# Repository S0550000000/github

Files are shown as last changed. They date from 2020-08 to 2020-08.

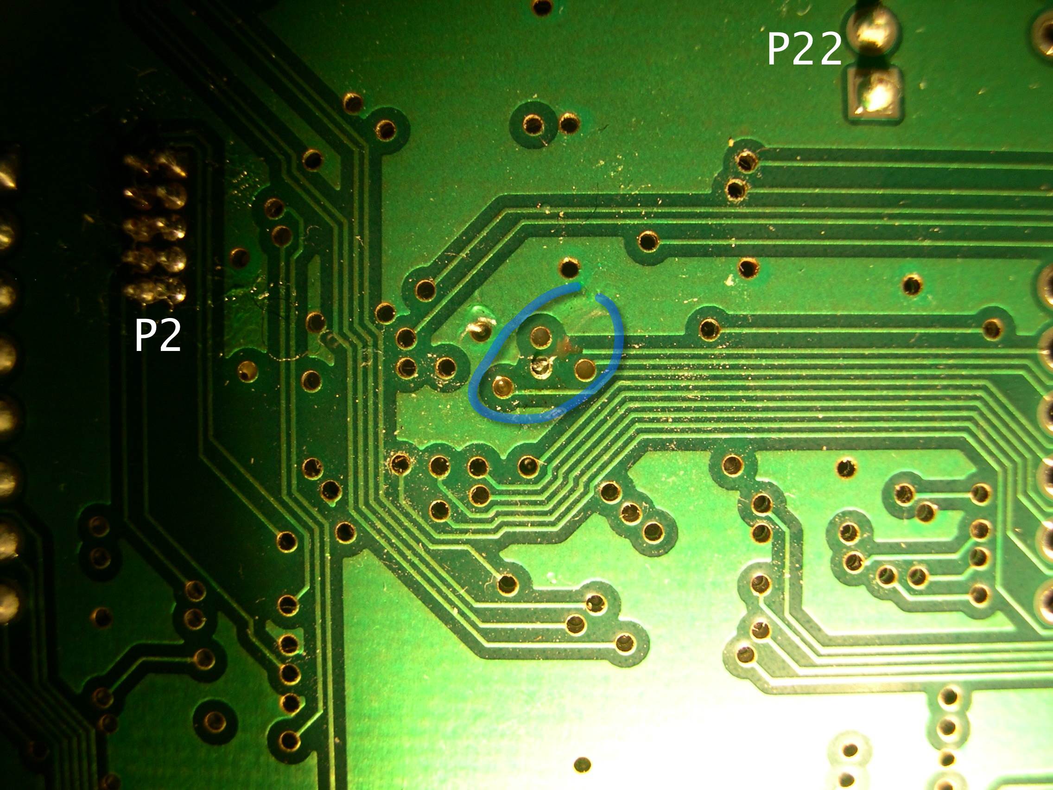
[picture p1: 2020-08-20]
doc/wiki/hardware/modifications/sgpio-p1_12-cut-trace.jpg

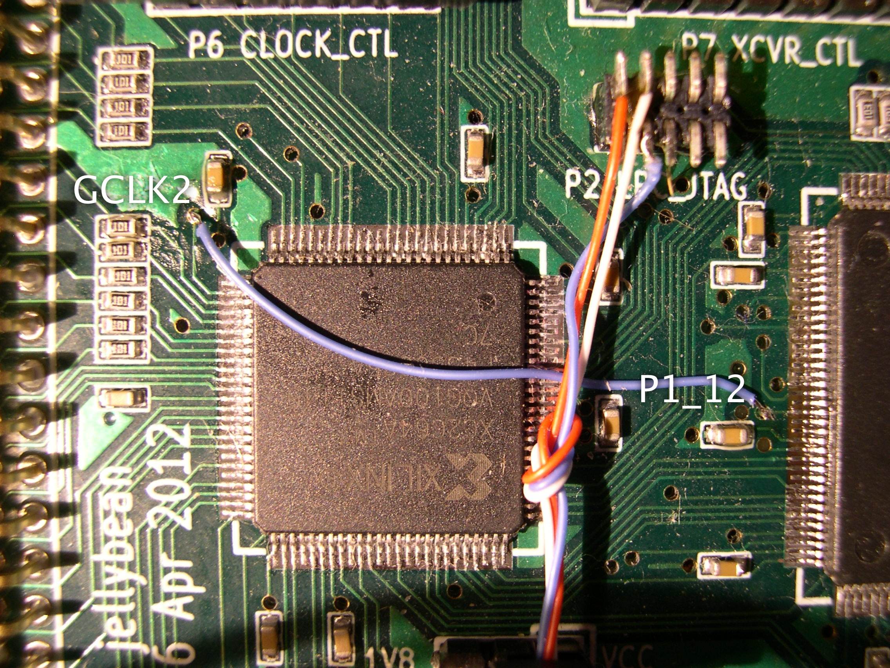
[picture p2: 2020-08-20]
doc/wiki/hardware/modifications/sgpio-gclk2-reroute.jpg

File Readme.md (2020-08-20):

This repository contains hardware designs and software for HackRF,
a low cost, open source Software Defined Radio platform.

HackRF One

(photo by fd0 from https://github.com/fd0/hackrf-one-pictures)

principal author: Michael Ossmann <mike@ossmann.com>

http://greatscottgadgets.com/hackrf/

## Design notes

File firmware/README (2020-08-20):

The primary firmware source code for USB HackRF devices is hackrf_usb.  Most of
the other directories contain firmware source code for test and development.
The common directory contains source code shared by multiple HackRF firmware
projects.  The cpld directory contains HDL source for the CPLD.

The firmware is set up for compilation with the GCC toolchain available here:

https://developer.arm.com/open-source/gnu-toolchain/gnu-rm/downloads

Required dependency:

https://github.com/mossmann/libopencm3

If you are using git, the preferred way to install libopencm3 is to use the
submodule:

$ cd ..
$ git submodule init
$ git submodule update

To build and install a standard firmware image for HackRF One:

$ cd hackrf_usb
$ mkdir build
$ cd build
$ cmake ..
$ make
$ hackrf_spiflash -w hackrf_usb.bin

If you have a Jawbreaker, add -DBOARD=JAWBREAKER to the cmake command.
If you have a rad1o, use -DBOARD=RAD1O instead.

It is possible to use a USB Device Firmware Upgrade (DFU) method to load
firmware into RAM.  This is normally only required to recover a device that has
had faulty firmware loaded, but it can also be useful for firmware developers.

For loading firmware into RAM with DFU you will need:

http://dfu-util.sourceforge.net/

To start up HackRF One in DFU mode, hold down the DFU button while powering it
on or while pressing and releasing the RESET button.  Release the DFU button
after the 3V3 LED illuminates.

A .dfu file is built by default when building firmware.  Alternatively you can
use a known good .dfu file from a release package.  Load the firmware into RAM
with:

$ dfu-util --device 1fc9:000c --alt 0 --download hackrf_usb.dfu

It is important to update the CPLD whenever you are updating firmware and a new
CPLD image is available.  See cpld/README for instructions.

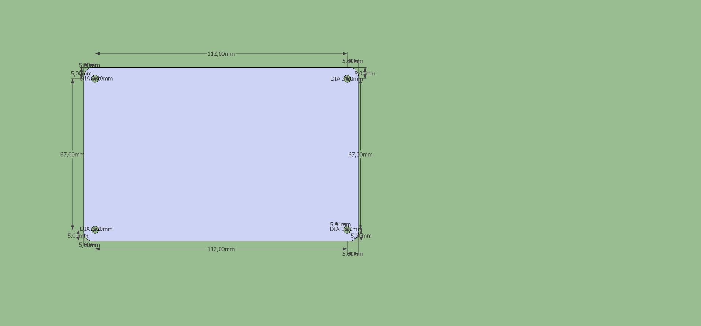
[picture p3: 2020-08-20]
hardware/hackrf-one/SoBv1_HackRF_One_16Janv2014/SoBv1_HackRF_One_Bottom2D.png

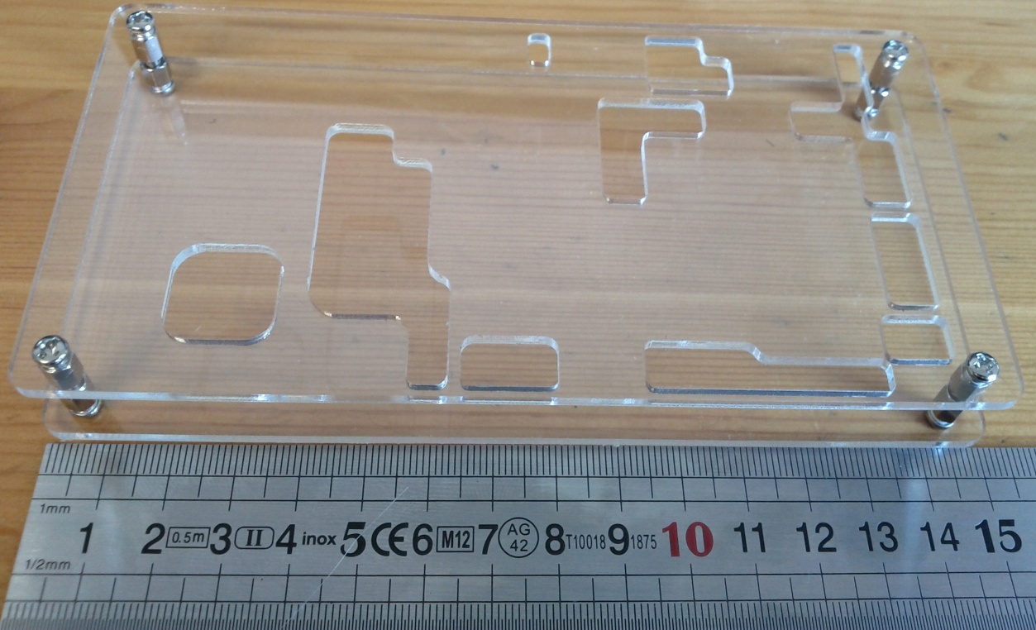
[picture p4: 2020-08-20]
hardware/jawbreaker/SoBv1_DP17298/SoBv1-DP17298-jawbreaker.jpg

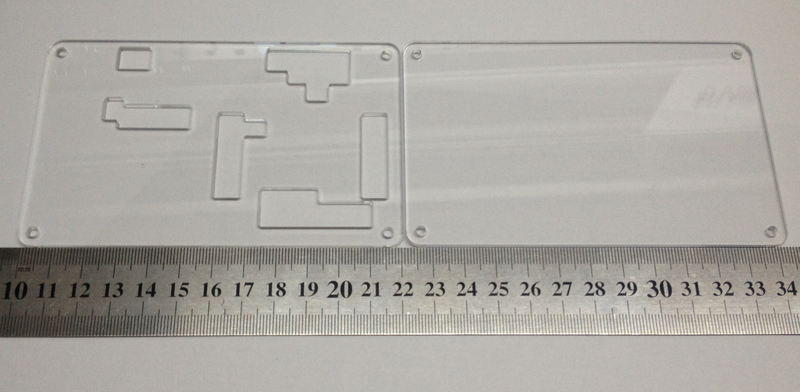
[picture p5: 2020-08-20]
hardware/hackrf-one/PlasticCase_CAD/HackRF_One_Case.png

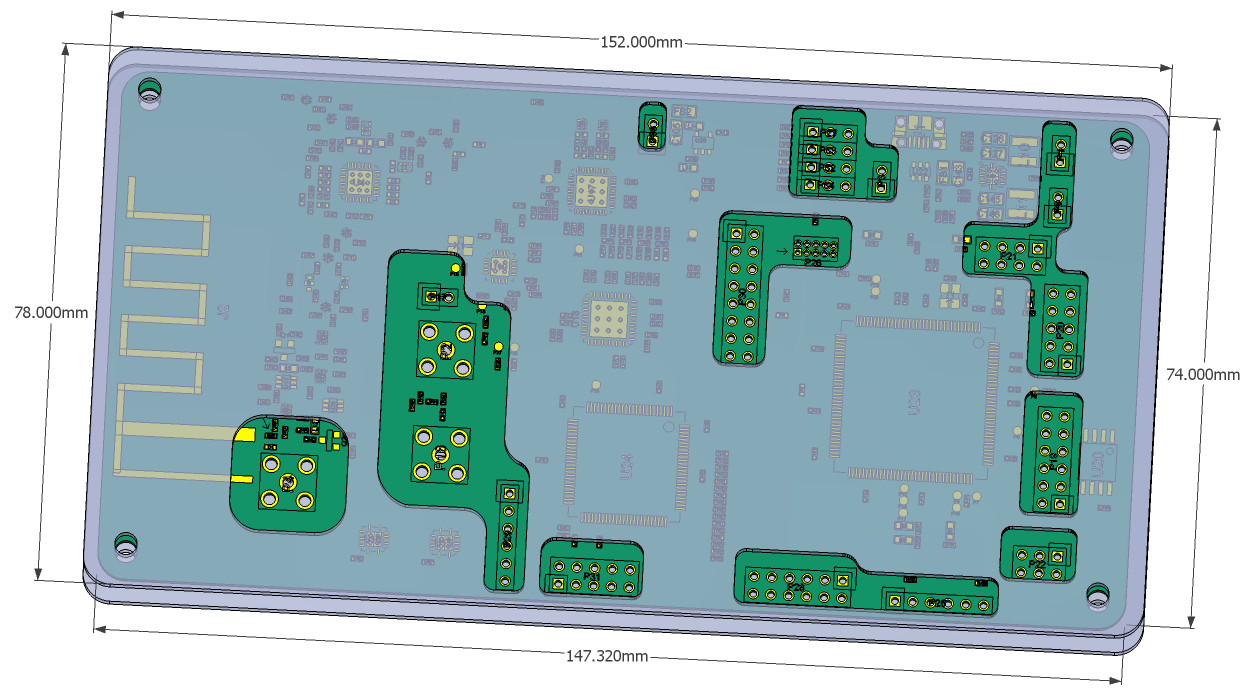
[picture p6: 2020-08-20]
hardware/jawbreaker/SoBv1_DP17298/jawbreaker_and_case.png

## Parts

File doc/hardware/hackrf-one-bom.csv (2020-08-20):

Item | Qty | Reference(s) | Value | LibPart | Footprint | Datasheet | Description | Manufacturer | Part Number
1 | 33 | C1, C3, C5, C7, C10, C11, C16, C19, C22, C24, C29, C30, C33, C34, C35, C36, C37, C38, C39, C40, C45, C47, C54, C55, C56, C57, C60, C63, C65, C66, C67, C115, C125 | 33pF | device:C |  |  | CAP CER 33PF 50V 5% NP0 0402 | Murata | GRM1555C1H330JA01D
2 | 3 | C97, C98, C100 | 330nF | device:C |  |  | CAP CER 0.33UF 10V 10% X5R 0402 | Murata | GRM155R61A334KE15D
3 | 12 | C8, C21, C32, C43, C48, C51, C84, C85, C86, C94, C99, C102 | 22pF | device:C |  |  | CAP CER 22PF 50V 5% NP0 0402 | Murata | GRM1555C1H220JA01D
4 | 2 | C104, C111 | 3pF | device:C |  |  | CAP CER 3PF 50V NP0 0402 | Murata | GRM1555C1H3R0CA01D
5 | 6 | C105, C126, C127, C143, C145, C146 | 10uF | device:C |  |  | CAP CER 10UF 10V 10% X5R 0805 | Murata | GRM21BR61A106KE19L
6 | 4 | C53, C106, C161, C171 | 1uF | device:C |  |  | CAP CER 1UF 10V 10% X5R 0402 | Taiyo Yuden | LMK105BJ105KV-F
7 | 2 | C15, C112 | 180pF | device:C |  |  | CAP CER 180PF 50V 5% NP0 0402 | Murata | GRM1555C1H181JA01D
8 | 57 | C9, C17, C18, C20, C23, C25, C28, C31, C44, C46, C49, C50, C58, C59, C61, C62, C64, C71, C73, C75, C77, C79, C81, C83, C91, C113, C119, C120, C121, C122, C123, C128, C129, C130, C131, C132, C133, C134, C135, C136, C137, C138, C139, C140, C141, C142, C144, C147, C148, C149, C150, C151, C152, C153, C154, C166, C167 | 100nF | device:C |  |  | CAP CER 0.1UF 10V 10% X5R 0402 | Murata | GRM155R61A104KA01D
9 | 1 | C114 | 3.3nF | device:C |  |  | CAP CER 3300PF 50V 10% X7R 0402 | Murata | GRM155R71H332KA01D
10 | 3 | C26, C27, C116 | 47pF | device:C |  |  | CAP CER 47PF 50V 5% NP0 0402 | Murata | GRM1555C1H470JA01D
11 | 4 | C118, C157, C158, C164 | 18pF | device:C |  |  | CAP CER 18PF 50V 5% NP0 0402 | Murata | GRM1555C1H180JA01D
12 | 2 | C12, C13 | 330pF | device:C |  |  | CAP CER 330PF 50V 10% X7R 0402 | Murata | GRM155R71H331KA01D
13 | 7 | C72, C74, C76, C78, C80, C82, C124 | 2.2uF | device:C |  |  | CAP CER 2.2UF 10V 20% X5R 0402 | Taiyo Yuden | LMK105BJ225MV-F
14 | 1 | C14 | 8p2 | device:C |  |  | CAP CER 8.2PF 50V NP0 0402 | Taiyo Yuden | UMK105CG8R2DV-F
15 | 6 | C41, C42, C52, C70, C90, C160 | 100pF | device:C |  |  | CAP CER 100PF 50V 5% NP0 0402 | Murata | GRM1555C1H101JA01D
16 | 10 | C2, C4, C6, C87, C88, C89, C92, C93, C162, C163 | 10nF | device:C |  |  | CAP CER 10000PF 16V 10% X7R 0402 | Murata | GRM155R71C103KA01D
17 | 3 | D1, D3, D9 | GSG-DIODE-TVS-BI | hackrf:GSG-DIODE-TVS-BI |  |  | TVS DIODE ESD .05PF 15KV 0402 | Murata | LXES15AAA1-100
18 | 2 | D2, D6 | TXLED | device:LED |  |  | LED SUPR RED CLR RT ANG 0805 | Lite-On | LTST-S220KRKT
19 | 2 | D4, D7 | VCCLED | device:LED |  |  | LED GREEN CLEAR RT ANG 0805 | Lite-On | LTST-S220KGKT
20 | 2 | D5, D8 | 1V8LED | device:LED |  |  | LED YELLOW CLEAR RT ANG 0805 | Lite-On | LTST-S220KSKT
21 | 3 | FB1, FB2, FB3 | FILTER | device:FILTER |  |  | FERRITE CHIP 220 OHM 2000MA 0805 | Murata | BLM21PG221SN1D
22 | 1 | J1 | USB-MICRO-B | hackrf:GSG-USB-MICRO-B-SHIELDED |  |  | CONN RCPT REV MICRO USB TYPE B | FCI | 10103592-0001LF
23 | 2 | L10, L11 | 4u7 | device:INDUCTOR |  |  | INDUCTOR 4.7UH 1.6A 20% SMD | Taiyo Yuden | NRG4026T4R7M
24 | 5 | L2, L3, L5, L12, L13 | 10uH | device:INDUCTOR |  |  | INDUCTR 10UH 220MA 20% 0603 SMD | Taiyo Yuden | BRL1608T100M
25 | 1 | L7 | 6.2nH | device:INDUCTOR |  |  | INDUCTOR HIFREQ 6.2+/-0.3NH 0402 | Taiyo Yuden | HK10056N2S-T
26 | 3 | P2, P4, P16 | ANTENNA | hackrf:GSG-RF-CONN |  |  | CONN SMA JACK 50 OHM EDGE MNT W/JAM NUT & LOCK WASHER | Molex | 73251-2121
27 | 2 | P20, P28 | SD | hackrf:CONN_11X2 |  |  | CONN HEADER FMAL 22PS.1" DL GOLD | Sullins | PPPC112LFBN-RC
28 | 1 | P22 | I2S | hackrf-one-cache:CONN_13X2 |  |  | CONN HEADER FMAL 26PS.1" DL GOLD | Sullins | PPPC132LFBN-RC
29 | 1 | P9 | BASEBAND | hackrf-one-cache:CONN_8X2 |  |  | CONN HEADER FMAL 16PS.1" DL GOLD | Sullins | PPPC082LFBN-RC
30 | 3 | Q1, Q2, Q4 | MOSFET_P | hackrf-one-cache:MOSFET_P |  |  | MOSFET P-CH 50V 130MA SOT-23 | Fairchild | BSS84
31 | 1 | Q3 | MOSFET_P | hackrf-one-cache:MOSFET_P |  |  | MOSFET P-CH 20V 4.2A SOT-23 | Diodes Inc. | DMP2305U-7
32 | 1 | Q5 | MOSFET_P | hackrf-one-cache:MOSFET_P |  |  | MOSFET P-CH -30V -4.3A SOT23 | Alpha and Omega | AO3407A
33 | 6 | R1, R2, R25, R26, R72, R75 | 470 | device:R |  |  | RES TF 1/16W 470 OHM 5% 0402 | Stackpole | RMCF0402JT470R
34 | 6 | R8, R9, R10, R13, R73, R76 | 1k | device:R |  |  | RES 1K OHM 1/16W 1% 0402 | Stackpole | RMCF0402FT1K00
35 | 22 | R19, R30, R31, R32, R33, R34, R77, R78, R79, R80, R81, R86, R87, R88, R89, R90, R91, R94, R96, R98, R99, R100 | 39 | device:R |  |  | RES 39 OHM 1/16W 5% 0402 SMD | Stackpole | RMCF0402JT39R0
36 | 26 | R5, R6, R7, R11, R12, R24, R29, R36, R37, R41, R48, R49, R51, R52, R54, R59, R63, R64, R65, R66, R67, R68, R85, R93, R104, R105 | 10k | device:R |  |  | RES 10K OHM 1/16W 5% 0402 SMD | Stackpole | RMCF0402JT10K0
37 | 4 | R14, R15, R16, R17 | 4k7 | device:R |  |  | RES 4.7K OHM 1/16W 1% 0402 | Stackpole | RMCF0402FT4K70
38 | 4 | R18, R27, R28, R74 | 1k8 | device:R |  |  | RES TF 1.8K OHM 5% 1/16W 0402 | Stackpole | RMCF0402JT1K80
39 | 7 | R20, R21, R22, R23, R57, R58, R62 | 0 | device:R |  |  | RES 0.0 OHM 1/16W 0402 SMD | Stackpole | RMCF0402ZT0R00
40 | 1 | R3 | 22k | device:R |  |  | RES 22K OHM 1/10W 5% 0402 SMD | Panasonic | ERJ-2GEJ223X
41 | 1 | R4 | 51k | device:R |  |  | RES TF 51K OHM 1% 0.0625W 0402 | Stackpole | RMCF0402FT51K0
42 | 2 | R46, R55 | 162k | device:R |  |  | RES TF 1/16W 162K OHM 1% 0402 | Stackpole | RMCF0402FT162K
43 | 1 | R47 | 330k | device:R |  |  | RES TF 1/16W 330K OHM 1% 0402 | Stackpole | RMCF0402FT330K
44 | 1 | R56 | 715k | device:R |  |  | RES TF 1/16W 715K OHM 1% 0402 | Stackpole | RMCF0402FT715K
45 | 1 | R69 | 12k | device:R |  |  | RES 12.0K OHM 1/16W 1% 0402 SMD | Rohm | MCR01MRTF1202
46 | 2 | SW1, SW2 | RESET | hackrf:SW_PUSH_SHIELDED |  |  | SWITCH TACTILE SPST-NO 0.05A 12V | TE Connectivity | FSMRA3JH
47 | 2 | T1, T2 | MIX_OUT_BALUN | hackrf:BALUN-B0310J50100AHF |  |  | Ultra Low Profile 0805 Balun 50 to 100 ohm Balanced | Anaren | B0310J50100AHF
48 | 2 | T3, T4 | TX_BALUN | hackrf:BALUN |  |  | BALUN CERAMIC CHIP WIMAX 2.5GHZ | Johanson Technology | 2500BL14M100T
49 | 7 | U1, U2, U5, U6, U7, U10, U11 | SKY13350 | hackrf:SKY13350 |  |  | 0.01-6.0 GHz GaAs SPDT Switch | Skyworks | SKY13350-385LF
50 | 3 | U9, U12, U14 | SKY13317 | hackrf:SKY13317 |  |  | 20 MHz-6.0 GHz pHEMT GaAs SP3T Switch | Skyworks | SKY13317-373LF
51 | 2 | U13, U25 | MGA-81563 | hackrf:MGA-81563 |  |  | 0.1-6 GHz 3 V, 14 dBm Amplifier | Avago | MGA-81563-TR1G
52 | 1 | U15 | LXES1TBCC2-004 | hackrf:LXES1TBCC2-004 |  |  | ESD Suppressors 0.55pF 6V 2ch | Murata | LXES1TBCC2-004
53 | 1 | U17 | MAX2837 | hackrf:MAX2837 |  |  | IC TXRX 2.3GHZ-2.7GHZ 48TQFN | Maxim | MAX2837ETM+
54 | 1 | U18 | MAX5864 | hackrf:MAX5864 |  |  | IC ANLG FRONT END 22MSPS 48-TQFN | Maxim | MAX5864ETM+
55 | 1 | U19 | SI5351C | hackrf:SI5351C |  |  | IC CLK GENERATOR 160MHZ 20QFN | Silicon Laboratories Inc | SI5351C-B-GM
56 | 1 | U20 | W25Q80BV | hackrf:W25Q80BV |  |  | IC FLASH 8MBIT 8SOIC | Winbond | W25Q80BVSSIG
57 | 1 | U21 | TPS62410 | hackrf:TPS62410 |  |  | IC BUCK SYNC DUAL ADJ 0.8A 10SON | Texas Instruments | TPS62410DRCR
58 | 1 | U23 | LPC4320FBD144 | hackrf:LPC43XXFBD144 |  |  | IC MCU 32BIT 144LQFP | NXP | LPC4320FBD144,551
59 | 1 | U24 | GSG-XC2C64A-7VQG100C | hackrf:GSG-XC2C64A-7VQG100C |  |  | IC CR-II CPLD 64MCELL 100-VQFP | Xilinx | XC2C64A-7VQG100C
60 | 1 | U3 | RX_LOWPASS_FILTER | hackrf:FIL-LP0603 |  |  | FILTER LOW PASS 1880MHZ 0603 SMD | AVX | LP0603A1880ANTR
61 | 1 | U4 | RFFC5072 | hackrf:RFFC5072 |  |  | WIDEBAND SYNTHESIZER/VCO WITH INTEGRATED 6GHz MIXER | RFMD | RFFC5072TR7
62 | 1 | U8 | RX_HIGHPASS_FILTER | hackrf:FIL-DEA |  |  | FILTER HIGHPASS WLAN&BLUETOOTH | TDK | DEA162400HT-8004B1
63 | 1 | X1 | GSG-XTAL4PIN | hackrf:GSG-XTAL4PIN |  |  | CRYSTAL 25.000MHZ 8PF SMD | AVX | CX3225GB25000D0HEQZ1
64 | 1 | X2 | MCU_XTAL | hackrf:GSG-XTAL4PIN |  |  | CRYSTAL 12.000 MHZ 12PF SMD | TXC | 7V-12.000MAAE-T
65 | 1 | X3 | RTC_XTAL | hackrf-one-cache:CRYSTAL |  |  | CRYSTAL 32.768KHZ 12.5PF SMD | Abracon | AB26TRQ-32.768KHZ-T

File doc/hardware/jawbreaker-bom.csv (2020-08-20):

ref | value | Field1 | Field2 | Field3 | Field4 | Field5 | Field6 | Field7 | Field8
C1 | 33pF | Murata | GRM1555C1H330JZ01D | CAP CER 33PF 50V 5% NP0 0402
C2 | 10nF | Murata | GRM155R71C103KA01D | CAP CER 10000PF 16V 10% X7R 0402
C3 | 33pF | Murata | GRM1555C1H330JZ01D | CAP CER 33PF 50V 5% NP0 0402
C4 | 10nF | Murata | GRM155R71C103KA01D | CAP CER 10000PF 16V 10% X7R 0402
C5 | 33pF | Murata | GRM1555C1H330JZ01D | CAP CER 33PF 50V 5% NP0 0402
C6 | 10nF | Murata | GRM155R71C103KA01D | CAP CER 10000PF 16V 10% X7R 0402
C7 | 33pF | Murata | GRM1555C1H330JZ01D | CAP CER 33PF 50V 5% NP0 0402
C8 | 47pF | Murata | GRM1555C1H470JZ01D | CAP CER 47PF 50V 5% NP0 0402
C9 | 10nF | Murata | GRM155R71C103KA01D | CAP CER 10000PF 16V 10% X7R 0402
C10 | 33pF | Murata | GRM1555C1H330JZ01D | CAP CER 33PF 50V 5% NP0 0402
C11 | 33pF | Murata | GRM1555C1H330JZ01D | CAP CER 33PF 50V 5% NP0 0402
C12 | 330pF | Murata | GRM155R71H331KA01D | CAP CER 330PF 50V 10% X7R 0402
C13 | 330pF | Murata | GRM155R71H331KA01D | CAP CER 330PF 50V 10% X7R 0402
C14 | 8p2 | Taiyo Yuden | UMK105CG8R2DV-F | CAP CER 8.2PF 50V NP0 0402
C15 | 180pF | Murata | GRM1555C1H181JA01D | CAP CER 180PF 50V 5% NP0 0402
C16 | 33pF | Murata | GRM1555C1H330JZ01D | CAP CER 33PF 50V 5% NP0 0402
C17 | 10nF | Murata | GRM155R71C103KA01D | CAP CER 10000PF 16V 10% X7R 0402
C18 | 10nF | Murata | GRM155R71C103KA01D | CAP CER 10000PF 16V 10% X7R 0402
C19 | 33pF | Murata | GRM1555C1H330JZ01D | CAP CER 33PF 50V 5% NP0 0402
C20 | 10nF | Murata | GRM155R71C103KA01D | CAP CER 10000PF 16V 10% X7R 0402
C21 | 47pF | Murata | GRM1555C1H470JZ01D | CAP CER 47PF 50V 5% NP0 0402
C22 | 33pF | Murata | GRM1555C1H330JZ01D | CAP CER 33PF 50V 5% NP0 0402
C23 | 10nF | Murata | GRM155R71C103KA01D | CAP CER 10000PF 16V 10% X7R 0402
C24 | 33pF | Murata | GRM1555C1H330JZ01D | CAP CER 33PF 50V 5% NP0 0402
C25 | 10nF | Murata | GRM155R71C103KA01D | CAP CER 10000PF 16V 10% X7R 0402
C26 | 47pF | Murata | GRM1555C1H470JZ01D | CAP CER 47PF 50V 5% NP0 0402
C27 | 47pF | Murata | GRM1555C1H470JZ01D | CAP CER 47PF 50V 5% NP0 0402
C28 | 10nF | Murata | GRM155R71C103KA01D | CAP CER 10000PF 16V 10% X7R 0402
C29 | 33pF | Murata | GRM1555C1H330JZ01D | CAP CER 33PF 50V 5% NP0 0402
C30 | 33pF | Murata | GRM1555C1H330JZ01D | CAP CER 33PF 50V 5% NP0 0402
C31 | 10nF | Murata | GRM155R71C103KA01D | CAP CER 10000PF 16V 10% X7R 0402
C32 | 47pF | Murata | GRM1555C1H470JZ01D | CAP CER 47PF 50V 5% NP0 0402
C33 | 33pF | Murata | GRM1555C1H330JZ01D | CAP CER 33PF 50V 5% NP0 0402
C34 | 33pF | Murata | GRM1555C1H330JZ01D | CAP CER 33PF 50V 5% NP0 0402
C35 | 33pF | Murata | GRM1555C1H330JZ01D | CAP CER 33PF 50V 5% NP0 0402
C36 | 33pF | Murata | GRM1555C1H330JZ01D | CAP CER 33PF 50V 5% NP0 0402
C37 | 33pF | Murata | GRM1555C1H330JZ01D | CAP CER 33PF 50V 5% NP0 0402
C38 | 33pF | Murata | GRM1555C1H330JZ01D | CAP CER 33PF 50V 5% NP0 0402
C39 | 33pF | Murata | GRM1555C1H330JZ01D | CAP CER 33PF 50V 5% NP0 0402
C40 | 33pF | Murata | GRM1555C1H330JZ01D | CAP CER 33PF 50V 5% NP0 0402
C41 | 100pF | Murata | GRM1555C1H101JZ01D | CAP CER 100PF 50V 5% NP0 0402
C42 | 100pF | Murata | GRM1555C1H101JZ01D | CAP CER 100PF 50V 5% NP0 0402
C43 | 47pF | Murata | GRM1555C1H470JZ01D | CAP CER 47PF 50V 5% NP0 0402
C44 | 10nF | Murata | GRM155R71C103KA01D | CAP CER 10000PF 16V 10% X7R 0402
C45 | 33pF | Murata | GRM1555C1H330JZ01D | CAP CER 33PF 50V 5% NP0 0402
C46 | 10nF | Murata | GRM155R71C103KA01D | CAP CER 10000PF 16V 10% X7R 0402
C47 | 33pF | Murata | GRM1555C1H330JZ01D | CAP CER 33PF 50V 5% NP0 0402
C48 | 47pF | Murata | GRM1555C1H470JZ01D | CAP CER 47PF 50V 5% NP0 0402
C49 | 10nF | Murata | GRM155R71C103KA01D | CAP CER 10000PF 16V 10% X7R 0402
C50 | 100pF | Murata | GRM1555C1H101JZ01D | CAP CER 100PF 50V 5% NP0 0402
C51 | 47pF | Murata | GRM1555C1H470JZ01D | CAP CER 47PF 50V 5% NP0 0402
C52 | 100pF | Murata | GRM1555C1H101JZ01D | CAP CER 100PF 50V 5% NP0 0402
C53 | 1uF | Taiyo Yuden | LMK105BJ105KV-F | CAP CER 1UF 10V 10% X5R 0402
C54 | 33pF | Murata | GRM1555C1H330JZ01D | CAP CER 33PF 50V 5% NP0 0402
C55 | 33pF | Murata | GRM1555C1H330JZ01D | CAP CER 33PF 50V 5% NP0 0402
C56 | 33pF | Murata | GRM1555C1H330JZ01D | CAP CER 33PF 50V 5% NP0 0402
C57 | 33pF | Murata | GRM1555C1H330JZ01D | CAP CER 33PF 50V 5% NP0 0402
C58 | 100pF | Murata | GRM1555C1H101JZ01D | CAP CER 100PF 50V 5% NP0 0402
C59 | 100pF | Murata | GRM1555C1H101JZ01D | CAP CER 100PF 50V 5% NP0 0402
C60 | 33pF | Murata | GRM1555C1H330JZ01D | CAP CER 33PF 50V 5% NP0 0402
C61 | 10nF | Murata | GRM155R71C103KA01D | CAP CER 10000PF 16V 10% X7R 0402
C62 | 100pF | Murata | GRM1555C1H101JZ01D | CAP CER 100PF 50V 5% NP0 0402
C63 | 33pF | Murata | GRM1555C1H330JZ01D | CAP CER 33PF 50V 5% NP0 0402
C64 | 10nF | Murata | GRM155R71C103KA01D | CAP CER 10000PF 16V 10% X7R 0402
C65 | 33pF | Murata | GRM1555C1H330JZ01D | CAP CER 33PF 50V 5% NP0 0402
C66 | 33pF | Murata | GRM1555C1H330JZ01D | CAP CER 33PF 50V 5% NP0 0402
C67 | 47pF | Murata | GRM1555C1H470JZ01D | CAP CER 47PF 50V 5% NP0 0402
C68 | 100nF | Murata | GRM155R61A104KA01D | CAP CER 0.1UF 10V 10% X5R 0402
C69 | 100nF | Murata | GRM155R61A104KA01D | CAP CER 0.1UF 10V 10% X5R 0402
C70 | 47pF | Murata | GRM1555C1H470JZ01D | CAP CER 47PF 50V 5% NP0 0402
C71 | 100nF | Murata | GRM155R61A104KA01D | CAP CER 0.1UF 10V 10% X5R 0402
C72 | 2.2uF | Taiyo Yuden | LMK105BJ225MV-F | CAP CER 2.2UF 10V 20% X5R 0402
C73 | 100nF | Murata | GRM155R61A104KA01D | CAP CER 0.1UF 10V 10% X5R 0402
C74 | 2.2uF | Taiyo Yuden | LMK105BJ225MV-F | CAP CER 2.2UF 10V 20% X5R 0402
C75 | 100nF | Murata | GRM155R61A104KA01D | CAP CER 0.1UF 10V 10% X5R 0402
C76 | 2.2uF | Taiyo Yuden | LMK105BJ225MV-F | CAP CER 2.2UF 10V 20% X5R 0402
C77 | 100nF | Murata | GRM155R61A104KA01D | CAP CER 0.1UF 10V 10% X5R 0402
C78 | 2.2uF | Taiyo Yuden | LMK105BJ225MV-F | CAP CER 2.2UF 10V 20% X5R 0402
C79 | 100nF | Murata | GRM155R61A104KA01D | CAP CER 0.1UF 10V 10% X5R 0402
C80 | 2.2uF | Taiyo Yuden | LMK105BJ225MV-F | CAP CER 2.2UF 10V 20% X5R 0402
C81 | 100nF | Murata | GRM155R61A104KA01D | CAP CER 0.1UF 10V 10% X5R 0402
C82 | 2.2uF | Taiyo Yuden | LMK105BJ225MV-F | CAP CER 2.2UF 10V 20% X5R 0402
C83 | 100nF | Murata | GRM155R61A104KA01D | CAP CER 0.1UF 10V 10% X5R 0402
C84 | 22pF | Murata | GRM1555C1H220JA01D | CAP CER 22PF 50V 5% NP0 0402
C85 | 22pF | Murata | GRM1555C1H220JA01D | CAP CER 22PF 50V 5% NP0 0402
C86 | 22pF | Murata | GRM1555C1H220JA01D | CAP CER 22PF 50V 5% NP0 0402
C87 | 10nF | Murata | GRM155R71C103KA01D | CAP CER 10000PF 16V 10% X7R 0402
C88 | 10nF | Murata | GRM155R71C103KA01D | CAP CER 10000PF 16V 10% X7R 0402
C89 | 10nF | Murata | GRM155R71C103KA01D | CAP CER 10000PF 16V 10% X7R 0402
C90 | 100pF | Murata | GRM1555C1H101JZ01D | CAP CER 100PF 50V 5% NP0 0402
C91 | 100nF | Murata | GRM155R61A104KA01D | CAP CER 0.1UF 10V 10% X5R 0402
C92 | 10nF | Murata | GRM155R71C103KA01D | CAP CER 10000PF 16V 10% X7R 0402
C93 | 10nF | Murata | GRM155R71C103KA01D | CAP CER 10000PF 16V 10% X7R 0402
C94 | 22pF | Murata | GRM1555C1H220JA01D | CAP CER 22PF 50V 5% NP0 0402
C95 | 22pF | Murata | GRM1555C1H220JA01D | CAP CER 22PF 50V 5% NP0 0402 | DNP
C96 | 22pF | Murata | GRM1555C1H220JA01D | CAP CER 22PF 50V 5% NP0 0402 | DNP
C97 | 330nF | Murata | GRM155R61A334KE15D | CAP CER 0.33UF 10V 10% X5R 0402
C98 | 330nF | Murata | GRM155R61A334KE15D | CAP CER 0.33UF 10V 10% X5R 0402
C99 | 22pF | Murata | GRM1555C1H220JA01D | CAP CER 22PF 50V 5% NP0 0402
C100 | 330nF | Murata | GRM155R61A334KE15D | CAP CER 0.33UF 10V 10% X5R 0402
C101 | 22pF | Murata | GRM1555C1H220JA01D | CAP CER 22PF 50V 5% NP0 0402 | DNP
C102 | 22pF | Murata | GRM1555C1H220JA01D | CAP CER 22PF 50V 5% NP0 0402
C103 | 22pF | Murata | GRM1555C1H220JA01D | CAP CER 22PF 50V 5% NP0 0402 | DNP
C104 | 3pF | Murata | GRM1555C1H3R0CA01D | CAP CER 3PF 50V NP0 0402
C105 | 10uF | Murata | GRM21BR61A106KE19L | CAP CER 10UF 10V 10% X5R 0805
C106 | 1uF | Taiyo Yuden | LMK105BJ105KV-F | CAP CER 1UF 10V 10% X5R 0402
C107 | 22pF | Murata | GRM1555C1H220JA01D | CAP CER 22PF 50V 5% NP0 0402 | DNP
C108 | 22pF | Murata | GRM1555C1H220JA01D | CAP CER 22PF 50V 5% NP0 0402 | DNP
C109 | 22pF | Murata | GRM1555C1H220JA01D | CAP CER 22PF 50V 5% NP0 0402 | DNP
C110 | 22pF | Murata | GRM1555C1H220JA01D | CAP CER 22PF 50V 5% NP0 0402 | DNP
C111 | 3pF | Murata | GRM1555C1H3R0CA01D | CAP CER 3PF 50V NP0 0402
C112 | 180pF | Murata | GRM1555C1H181JA01D | CAP CER 180PF 50V 5% NP0 0402
C113 | 100nF | Murata | GRM155R61A104KA01D | CAP CER 0.1UF 10V 10% X5R 0402
C114 | 3.3nF | Murata | GRM155R71H332KA01D | CAP CER 3300PF 50V 10% X7R 0402
C115 | 10nF | Murata | GRM155R71C103KA01D | CAP CER 10000PF 16V 10% X7R 0402
C116 | 100pF | Murata | GRM1555C1H101JZ01D | CAP CER 100PF 50V 5% NP0 0402
C117 | DNP | DNP
C118 | DNP | DNP
C119 | 100nF | Murata | GRM155R61A104KA01D | CAP CER 0.1UF 10V 10% X5R 0402
C120 | 100nF | Murata | GRM155R61A104KA01D | CAP CER 0.1UF 10V 10% X5R 0402
C121 | 100nF | Murata | GRM155R61A104KA01D | CAP CER 0.1UF 10V 10% X5R 0402
C122 | 100nF | Murata | GRM155R61A104KA01D | CAP CER 0.1UF 10V 10% X5R 0402
C123 | 100nF | Murata | GRM155R61A104KA01D | CAP CER 0.1UF 10V 10% X5R 0402
C124 | 2.2uF | Taiyo Yuden | LMK105BJ225MV-F | CAP CER 2.2UF 10V 20% X5R 0402
C125 | 33pF | Murata | GRM1555C1H330JZ01D | CAP CER 33PF 50V 5% NP0 0402
C126 | 10uF | Murata | GRM21BR61A106KE19L | CAP CER 10UF 10V 10% X5R 0805
C127 | 10uF | Murata | GRM21BR61A106KE19L | CAP CER 10UF 10V 10% X5R 0805
C128 | 100nF | Murata | GRM155R61A104KA01D | CAP CER 0.1UF 10V 10% X5R 0402
C129 | 100nF | Murata | GRM155R61A104KA01D | CAP CER 0.1UF 10V 10% X5R 0402
C130 | 100nF | Murata | GRM155R61A104KA01D | CAP CER 0.1UF 10V 10% X5R 0402
C131 | 100nF | Murata | GRM155R61A104KA01D | CAP CER 0.1UF 10V 10% X5R 0402
C132 | 100nF | Murata | GRM155R61A104KA01D | CAP CER 0.1UF 10V 10% X5R 0402
C133 | 100nF | Murata | GRM155R61A104KA01D | CAP CER 0.1UF 10V 10% X5R 0402
C134 | 100nF | Murata | GRM155R61A104KA01D | CAP CER 0.1UF 10V 10% X5R 0402
C135 | 100nF | Murata | GRM155R61A104KA01D | CAP CER 0.1UF 10V 10% X5R 0402
C136 | 100nF | Murata | GRM155R61A104KA01D | CAP CER 0.1UF 10V 10% X5R 0402
C137 | 100nF | Murata | GRM155R61A104KA01D | CAP CER 0.1UF 10V 10% X5R 0402
C138 | 100nF | Murata | GRM155R61A104KA01D | CAP CER 0.1UF 10V 10% X5R 0402
C139 | 100nF | Murata | GRM155R61A104KA01D | CAP CER 0.1UF 10V 10% X5R 0402
C140 | 100nF | Murata | GRM155R61A104KA01D | CAP CER 0.1UF 10V 10% X5R 0402
C141 | 100nF | Murata | GRM155R61A104KA01D | CAP CER 0.1UF 10V 10% X5R 0402
C142 | 100nF | Murata | GRM155R61A104KA01D | CAP CER 0.1UF 10V 10% X5R 0402
C143 | 10uF | Murata | GRM21BR61A106KE19L | CAP CER 10UF 10V 10% X5R 0805
C144 | 100nF | Murata | GRM155R61A104KA01D | CAP CER 0.1UF 10V 10% X5R 0402
C145 | 10uF | Murata | GRM21BR61A106KE19L | CAP CER 10UF 10V 10% X5R 0805
C146 | 10uF | Murata | GRM21BR61A106KE19L | CAP CER 10UF 10V 10% X5R 0805
C147 | 100nF | Murata | GRM155R61A104KA01D | CAP CER 0.1UF 10V 10% X5R 0402
C148 | 100nF | Murata | GRM155R61A104KA01D | CAP CER 0.1UF 10V 10% X5R 0402
C149 | 100nF | Murata | GRM155R61A104KA01D | CAP CER 0.1UF 10V 10% X5R 0402
C150 | 100nF | Murata | GRM155R61A104KA01D | CAP CER 0.1UF 10V 10% X5R 0402
C151 | 100nF | Murata | GRM155R61A104KA01D | CAP CER 0.1UF 10V 10% X5R 0402
C152 | 100nF | Murata | GRM155R61A104KA01D | CAP CER 0.1UF 10V 10% X5R 0402
C153 | 100nF | Murata | GRM155R61A104KA01D | CAP CER 0.1UF 10V 10% X5R 0402
C154 | 100nF | Murata | GRM155R61A104KA01D | CAP CER 0.1UF 10V 10% X5R 0402
C155 | 100pF | Murata | GRM1555C1H101JZ01D | CAP CER 100PF 50V 5% NP0 0402
C156 | 47pF | Murata | GRM1555C1H470JZ01D | CAP CER 47PF 50V 5% NP0 0402
C157 | 18pF | Murata | GRM1555C1H180JZ01D | CAP CER 18PF 50V 5% NP0 0402
C158 | 18pF | Murata | GRM1555C1H180JZ01D | CAP CER 18PF 50V 5% NP0 0402
C159 | 1uF | Murata | GRM155R61A105ME15D | CAP CER 1UF 10V 20% X5R 0402 | DNP
C160 | 100pF | Murata | GRM1555C1H101JZ01D | CAP CER 100PF 50V 5% NP0 0402
C161 | 1uF | Taiyo Yuden | LMK105BJ105KV-F | CAP CER 1UF 10V 10% X5R 0402
C162 | 10nF | Murata | GRM155R71C103KA01D | CAP CER 10000PF 16V 10% X7R 0402
C163 | 10nF | Murata | GRM155R71C103KA01D | CAP CER 10000PF 16V 10% X7R 0402
C164 | DNP | DNP
C165 | DNP | DNP
D1 | GSG-DIODE-TVS-BI | Murata | LXES15AAA1-100 | TVS DIODE ESD .05PF 15KV 0402
D2 | USBLED1 | Everlight | QTLP601C4TR | LED GREEN STD BRIGHT 0603 SMD
D3 | USBLED0 | Everlight | QTLP600CYTR | LED YLW SUPER BRIGHT 0606 SMD
D4 | LED1 | Everlight | QTLP601C4TR | LED GREEN STD BRIGHT 0603 SMD
D5 | LED2 | Everlight | QTLP600CYTR | LED YLW SUPER BRIGHT 0606 SMD
D6 | LED3 | Everlight | QTLP601CRTR | LED RED STD BRIGHT 0603 SMD
D7 | VCCLED | Everlight | QTLP601C4TR | LED GREEN STD BRIGHT 0603 SMD
D8 | 1V8LED | Everlight | QTLP600CYTR | LED YLW SUPER BRIGHT 0606 SMD
FB1 | FILTER | Murata | BLM21PG221SN1D | FERRITE CHIP 220 OHM 2000MA 0805
FB2 | FILTER | Murata | BLM21PG221SN1D | FERRITE CHIP 220 OHM 2000MA 0805
J1 | GSG-USB-MICRO-B | FCI | 10103594-0001LF | CONN RCPT STD MICRO USB TYPE B
J2 | 900MHZ-F-ANTENNA | DNP
L1 | DNP | DNP
L2 | 1uH | Taiyo Yuden | BRL1608T1R0M | INDUCTR 1.0UH 650MA 20% 0603 SMD
L3 | 1uH | Taiyo Yuden | BRL1608T1R0M | INDUCTR 1.0UH 650MA 20% 0603 SMD
L4 | DNP | DNP
L5 | 1uH | Taiyo Yuden | BRL1608T1R0M | INDUCTR 1.0UH 650MA 20% 0603 SMD
L6 | DNP | DNP
L7 | 6.2nH | Taiyo Yuden | HK10056N2S-T | INDUCTOR HIFREQ 6.2+/-0.3NH 0402
L8 | DNP | DNP
L9 | DNP | DNP
L10 | 4u7 | Taiyo Yuden | NRG4026T4R7M | INDUCTOR 4.7UH 1.6A 20% SMD
L11 | 4u7 | Taiyo Yuden | NRG4026T4R7M | INDUCTOR 4.7UH 1.6A 20% SMD
L12 | 1uH | Taiyo Yuden | BRL1608T1R0M | INDUCTR 1.0UH 650MA 20% 0603 SMD
L13 | INDUCTOR | DNP
L14 | INDUCTOR | DNP
P1 | 1V8 | DNP
P2 | CLKOUT | TE Connectivity | 2081233-1 | CONN JACK SMA PCB VERT | DNP
P3 | GND | DNP
P4 | ANTENNA | TE Connectivity | 2081233-1 | CONN JACK SMA PCB VERT
P5 | WAKEUP | DNP
P6 | TRACECLK | DNP
P7 | CTIN_4 | DNP
P8 | VCC | DNP
P9 | CTOUT_4 | DNP
P10 | CTOUT_2 | DNP
P11 | CTIN_2 | DNP
P12 | U3_RXD | DNP
P13 | U3_TXD | DNP
P14 | XCVR_CLKOUT | DNP
P15 | INTR | DNP
P16 | CLKIN | TE Connectivity | 2081233-1 | CONN JACK SMA PCB VERT | DNP
P17 | CLKIN_JMP | DNP
P18 | OEB | DNP
P19 | SPIFI | DNP
P20 | GPIO | DNP
P21 | ANALOG | DNP
P22 | I2S | DNP
P23 | DBGEN | DNP
P24 | TRST | DNP
P25 | LPC_ISP | DNP
P26 | LPC_JTAG | DNP
P27 | CONN_3 | DNP
P28 | SD | DNP
P29 | CPLD_JTAG | DNP
P30 | BANK2_AUX | DNP
P31 | BANK1_AUX | DNP
P32 | CONN_3 | DNP
P33 | CONN_3 | DNP
P34 | CONN_3 | DNP
P35 | GCK0 | DNP
P36 | VAA | DNP
P37 | SCL | DNP
P38 | SDA | DNP
P39 | SSP1_SCK | DNP
P40 | SSP1_MOSI | DNP
P41 | SSP1_MISO | DNP
Q1 | MOSFET_P | Fairchild | BSS84 | MOSFET P-CH 50V 130MA SOT-23
Q2 | MOSFET_P | Fairchild | BSS84 | MOSFET P-CH 50V 130MA SOT-23
R1 | 470 | Stackpole | RMCF0402JT470R | RES TF 1/16W 470 OHM 5% 0402
R2 | 470 | Stackpole | RMCF0402JT470R | RES TF 1/16W 470 OHM 5% 0402
R3 | 22k | Panasonic | ERJ-2GEJ223X | RES 22K OHM 1/10W 5% 0402 SMD
R4 | 51k | Stackpole | RMCF0402FT51K0 | RES TF 51K OHM 1% 0.0625W 0402
R5 | 4k7 | Stackpole | RMCF0402JT4K70 | RES 4.7K OHM 1/16W 5% 0402 SMD
R6 | 4k7 | Stackpole | RMCF0402JT4K70 | RES 4.7K OHM 1/16W 5% 0402 SMD
R7 | 10k | Stackpole | RMCF0402JT10K0 | RES 10K OHM 1/16W 5% 0402 SMD
R8 | 1k | Stackpole | RMCF0402JT1K00 | RES 1K OHM 1/16W 5% 0402 SMD
R9 | 1k | Stackpole | RMCF0402JT1K00 | RES 1K OHM 1/16W 5% 0402 SMD
R10 | 1k | Stackpole | RMCF0402JT1K00 | RES 1K OHM 1/16W 5% 0402 SMD
R11 | 39 | Stackpole | RMCF0402JT39R0 | RES 39 OHM 1/16W 5% 0402 SMD
R12 | 39 | Stackpole | RMCF0402JT39R0 | RES 39 OHM 1/16W 5% 0402 SMD
R13 | 1k | Stackpole | RMCF0402JT1K00 | RES 1K OHM 1/16W 5% 0402 SMD
R14 | 4k7 | Stackpole | RMCF0402JT4K70 | RES 4.7K OHM 1/16W 5% 0402 SMD
R15 | 4k7 | Stackpole | RMCF0402JT4K70 | RES 4.7K OHM 1/16W 5% 0402 SMD
R16 | 4k7 | Stackpole | RMCF0402JT4K70 | RES 4.7K OHM 1/16W 5% 0402 SMD
R17 | 4k7 | Stackpole | RMCF0402JT4K70 | RES 4.7K OHM 1/16W 5% 0402 SMD
R18 | 47 | DNP
R19 | 47 | DNP
R20 | 0 | Stackpole | RMCF0402ZT0R00 | RES 0.0 OHM 1/16W 0402 SMD
R21 | 0 | Stackpole | RMCF0402ZT0R00 | RES 0.0 OHM 1/16W 0402 SMD
R22 | 0 | Stackpole | RMCF0402ZT0R00 | RES 0.0 OHM 1/16W 0402 SMD
R23 | 0 | Stackpole | RMCF0402ZT0R00 | RES 0.0 OHM 1/16W 0402 SMD
R24 | 4k7 | Stackpole | RMCF0402JT4K70 | RES 4.7K OHM 1/16W 5% 0402 SMD
R25 | 475 | Stackpole | RMCF0402JT470R | RES TF 1/16W 470 OHM 5% 0402
R26 | 475 | Stackpole | RMCF0402JT470R | RES TF 1/16W 470 OHM 5% 0402
R27 | 1k8 | Stackpole | RMCF0402JT1K80 | RES TF 1.8K OHM 5% 1/16W 0402
R28 | 1k8 | Stackpole | RMCF0402JT1K80 | RES TF 1.8K OHM 5% 1/16W 0402
R29 | 4k7 | Stackpole | RMCF0402JT4K70 | RES 4.7K OHM 1/16W 5% 0402 SMD
R30 | 0 | DNP
R31 | 0 | DNP
R32 | 0 | DNP
R33 | 0 | DNP
R34 | 0 | DNP
R35 | 0 | DNP
R36 | 0 | DNP
R37 | 0 | DNP
R38 | 0 | DNP
R39 | 0 | DNP
R40 | 10k | Stackpole | RMCF0402JT10K0 | RES 10K OHM 1/16W 5% 0402 SMD | DNP
R41 | 4k7 | Stackpole | RMCF0402JT4K70 | RES 4.7K OHM 1/16W 5% 0402 SMD
R42 | 10k | Stackpole | RMCF0402JT10K0 | RES 10K OHM 1/16W 5% 0402 SMD | DNP
R43 | 10k | Stackpole | RMCF0402JT10K0 | RES 10K OHM 1/16W 5% 0402 SMD | DNP
R44 | 0 | DNP
R45 | DNP | DNP
R46 | 162k | Stackpole | RMCF0402FT162K | RES TF 1/16W 162K OHM 1% 0402
R47 | 330k | Stackpole | RMCF0402FT330K | RES TF 1/16W 330K OHM 1% 0402
R48 | 10k | Stackpole | RMCF0402JT10K0 | RES 10K OHM 1/16W 5% 0402 SMD
R49 | 10k | Stackpole | RMCF0402JT10K0 | RES 10K OHM 1/16W 5% 0402 SMD
R50 | DNP | DNP
R51 | 10k | Stackpole | RMCF0402JT10K0 | RES 10K OHM 1/16W 5% 0402 SMD
R52 | 10k | Stackpole | RMCF0402JT10K0 | RES 10K OHM 1/16W 5% 0402 SMD
R53 | DNP | DNP
R54 | 10k | Stackpole | RMCF0402JT10K0 | RES 10K OHM 1/16W 5% 0402 SMD
R55 | 162k | Stackpole | RMCF0402FT162K | RES TF 1/16W 162K OHM 1% 0402
R56 | 715k | Stackpole | RMCF0402FT715K | RES TF 1/16W 715K OHM 1% 0402
R57 | 0 | Stackpole | RMCF0402ZT0R00 | RES 0.0 OHM 1/16W 0402 SMD
R58 | 0 | Stackpole | RMCF0402ZT0R00 | RES 0.0 OHM 1/16W 0402 SMD
R59 | 10k | Stackpole | RMCF0402JT10K0 | RES 10K OHM 1/16W 5% 0402 SMD
R60 | 0 | DNP
R61 | 0 | DNP
R62 | 0 | Stackpole | RMCF0402ZT0R00 | RES 0.0 OHM 1/16W 0402 SMD
R63 | 10k | Stackpole | RMCF0402JT10K0 | RES 10K OHM 1/16W 5% 0402 SMD
R64 | 10k | Stackpole | RMCF0402JT10K0 | RES 10K OHM 1/16W 5% 0402 SMD
R65 | 10k | Stackpole | RMCF0402JT10K0 | RES 10K OHM 1/16W 5% 0402 SMD | DNP
R66 | 10k | Stackpole | RMCF0402JT10K0 | RES 10K OHM 1/16W 5% 0402 SMD
R67 | 10k | Stackpole | RMCF0402JT10K0 | RES 10K OHM 1/16W 5% 0402 SMD
R68 | 10k | Stackpole | RMCF0402JT10K0 | RES 10K OHM 1/16W 5% 0402 SMD
R69 | 12k | Rohm | MCR01MRTF1202 | RES 12.0K OHM 1/16W 1% 0402 SMD
R70 | 470 | Stackpole | RMCF0402JT470R | RES TF 1/16W 470 OHM 5% 0402
R71 | 470 | Stackpole | RMCF0402JT470R | RES TF 1/16W 470 OHM 5% 0402
R72 | 470 | Stackpole | RMCF0402JT470R | RES TF 1/16W 470 OHM 5% 0402
R73 | 470 | Stackpole | RMCF0402JT470R | RES TF 1/16W 470 OHM 5% 0402
R74 | 470 | Stackpole | RMCF0402JT470R | RES TF 1/16W 470 OHM 5% 0402
R75 | 470 | Stackpole | RMCF0402JT470R | RES TF 1/16W 470 OHM 5% 0402
R76 | 470 | Stackpole | RMCF0402JT470R | RES TF 1/16W 470 OHM 5% 0402
R77 | 39 | Stackpole | RMCF0402JT39R0 | RES 39 OHM 1/16W 5% 0402 SMD
R78 | 39 | Stackpole | RMCF0402JT39R0 | RES 39 OHM 1/16W 5% 0402 SMD
R79 | 39 | Stackpole | RMCF0402JT39R0 | RES 39 OHM 1/16W 5% 0402 SMD
R80 | 39 | Stackpole | RMCF0402JT39R0 | RES 39 OHM 1/16W 5% 0402 SMD
R81 | 39 | Stackpole | RMCF0402JT39R0 | RES 39 OHM 1/16W 5% 0402 SMD
R82 | 10k | Stackpole | RMCF0402JT10K0 | RES 10K OHM 1/16W 5% 0402 SMD | DNP
R83 | 0 | DNP
R84 | 50 | DNP
R85 | DNP | DNP
R86 | 39 | Stackpole | RMCF0402JT39R0 | RES 39 OHM 1/16W 5% 0402 SMD
R87 | 39 | Stackpole | RMCF0402JT39R0 | RES 39 OHM 1/16W 5% 0402 SMD
R88 | 39 | Stackpole | RMCF0402JT39R0 | RES 39 OHM 1/16W 5% 0402 SMD
R89 | 39 | Stackpole | RMCF0402JT39R0 | RES 39 OHM 1/16W 5% 0402 SMD
R90 | 39 | Stackpole | RMCF0402JT39R0 | RES 39 OHM 1/16W 5% 0402 SMD
R91 | 39 | Stackpole | RMCF0402JT39R0 | RES 39 OHM 1/16W 5% 0402 SMD
R92 | 50 | DNP
R93 | 10k | Stackpole | RMCF0402JT10K0 | RES 10K OHM 1/16W 5% 0402 SMD
R94 | 39 | Stackpole | RMCF0402JT39R0 | RES 39 OHM 1/16W 5% 0402 SMD
R96 | 39 | Stackpole | RMCF0402JT39R0 | RES 39 OHM 1/16W 5% 0402 SMD
R97 | 39 | Stackpole | RMCF0402JT39R0 | RES 39 OHM 1/16W 5% 0402 SMD | DNP
R98 | 39 | Stackpole | RMCF0402JT39R0 | RES 39 OHM 1/16W 5% 0402 SMD
R99 | 39 | Stackpole | RMCF0402JT39R0 | RES 39 OHM 1/16W 5% 0402 SMD
R100 | 39 | Stackpole | RMCF0402JT39R0 | RES 39 OHM 1/16W 5% 0402 SMD
R104 | 4k7 | Stackpole | RMCF0402JT4K70 | RES 4.7K OHM 1/16W 5% 0402 SMD
R105 | 4k7 | Stackpole | RMCF0402JT4K70 | RES 4.7K OHM 1/16W 5% 0402 SMD
T1 | MIX_IN_BALUN | Anaren | B0310J50100AHF | Ultra Low Profile 0805 Balun 50 to 100 ohm Balanced
T2 | MIX_OUT_BALUN | Anaren | B0310J50100AHF | Ultra Low Profile 0805 Balun 50 to 100 ohm Balanced
T3 | RX_BALUN | Johanson Technology | 2500BL14M100T | BALUN CERAMIC CHIP WIMAX 2.5GHZ
T4 | TX_BALUN | Johanson Technology | 2500BL14M100T | BALUN CERAMIC CHIP WIMAX 2.5GHZ
U1 | SKY13350 | Skyworks | SKY13350-385LF | 0.01-6.0 GHz GaAs SPDT Switch
U2 | SKY13350 | Skyworks | SKY13350-385LF | 0.01-6.0 GHz GaAs SPDT Switch
U3 | RX_LOWPASS_FILTER | AVX | LP0603A1880ANTR | FILTER LOW PASS 1880MHZ 0603 SMD
U4 | RFFC5072 | RFMD | RFFC5072TR7 | WIDEBAND SYNTHESIZER/VCO WITH INTEGRATED 6GHz MIXER
U5 | SKY13350 | Skyworks | SKY13350-385LF | 0.01-6.0 GHz GaAs SPDT Switch
U6 | SKY13350 | Skyworks | SKY13350-385LF | 0.01-6.0 GHz GaAs SPDT Switch
U7 | SKY13350 | Skyworks | SKY13350-385LF | 0.01-6.0 GHz GaAs SPDT Switch
U8 | RX_HIGHPASS_FILTER | TDK | DEA162400HT-8004B1 | FILTER HIGHPASS WLAN&BLUETOOTH
U9 | SKY13317 | Skyworks | SKY13317-373LF | 20 MHz-6.0 GHz pHEMT GaAs SP3T Switch
U10 | SKY13350 | Skyworks | SKY13350-385LF | 0.01-6.0 GHz GaAs SPDT Switch
U11 | SKY13350 | Skyworks | SKY13350-385LF | 0.01-6.0 GHz GaAs SPDT Switch
U12 | SKY13317 | Skyworks | SKY13317-373LF | 20 MHz-6.0 GHz pHEMT GaAs SP3T Switch
U13 | MGA-81563 | Avago | MGA-81563-TR1G | 0.1-6 GHz 3 V, 14 dBm Amplifier
U14 | SKY13317 | Skyworks | SKY13317-373LF | 20 MHz-6.0 GHz pHEMT GaAs SP3T Switch
U15 | GSG-74HC04 | Texas Instruments | SN74AHC04RGYR | IC HEX INVERTERS 14-QFN
U16 | GSG-74HC08 | Texas Instruments | SN74AHC08RGYR | IC QUAD 2IN POS-AND GATE 14-QFN
U17 | MAX2837 | Maxim | MAX2837ETM+ | IC TXRX 2.3GHZ-2.7GHZ 48TQFN
U18 | MAX5864 | Maxim | MAX5864ETM+ | IC ANLG FRONT END 22MSPS 48-TQFN
U19 | SI5351C | Silicon Laboratories Inc | SI5351C-B-GM | IC CLK GENERATOR 160MHZ 20QFN
U20 | W25Q80BV | Winbond | W25Q80BVSSIG | IC FLASH 8MBIT 8SOIC
U21 | TPS62410 | Texas Instruments | TPS62410DRCR | IC BUCK SYNC DUAL ADJ 0.8A 10SON
U22 | GSG-IP4220CZ6 | NXP | IP4220CZ6,125 | IC USB DUAL ESD PROTECT 6TSOP
U23 | LPC43XXFBD144 | NXP | LPC4330FBD144,551 | IC MCU 32BIT 144LQFP
U24 | GSG-XC2C64A-7VQG100C | Xilinx | XC2C64A-7VQG100C | IC CR-II CPLD 64MCELL 100-VQFP
U25 | MGA-81563 | Avago | MGA-81563-TR1G | 0.1-6 GHz 3 V, 14 dBm Amplifier
U26 | RF LDO | DNP
X1 | GSG-XTAL4PIN | AVX | CX3225GB25000D0HEQZ1 | CRYSTAL 25.000MHZ 8PF SMD
X2 | MCU_XTAL | TXC | 7V-12.000MAAE-T | CRYSTAL 12.000 MHZ 12PF SMD

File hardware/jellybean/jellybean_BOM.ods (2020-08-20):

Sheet: JellyBean_BOM
Ref | Value | Manufacturer | Footprint | Details | DigiKey Quantity | DigiKey PN
R1 | 0 | Panasonic | ERJ-3GEY0R00V | RES 0.0 OHM 1/10W 0603 SMD | 2 | P0.0GCT-ND
R2 | 0 | Panasonic | ERJ-3GEY0R00V | RES 0.0 OHM 1/10W 0603 SMD
R18 | 100 | Panasonic | ERJ-3GEYJ101V | RES 100 OHM 1/10W 5% 0603 SMD | 10 | P100GCT-ND
R19 | 100 | Panasonic | ERJ-3GEYJ101V | RES 100 OHM 1/10W 5% 0603 SMD
R20 | 100 | Panasonic | ERJ-3GEYJ101V | RES 100 OHM 1/10W 5% 0603 SMD
R21 | 100 | Panasonic | ERJ-3GEYJ101V | RES 100 OHM 1/10W 5% 0603 SMD
R22 | 100 | Panasonic | ERJ-3GEYJ101V | RES 100 OHM 1/10W 5% 0603 SMD
R23 | 100 | Panasonic | ERJ-3GEYJ101V | RES 100 OHM 1/10W 5% 0603 SMD
R24 | 100 | Panasonic | ERJ-3GEYJ101V | RES 100 OHM 1/10W 5% 0603 SMD
R25 | 100 | Panasonic | ERJ-3GEYJ101V | RES 100 OHM 1/10W 5% 0603 SMD
R26 | 100 | Panasonic | ERJ-3GEYJ101V | RES 100 OHM 1/10W 5% 0603 SMD
R27 | 100 | Panasonic | ERJ-3GEYJ101V | RES 100 OHM 1/10W 5% 0603 SMD
R12 | 470 | Panasonic | ERJ-3GEYJ471V | RES 470 OHM 1/10W 5% 0603 SMD | 7 | P470GCT-ND
R13 | 470 | Panasonic | ERJ-3GEYJ471V | RES 470 OHM 1/10W 5% 0603 SMD
R15 | 470 | Panasonic | ERJ-3GEYJ471V | RES 470 OHM 1/10W 5% 0603 SMD
R29 | 470 | Panasonic | ERJ-3GEYJ471V | RES 470 OHM 1/10W 5% 0603 SMD
R3 | 470 | Panasonic | ERJ-3GEYJ471V | RES 470 OHM 1/10W 5% 0603 SMD
R8 | 470 | Panasonic | ERJ-3GEYJ471V | RES 470 OHM 1/10W 5% 0603 SMD
R9 | 470 | Panasonic | ERJ-3GEYJ471V | RES 470 OHM 1/10W 5% 0603 SMD
R30 | 1k8 | Panasonic | ERJ-3GEYJ182V | RES 1.8K OHM 1/10W 5% 0603 SMD | 2 | P1.8KGCT-ND
R31 | 1k8 | Panasonic | ERJ-3GEYJ182V | RES 1.8K OHM 1/10W 5% 0603 SMD
R16 | 10k | Panasonic | ERJ-3GEYJ103V | RES 10K OHM 1/10W 5% 0603 SMD | 13 | P10KGCT-ND
R17 | 10k | Panasonic | ERJ-3GEYJ103V | RES 10K OHM 1/10W 5% 0603 SMD
R28 | 10k | Panasonic | ERJ-3GEYJ103V | RES 10K OHM 1/10W 5% 0603 SMD
R32 | 10k | Panasonic | ERJ-3GEYJ103V | RES 10K OHM 1/10W 5% 0603 SMD
R39 | 10k | Panasonic | ERJ-3GEYJ103V | RES 10K OHM 1/10W 5% 0603 SMD
R4 | 10k | Panasonic | ERJ-3GEYJ103V | RES 10K OHM 1/10W 5% 0603 SMD
R40 | 10k | Panasonic | ERJ-3GEYJ103V | RES 10K OHM 1/10W 5% 0603 SMD
R41 | 10k | Panasonic | ERJ-3GEYJ103V | RES 10K OHM 1/10W 5% 0603 SMD
R42 | 10k | Panasonic | ERJ-3GEYJ103V | RES 10K OHM 1/10W 5% 0603 SMD
R43 | 10k | Panasonic | ERJ-3GEYJ103V | RES 10K OHM 1/10W 5% 0603 SMD
R5 | 10k | Panasonic | ERJ-3GEYJ103V | RES 10K OHM 1/10W 5% 0603 SMD
R6 | 10k | Panasonic | ERJ-3GEYJ103V | RES 10K OHM 1/10W 5% 0603 SMD
R7 | 10k | Panasonic | ERJ-3GEYJ103V | RES 10K OHM 1/10W 5% 0603 SMD
R14 | 12k | Panasonic | ERJ-3EKF1202V | RES 12.0K OHM 1/10W 1% 0603 SMD | 1 | P12.0KHCT-ND
R10 | 15k | Panasonic | ERJ-3GEYJ153V | RES 15K OHM 1/10W 5% 0603 SMD | 1 | P15KGCT-ND
R11 | 33k | Panasonic | ERJ-3GEYJ333V | RES 33K OHM 1/10W 5% 0603 SMD | 1 | P33KGCT-ND
R36 | 160k+560k in parallel (to obtain 3,3V instead of 2.7V) | Panasonic | ERJ-3EKF1603V | RES 160K OHM 1/10W 1% 0603 SMD | 1 | P160KHCT-ND
R35 | 180k | Panasonic | ERJ-3EKF1803V | RES 180K OHM 1/10W 1% 0603 SMD | 1 | P180KHCT-ND
R37 | 360k | Panasonic | ERJ-3EKF3603V | RES 360K OHM 1/10W 1% 0603 SMD | 1 | P360KHCT-ND
R38 | 560k | Panasonic | ERJ-3EKF5603V | RES 560K OHM 1/10W 1% 0603 SMD | 2 | P560KHCT-ND
C24 | 22pF | Murata | GRM1885C1H220JA01D | CAP CER 22PF 50V 5% NP0 0603 | 10 | 490-1411-1-ND
C18 | 47pF | Murata | GRM1885C1H470JA01D | CAP CER 47PF 50V 5% NP0 0603 | 10 | 490-1419-1-ND
C1 | 100nF | Murata | GRM188R71C104KA01D | CAP CER 0.1UF 16V 10% X7R 0603 | 30 | 490-1532-1-ND
C10 | 100nF | Murata | GRM188R71C104KA01D | CAP CER 0.1UF 16V 10% X7R 0603
C11 | 100nF | Murata | GRM188R71C104KA01D | CAP CER 0.1UF 16V 10% X7R 0603
C12 | 100nF | Murata | GRM188R71C104KA01D | CAP CER 0.1UF 16V 10% X7R 0603
C13 | 100nF | Murata | GRM188R71C104KA01D | CAP CER 0.1UF 16V 10% X7R 0603
C14 | 100nF | Murata | GRM188R71C104KA01D | CAP CER 0.1UF 16V 10% X7R 0603
C15 | 100nF | Murata | GRM188R71C104KA01D | CAP CER 0.1UF 16V 10% X7R 0603
C17 | 100nF | Murata | GRM188R71C104KA01D | CAP CER 0.1UF 16V 10% X7R 0603
C19 | 100nF | Murata | GRM188R71C104KA01D | CAP CER 0.1UF 16V 10% X7R 0603
C2 | 100nF | Murata | GRM188R71C104KA01D | CAP CER 0.1UF 16V 10% X7R 0603
C20 | 100nF | Murata | GRM188R71C104KA01D | CAP CER 0.1UF 16V 10% X7R 0603
C22 | 100nF | Murata | GRM188R71C104KA01D | CAP CER 0.1UF 16V 10% X7R 0603
C23 | 100nF | Murata | GRM188R71C104KA01D | CAP CER 0.1UF 16V 10% X7R 0603
C25 | 100nF | Murata | GRM188R71C104KA01D | CAP CER 0.1UF 16V 10% X7R 0603
C26 | 100nF | Murata | GRM188R71C104KA01D | CAP CER 0.1UF 16V 10% X7R 0603
C29 | 100nF | Murata | GRM188R71C104KA01D | CAP CER 0.1UF 16V 10% X7R 0603
C3 | 100nF | Murata | GRM188R71C104KA01D | CAP CER 0.1UF 16V 10% X7R 0603
C32 | 100nF | Murata | GRM188R71C104KA01D | CAP CER 0.1UF 16V 10% X7R 0603
C33 | 100nF | Murata | GRM188R71C104KA01D | CAP CER 0.1UF 16V 10% X7R 0603
C4 | 100nF | Murata | GRM188R71C104KA01D | CAP CER 0.1UF 16V 10% X7R 0603
C5 | 100nF | Murata | GRM188R71C104KA01D | CAP CER 0.1UF 16V 10% X7R 0603
C7 | 100nF | Murata | GRM188R71C104KA01D | CAP CER 0.1UF 16V 10% X7R 0603
C8 | 100nF | Murata | GRM188R71C104KA01D | CAP CER 0.1UF 16V 10% X7R 0603
C9 | 100nF | Murata | GRM188R71C104KA01D | CAP CER 0.1UF 16V 10% X7R 0603
C16 | 100pF | Murata | GRM1885C1H101JA01D | CAP CER 100PF 50V 5% NP0 0603 | 10 | 490-1427-1-ND
C6 | 4u7 | Taiyo Yuden | LMK212BJ475KD-T | CAP CER 4.7UF 10V 10% X5R 0805 | 1 | 587-1297-1-ND
C21 | 10uF | Murata | GRM21BR61A106KE19L | CAP CER 10UF 10V 10% X5R 0805 | 10 | 490-1709-1-ND
C27 | 10uF | Murata | GRM21BR61A106KE19L | CAP CER 10UF 10V 10% X5R 0805
C28 | 10uF | Murata | GRM21BR61A106KE19L | CAP CER 10UF 10V 10% X5R 0805
C30 | 10uF | Murata | GRM21BR61A106KE19L | CAP CER 10UF 10V 10% X5R 0805
C31 | 10uF | Murata | GRM21BR61A106KE19L | CAP CER 10UF 10V 10% X5R 0805
L1 | 4u7 | Taiyo Yuden | NRG4026T4R7M | INDUCTOR 4.7UH 1.6A 20% SMD | 2 | 587-2382-1-ND
L2 | 4u7 | Taiyo Yuden | NRG4026T4R7M | INDUCTOR 4.7UH 1.6A 20% SMD
FB1 | FILTER | Murata | BLM21PG221SN1D | FERRITE CHIP 220 OHM 2000MA 0805 | 1 | 490-1054-1-ND
U1 | GSG-IP4220CZ6 | NXP | IP4220CZ6,125 | IC USB DUAL ESD PROTECT 6TSOP | 1 | 568-3529-1-ND
J1 | GSG-USB-MICRO-B | FCI | 10103594-0001LF | CONN RCPT STD MICRO USB TYPE B | 1 | 609-4050-1-ND
U4 | GSG-XC2C64A-7VQG100C | Xilinx | XC2C64A-7VQG100C | IC CR-II CPLD 64MCELL 100-VQFP | 1 | 122-1409-ND
U2 | LPC43XXFBD144 | NXP | LPC4330FBD144,551 | IC MCU 32BIT 144LQFP | 1 | 568-9450-ND
U5 | TPS62410 | Texas Instruments | TPS62410DRCR | IC BUCK SYNC DUAL ADJ 0.8A 10SON | 1 | 296-25488-1-ND
D3 | LED3 | Everlight | QTLP601CRTR | LED RED STD BRIGHT 0603 SMD | 1 | 1080-1407-1-ND
D5 | 1V8LED | Everlight | QTLP600CYTR | LED YLW SUPER BRIGHT 0606 SMD | 3 | 1080-1404-1-ND
D2 | LED2 | Everlight | QTLP600CYTR | LED YLW SUPER BRIGHT 0606 SMD
D7 | USBLED0 | Everlight | QTLP600CYTR | LED YLW SUPER BRIGHT 0606 SMD
D1 | LED1 | Everlight | QTLP601C4TR | LED GREEN STD BRIGHT 0603 SMD | 3 | 1080-1405-1-ND
D6 | USBLED1 | Everlight | QTLP601C4TR | LED GREEN STD BRIGHT 0603 SMD
D4 | VCCLED | Everlight | QTLP601C4TR | LED GREEN STD BRIGHT 0603 SMD
U3 | W25Q80BV | Winbond | W25Q80BVSSIG | IC FLASH 8MBIT 8SOIC | 1 | W25Q80BVSSIG-ND
P2 | LPC_JTAG | Samtec Inc | EHF-105-01-L-D | CONN HEADER .05" 10POS DUAL T/H | 1 | SAM8205-ND
P16 | 1V8
P13 | ADC/DAC
P1 | ANALOG
P10 | BANK1_AUX
P22 | BANK1_PWR
P8 | BANK2_AUX
P4 | BOOT0
P19 | BOOT1
P20 | BOOT2
P21 | BOOT3
P6 | CLOCK_CTL
P18 | CPLD_JTAG
R33 | DNP
R34 | DNP
P5 | GPIO
P15 | I2S
P14 | LPC_ISP
P3 | LPC_MISC
P12 | SD
P9 | SPI
P11 | SPIFI
P7 | XCVR_CTL
P17 | VCC

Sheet: ImportPart_DigiKey
2,P0.0GCT-ND
10,P100GCT-ND
7,P470GCT-ND
2,P1.8KGCT-ND
13,P10KGCT-ND
1,P12.0KHCT-ND
1,P15KGCT-ND
1,P33KGCT-ND
1,P160KHCT-ND
1,P180KHCT-ND
1,P360KHCT-ND
2,P560KHCT-ND
10,490-1411-1-ND
10,490-1419-1-ND
30,490-1532-1-ND
10,490-1427-1-ND
1,587-1297-1-ND
10,490-1709-1-ND
2,587-2382-1-ND
1,490-1054-1-ND
1,568-3529-1-ND
1,609-4050-1-ND
1,122-1409-ND
1,568-9450-ND
1,296-25488-1-ND
1,1080-1407-1-ND
3,1080-1404-1-ND
3,1080-1405-1-ND
1,W25Q80BVSSIG-ND
1,SAM8205-ND

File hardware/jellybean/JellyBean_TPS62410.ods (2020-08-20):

 | TPS62410 VCC |  | TPS62410 1V8
R36 (OHM) | 160000 | R35 (OHM) | 180000
R38 (OHM) | 560000 | R37 (OHM) | 360000
 | VCC (Converter1) |  | 1V8
Out Voltage | 2,7 | Out Voltage | 1,8
After Fix 3.3V
 | TPS62410 VCC
R36 (OHM) | 124444 | 160KOHM in // with 560KOHM
R38 (OHM) | 560000
 | VCC (Converter1)
Out Voltage | 3,3

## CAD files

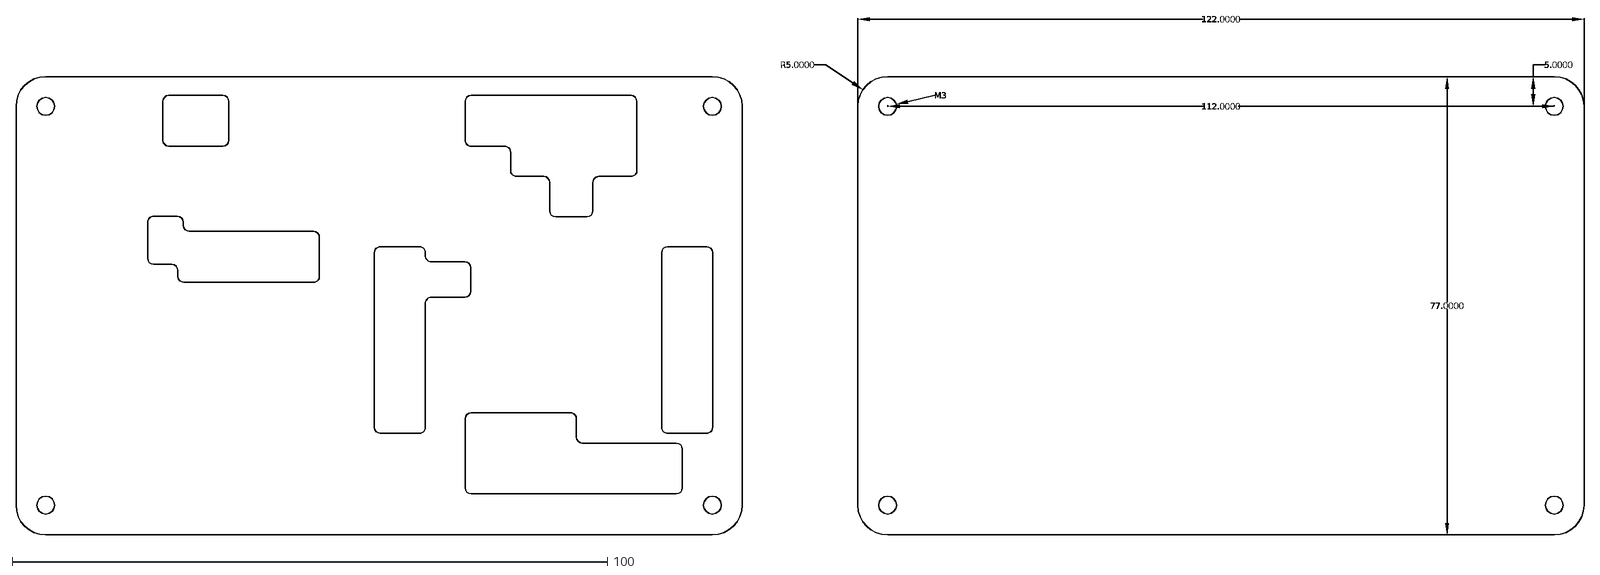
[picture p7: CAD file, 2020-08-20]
hardware/hackrf-one/PlasticCase_CAD/HackRF_One_Case.dxf
5.0000
M3
112.0000
122.0000
77.0000
R5.0000

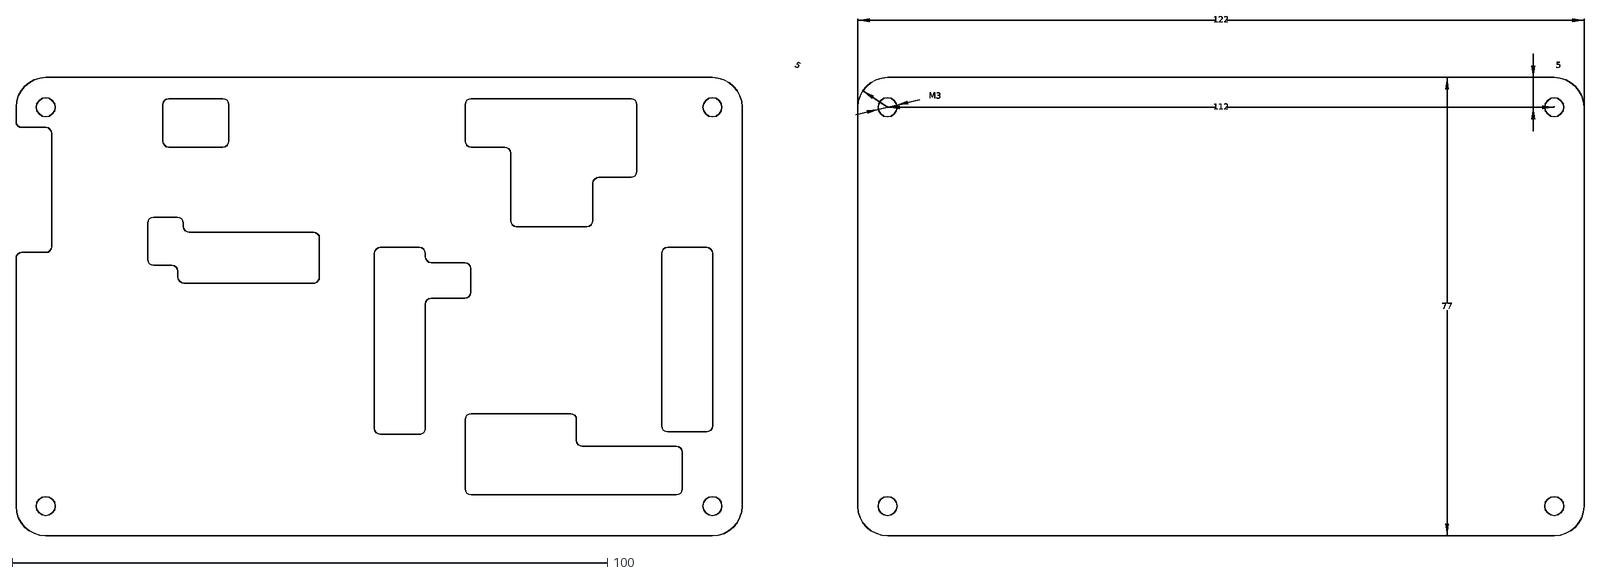
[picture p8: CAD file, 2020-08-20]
hardware/hackrf-one/PlasticCase_CAD/HackRF_One_Case_With_Button_CutOuts.dxf
5
M3
112
122
77

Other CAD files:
hardware/hackrf-one/SoBv1_HackRF_One_16Janv2014/SoBv1_HackRF_One_Bottom2D.skp
hardware/hackrf-one/SoBv1_HackRF_One_16Janv2014/SoBv1_HackRF_One_Top2D+HackRF_OneTOP.skp
hardware/hackrf-one/SoBv1_HackRF_One_16Janv2014/SoBv1_HackRF_One_Top2D.skp
hardware/jawbreaker/SoBv1_DP17298/SoBv1-DP17298-jawbreaker-Bottom.skp
hardware/jawbreaker/SoBv1_DP17298/SoBv1-DP17298-jawbreaker-Top.skp

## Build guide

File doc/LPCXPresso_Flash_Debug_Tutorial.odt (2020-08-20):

# LPCXpresso Flash/Debug Tutorial

# Hardware required

1) NXP LPC-Link board included with any LPCXPRESSO Board (for 20Euros) from Embedded Artists see http://www.embeddedartists.com/products/lpcxpresso

To separate the LPC-LINK side and the target side (required to use the debugger JTAG/SWD) on an other board), see document:

http://www.embeddedartists.com/sites/default/files/docs/HowToCreateAnLPC-LINK.pdf

The suggested LPCXpresso boards are LPC11U14, LPC1227 and LPC1769 which just need the use of desoldering braid to remove the solder bumps, for other board it is required to cut some wires.

For my Example I use a LPCXPresso LPC1769 board.

2) LPC43xx board in this tutorial I will use the HackRF board called JellyBean designed by Michael Ossmann (thanks for this amazing board ;-).
For this tutorial HackRF JellyBean board is used and example used is miniblink based on GitHub https://github.com/mossmann/libopencm3/tree/master/examples/lpc43xx/hackrf-jellybean/miniblink

Main GitHub is https://github.com/mossmann/libopencm3

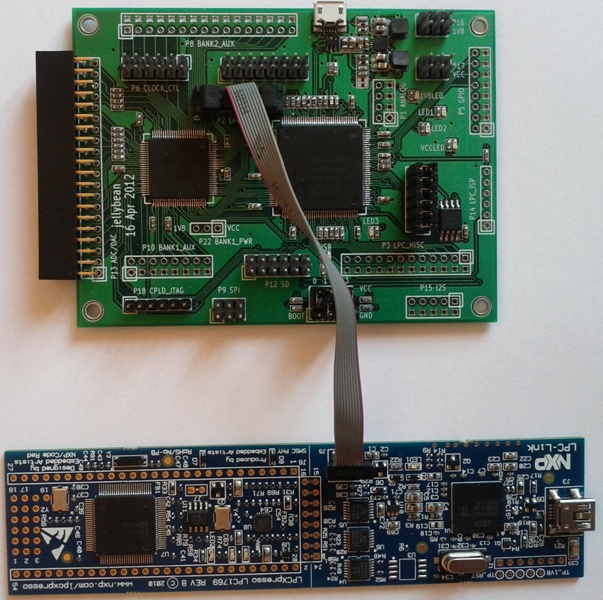
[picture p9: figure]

Nota: Pin1 is Red Pin on the 10-pin mini JTAG cable.

Nota I bought the mini JTAG cable at Embedded Artists here: http://www.embeddedartists.com/products/acc/acc_idc_10.php

# Software required

LPCXpresso v4.2.3 build 292 (size 213.4 MB):

Requires an account (Login/Password).

Windows version:

http://lpcxpresso.code-red-tech.com/LPCXpresso/system/files/LPCXpresso_4.2.3_292.exe

or

ftp://lpcxpresso.code-red-tech.com/LPCXpresso_4.2.3_292.exe

Linux version:

http://lpcxpresso.code-red-tech.com/LPCXpresso/system/files/Installer_LPCXpresso_4.2.3_255_Linux-x86.tar_.gz

Nota: Tutorial is done with Windows XP SP3 and LPCXpresso v4.2.3 build 292 for windows.

# Starting LPCXpresso IDE

Before starting LPCXpresso you should register it (registration code shall be activated online with the card you will receive with your LPCXPRESSO Board), the registered version is only limited to debug code of max 128KB.

## Create a project

Choose Menu File->New->Project

Select C/C++ & LPCXpresso C project and click Next

Select NXP LPC4300 -> C Project (Cortex M4) and click Next

Choose project Name in the example hackrf_jellybean and click Next

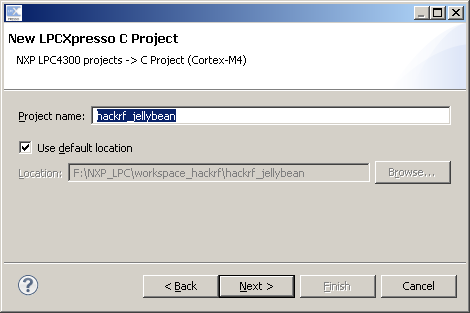
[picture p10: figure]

In Target Selection choose LPC4330 (for JellyBean) and click Next

For CMSIS DSP or Library just choose None for both and click Next

Just change C Dialect to gnu99 or what you prefer and click Finish

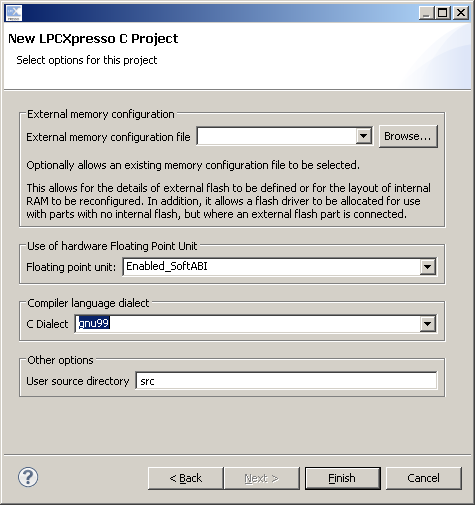
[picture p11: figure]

A basic project is now created.

You can import existing source project using link:

With mouse right click on project, choose New -> Folder

In Folder name: Enter the full path in the example hackrf-jellybean

Then click on Advanced and choose "Link to alternate location (Linked Folder)

And choose the full path in the example F:\SVN\libopencm3_TitanMKD\examples\lpc43xx\hackrf-jellybean

Then click on Finish.

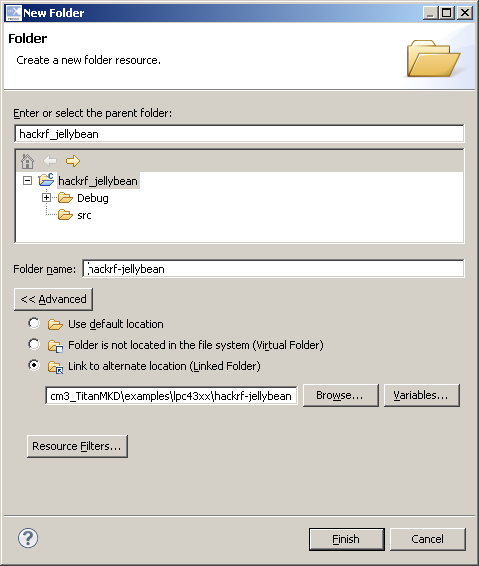
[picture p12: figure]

Now you have access to you external source from LPCXpresso IDE.

## Flashing ".bin" or ".elf" in SPIFI flash memory

With mouse click on project hackrf-jellybean previously created and click on the "Chip/Component" Icon

Configure Flash with following parameters:

1) Choose Flash driver file (using Flash driver Browse) in Default Installation path \LPCXpresso_4.2.3_292\lpcxpresso\bin\Flash\LPC1850A_4350A_SPIFI.cfx

2) Select the file to write in flash in our example F:\SVN\libopencm3_TitanMKD\examples\lpc43xx\hackrf-jellybean\miniblink\miniblink.bin

3) Choose base address: 0x14000000

Click OK to start.

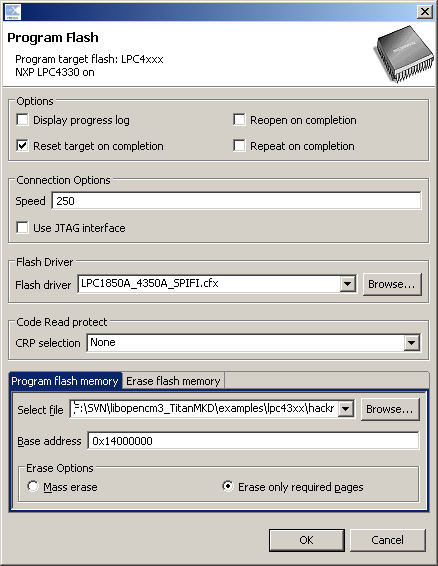
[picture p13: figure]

Progress shall be displayed and all disappear when it is finished

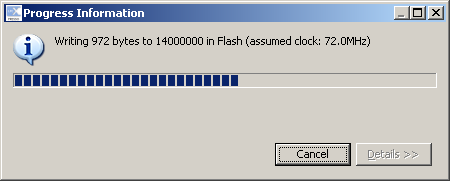
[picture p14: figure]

Nota: Flashing with JTAG work fine too and is a bit faster than default SWD mode.

## Debugger configuration

With mouse Right click on project (or Alt Enter), choose Properties

Choose MCU settings and Edit to add Flash memory at location 0x0 with size 0x100000 (1MB)

Click on Apply and OK

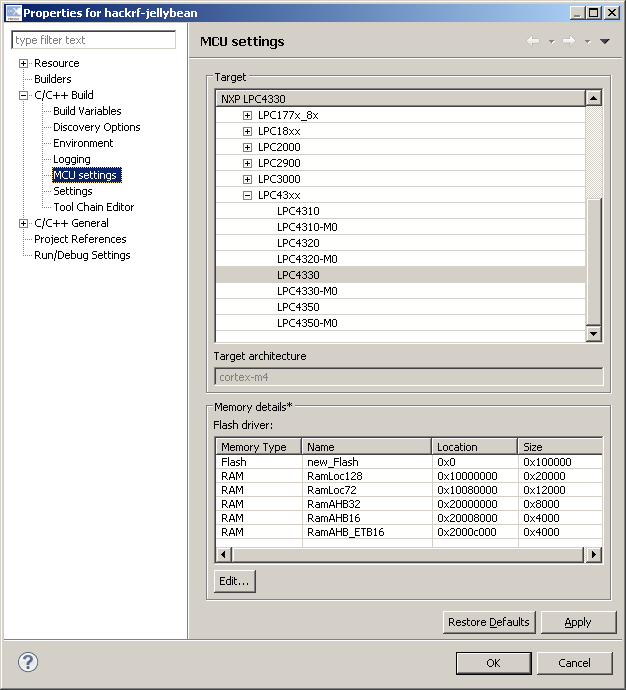
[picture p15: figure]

This step is mandatory to debug code executing from SPIFI flash, else debugger will always fail to set breakpoint to debug code.

With following error:

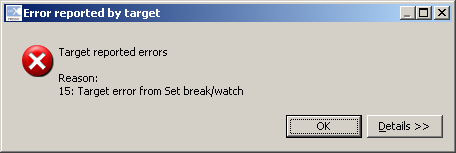
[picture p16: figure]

Now configure the debugger

With mouse Right click on project, choose Debug As -> Debug configurations...

Double click on C/C++ MCU Application to automatically create hack_rfjellybean Debug Entry

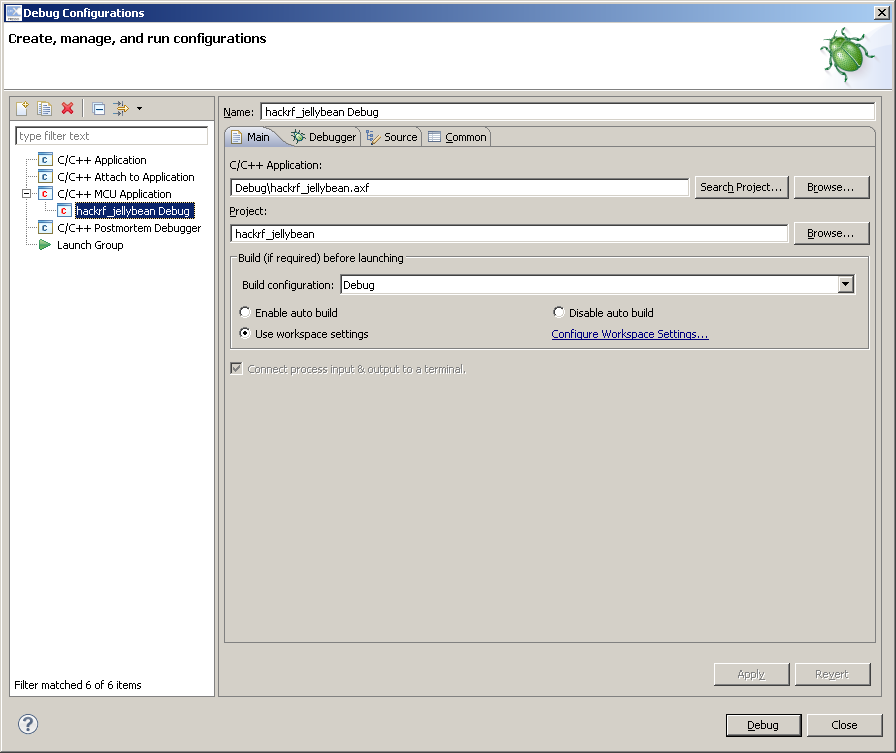
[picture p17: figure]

Now change de C/C++ Application to miniblink.elf using full path

In the example F:\SVN\libopencm3_TitanMKD\examples\lpc43xx\hackrf-jellybean\miniblink.elf

Disable the auto build too.

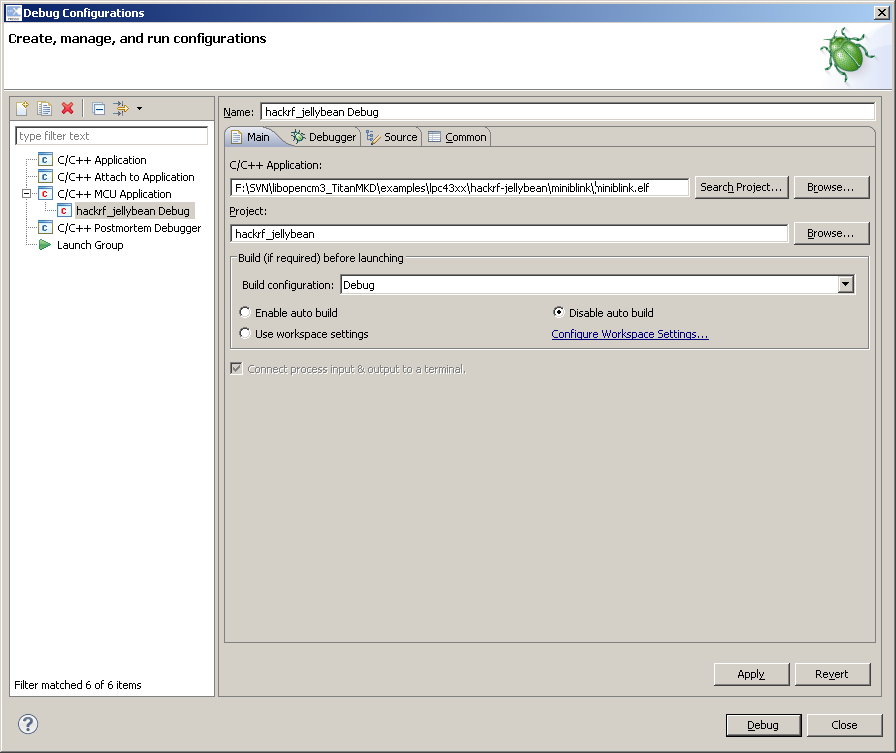
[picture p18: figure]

Configure the debugger:

1) You can change "Stop on startup at:" by reset_handler or using an address like 0x00001234 if you want to stop execution before the default main code (it not always stop to debug it from start you need to flash it and then debug).

2) Change debugger options to use NXP LPC43xx (SWD) because JTAG never work for me.

Now click on Apply and Debug.

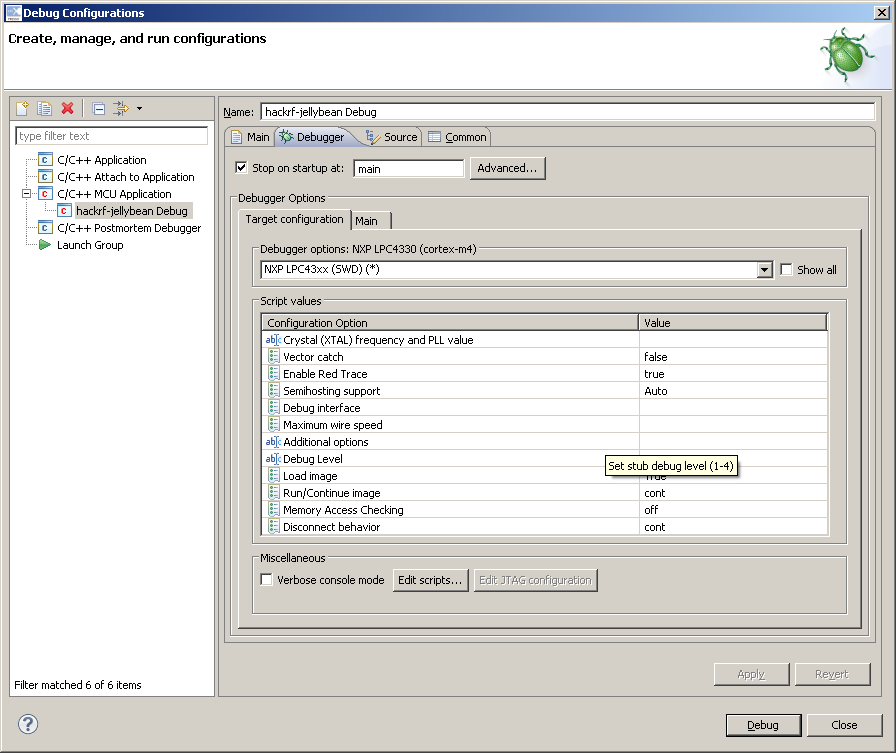
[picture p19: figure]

The debugger is launched and code is running

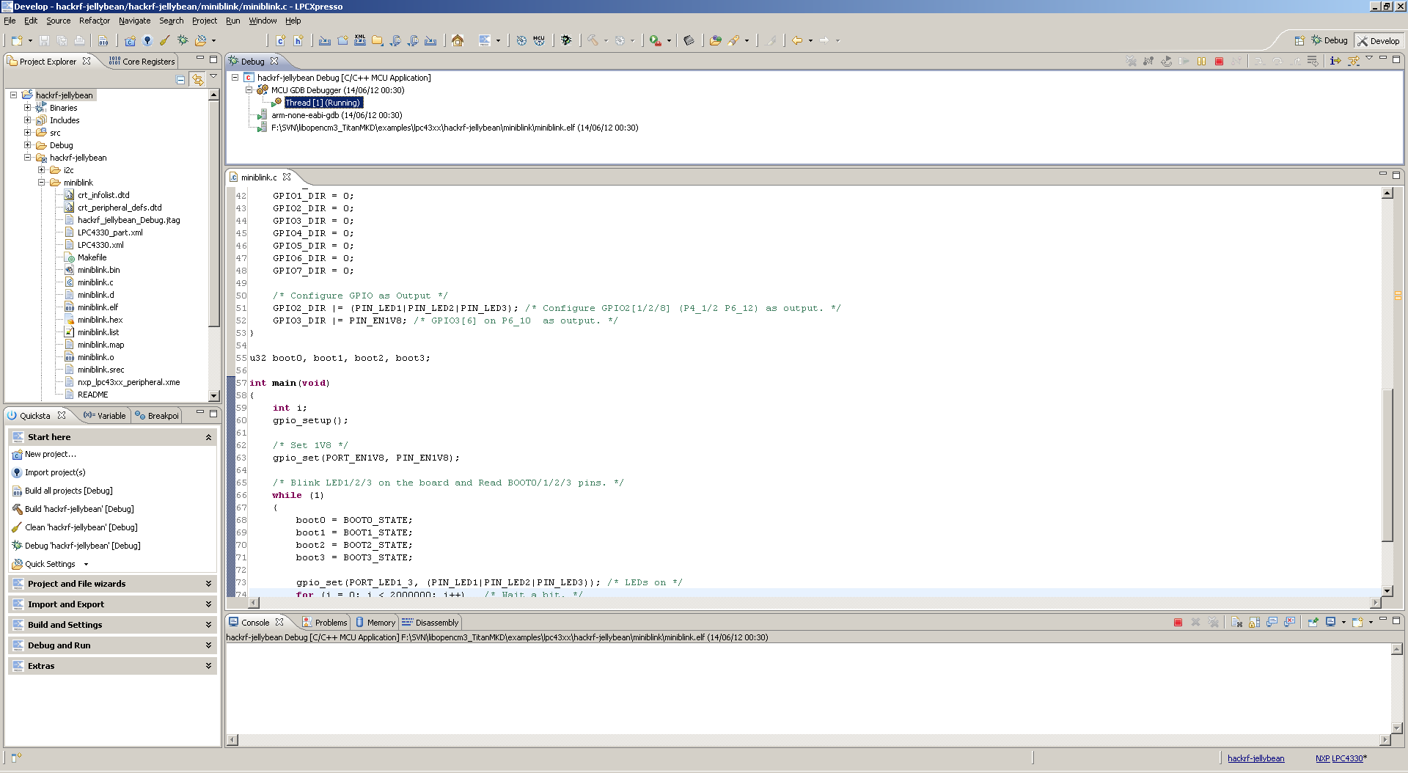
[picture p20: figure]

Just click on Pause "||" to stop it.

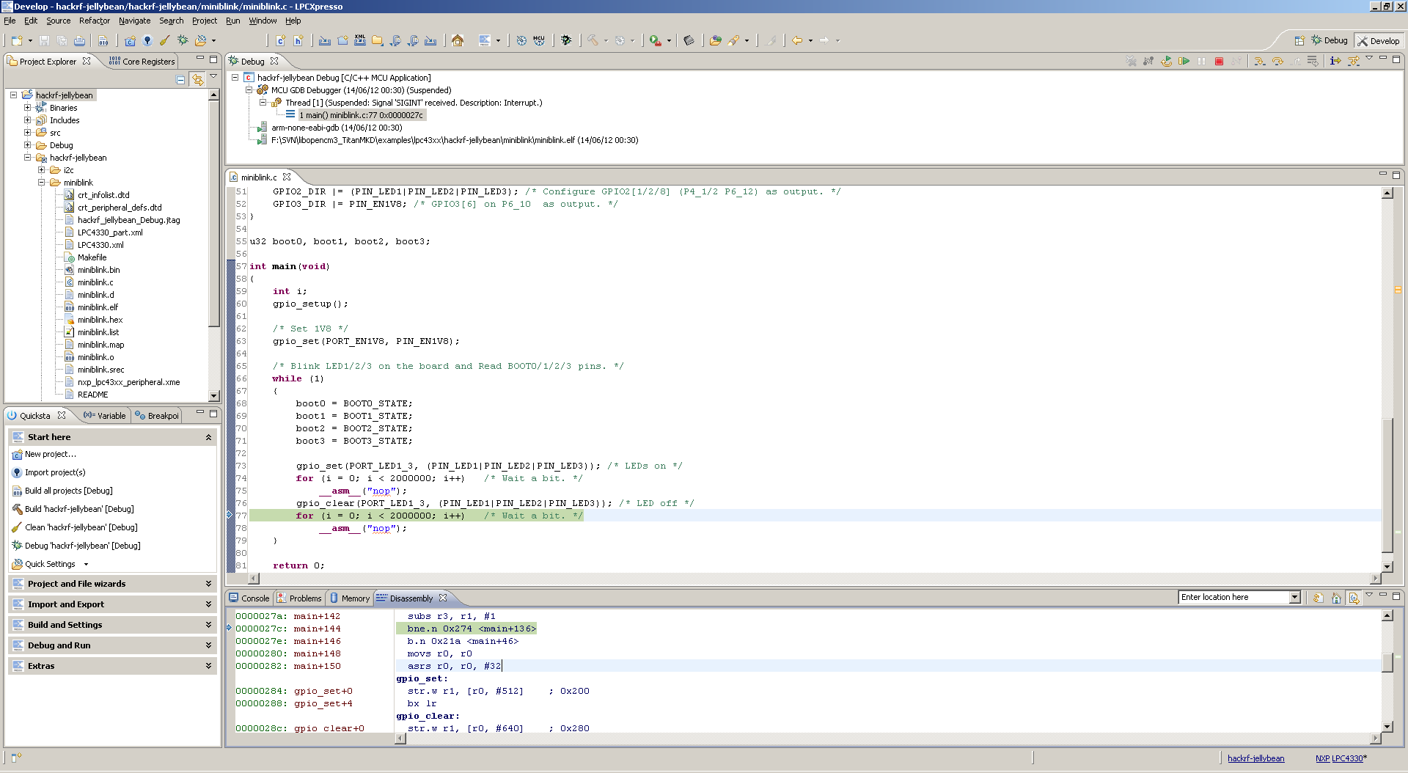
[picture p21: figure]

Now you can do step by step or check assembly code or core register (in debug view or by adding the window)

You can also view Peripherals with details (by default in debug view).

Warning View on CGU, CCU1 or CCU2 peripheral trig an error or even crash (for CCU1/2) crt_emu_lpc18_43_nxp.exe

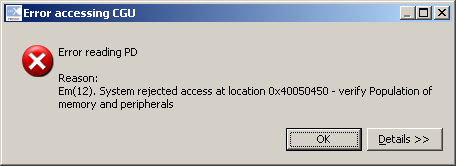
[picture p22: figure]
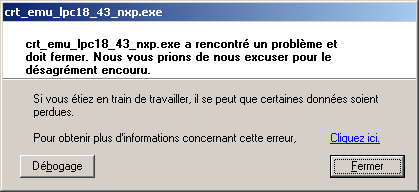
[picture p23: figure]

After the crash of crt_emu_lpc18_43_nxp.exe you need to kill the debug session, power off the LPC43xx board, power on LPC43xx board and restart debug session, else all is crashed.

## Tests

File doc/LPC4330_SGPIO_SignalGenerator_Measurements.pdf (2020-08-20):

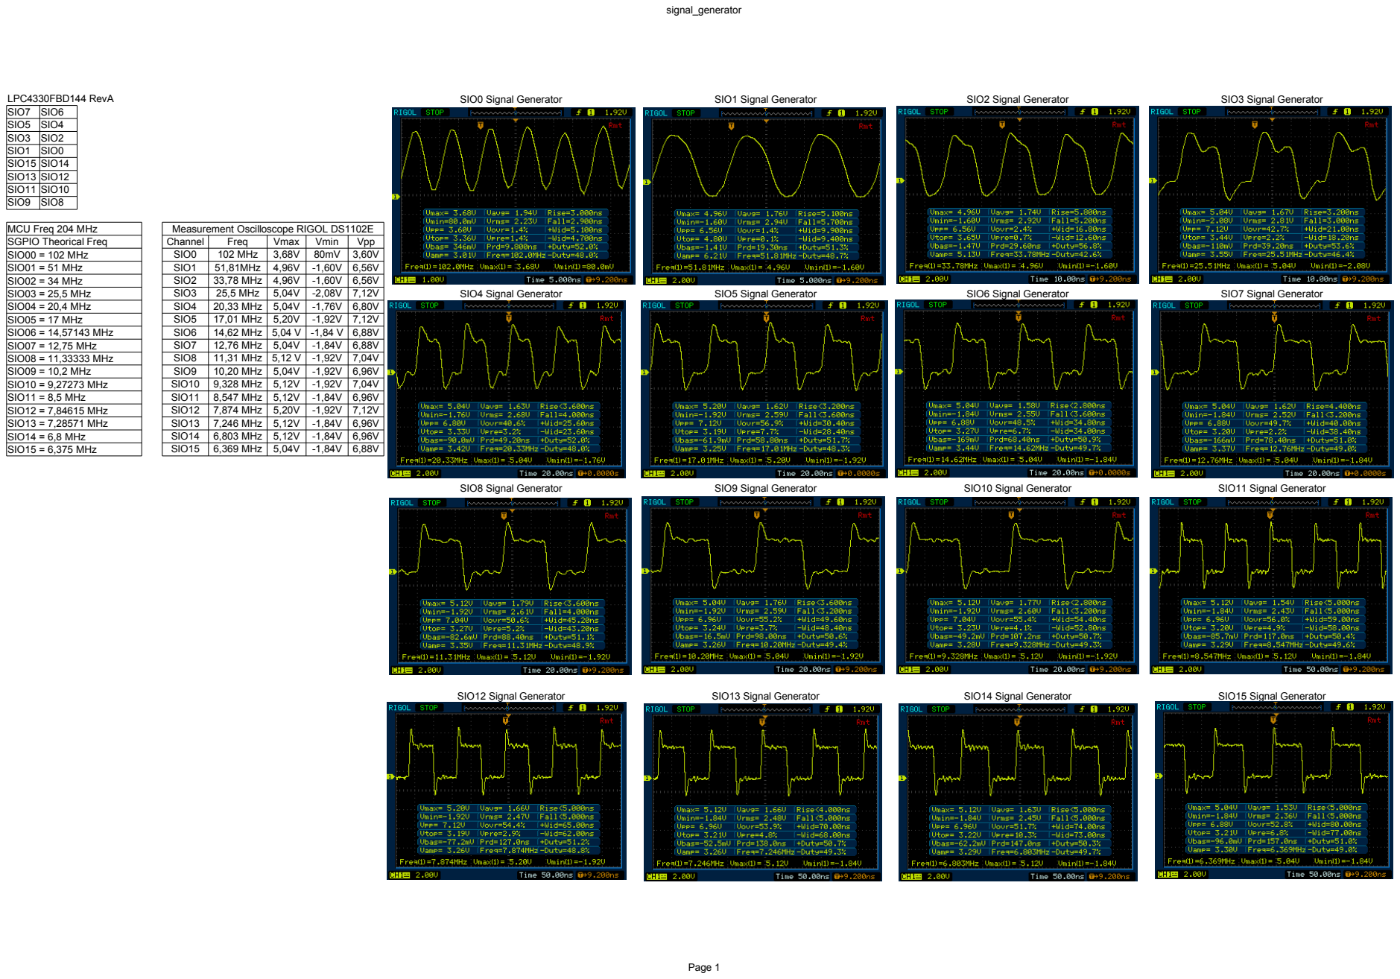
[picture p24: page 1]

signal_generator

LPC4330FBD144 RevA | SIO0 Signal Generator | SIO1 Signal Generator | SIO2 Signal Generator | SIO3 Signal Generator
SIO7 | SIO6
SIO5 | SIO4
SIO3 | SIO2
SIO1 | SIO0
SIO15 | SIO14
SIO13 | SIO12
SIO11 | SIO10
SIO9 | SIO8
MCU Freq 204 MHz | Measurement Oscilloscope RIGOL DS1102E
SGPIO Theorical Freq | Channel | Freq | Vmax | Vmin | Vpp
SIO00 = 102 MHz | SIO0 | 102 MHz | 3,68V | 80mV | 3,60V
SIO01 = 51 MHz | SIO1 | 51,81MHz | 4,96V | -1,60V | 6,56V
SIO02 = 34 MHz | SIO2 | 33,78 MHz | 4,96V | -1,60V | 6,56V
SIO03 = 25,5 MHz | SIO3 | 25,5 MHz | 5,04V | -2,08V | 7,12V | SIO4 Signal Generator | SIO5 Signal Generator | SIO6 Signal Generator | SIO7 Signal Generator
SIO04 = 20,4 MHz | SIO4 | 20,33 MHz | 5,04V | -1,76V | 6,80V
SIO05 = 17 MHz | SIO5 | 17,01 MHz | 5,20V | -1,92V | 7,12V
SIO06 = 14,57143 MHz | SIO6 | 14,62 MHz | 5,04 V | -1,84 V | 6,88V
SIO07 = 12,75 MHz | SIO7 | 12,76 MHz | 5,04V | -1,84V | 6,88V
SIO08 = 11,33333 MHz | SIO8 | 11,31 MHz | 5,12 V | -1,92V | 7,04V
SIO09 = 10,2 MHz | SIO9 | 10,20 MHz | 5,04V | -1,92V | 6,96V
SIO10 = 9,27273 MHz | SIO10 | 9,328 MHz | 5,12V | -1,92V | 7,04V
SIO11 = 8,5 MHz | SIO11 | 8,547 MHz | 5,12V | -1,84V | 6,96V
SIO12 = 7,84615 MHz | SIO12 | 7,874 MHz | 5,20V | -1,92V | 7,12V
SIO13 = 7,28571 MHz | SIO13 | 7,246 MHz | 5,12V | -1,84V | 6,96V
SIO14 = 6,8 MHz | SIO14 | 6,803 MHz | 5,12V | -1,84V | 6,96V
SIO15 = 6,375 MHz | SIO15 | 6,369 MHz | 5,04V | -1,84V | 6,88V
SIO8 Signal Generator | SIO9 Signal Generator | SIO10 Signal Generator | SIO11 Signal Generator
SIO12 Signal Generator | SIO13 Signal Generator | SIO14 Signal Generator | SIO15 Signal Generator

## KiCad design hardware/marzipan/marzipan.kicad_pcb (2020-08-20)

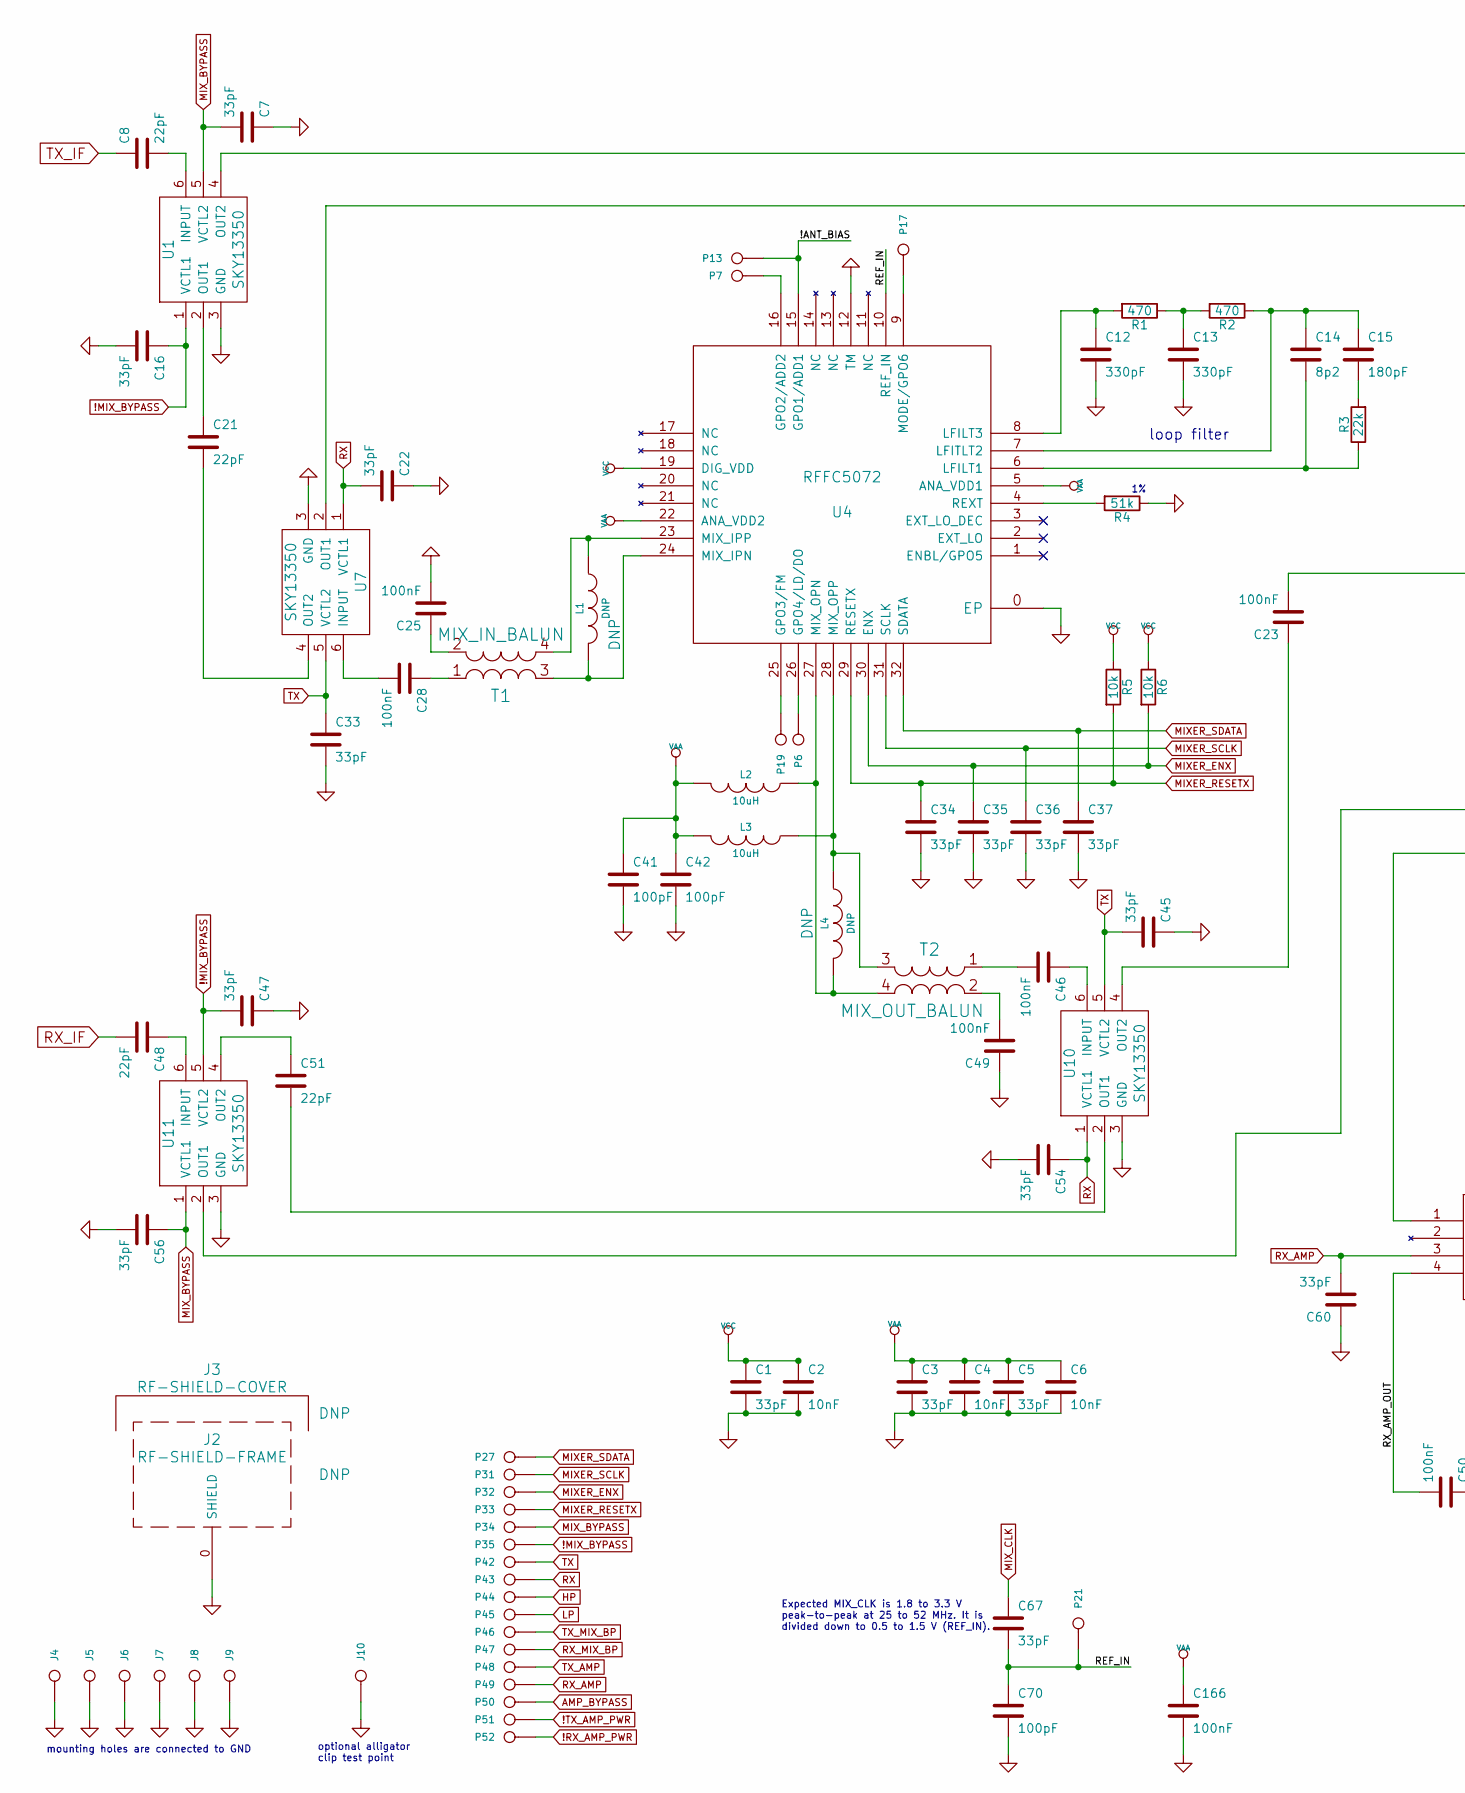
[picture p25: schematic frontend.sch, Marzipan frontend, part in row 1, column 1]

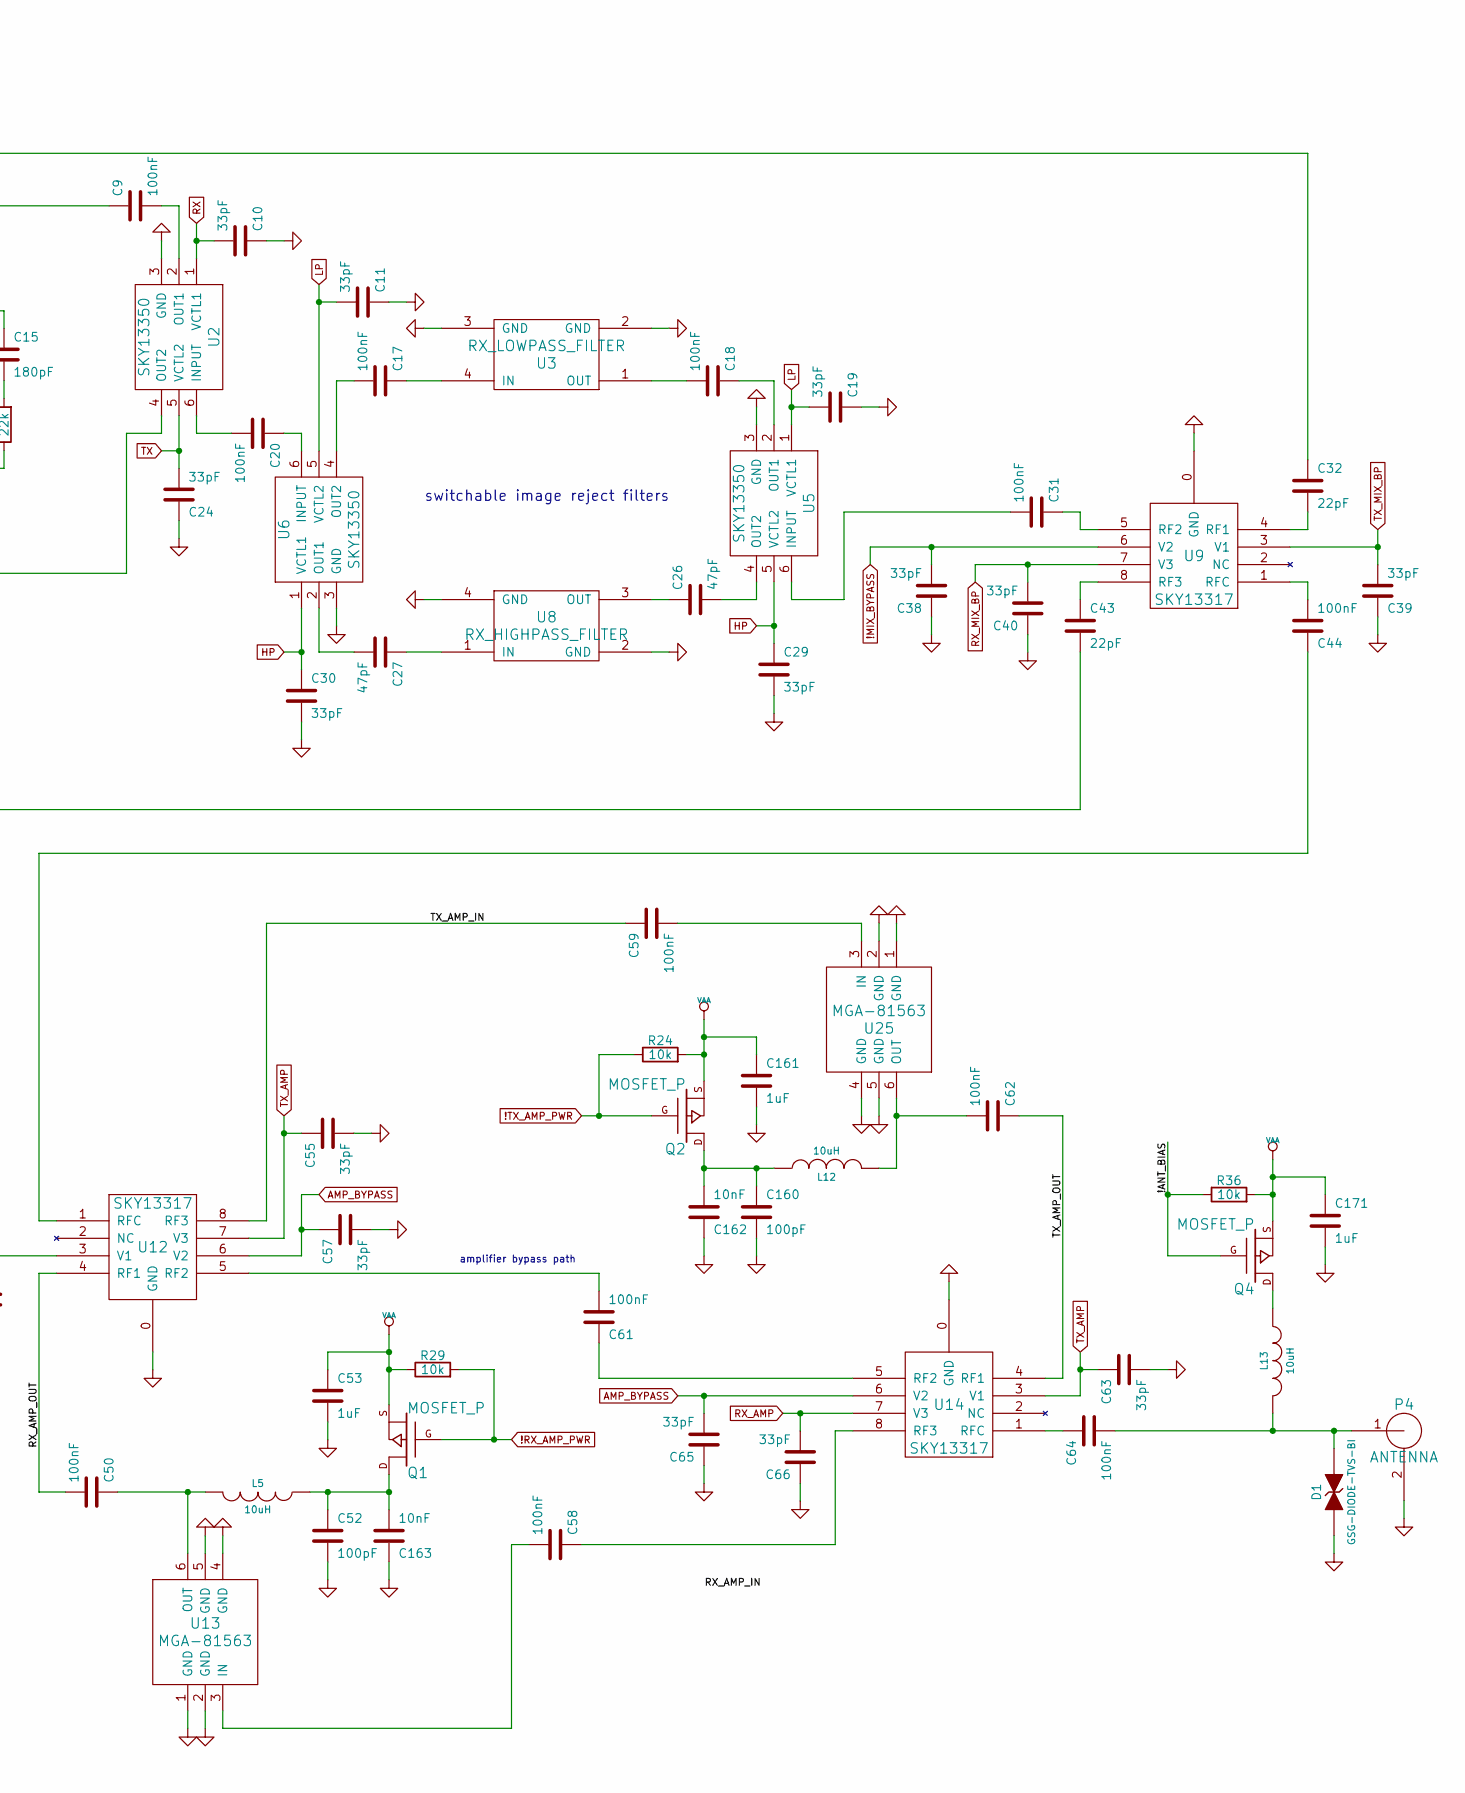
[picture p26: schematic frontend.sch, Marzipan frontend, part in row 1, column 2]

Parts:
C1, C3, C5, C7, C10, C11, C16, C19, C22, C24, C29, C30, C33, C34, C35, C36, C37, C38, C39, C40, C45, C47, C54, C55, C56, C57, C60, C63, C65, C66, C67: 33pF; GSG-0402; Part Number GRM1555C1H330JA01D
C2, C4, C6, C162, C163: 10nF; GSG-0402; Part Number GRM155R71C103KA01D
C8, C21, C32, C43, C48, C51: 22pF; GSG-0402; Part Number GRM1555C1H220JA01D
C9, C17, C18, C20, C23, C25, C28, C31, C44, C46, C49, C50, C58, C59, C61, C62, C64, C166: 100nF; GSG-0402; Part Number GRM155R61A104KA01D
C12, C13: 330pF; GSG-0402; Part Number GRM155R71H331KA01D
C14: 8p2; GSG-0402; Part Number UMK105CG8R2DV-F
C15: 180pF; GSG-0402; Part Number GRM1555C1H181JA01D
C26, C27: 47pF; GSG-0402; Part Number GRM1555C1H470JA01D
C41, C42, C52, C70, C160: 100pF; GSG-0402; Part Number GRM1555C1H101JA01D
C53, C161, C171: 1uF; GSG-0402; Part Number LMK105BJ105KV-F
D1: GSG-DIODE-TVS-BI; GSG-0402; Part Number LXES15AAA1-100
J2: RF-SHIELD-FRAME; GSG-SHIELD-BMI-S-230; Part Number BMI-S-230-F-R
J3: RF-SHIELD-COVER; GSG-NULL-MODULE; Part Number BMI-S-230-C
J4, J5, J6, J7, J8, J9: MOUNTING_HOLE; GSG-HOLE126MIL-COPPER
J10: GND_CLIP; GSG-TEST-POINT-S1751-46R; Part Number S1751-46R
L1, L4: DNP; GSG-0402
L2, L3, L5, L12, L13: 10uH; GSG-0603; Part Number BRL1608T100M
P4: ANTENNA; GSG-SMA-73251-2120; Part Number 73251-2121
P6: GPO4; GSG-TESTPOINT-50MIL
P7: GPO2; GSG-TESTPOINT-50MIL
P13: GPO1; GSG-TESTPOINT-50MIL
P17: GPO6; GSG-TESTPOINT-50MIL
P19: GPO3; GSG-TESTPOINT-50MIL
P21: REF_IN; GSG-TESTPOINT-50MIL
P27: MIXER_SDATA; GSG-TESTPOINT-50MIL
P31: MIXER_SCLK; GSG-TESTPOINT-50MIL
P32: MIXER_ENX; GSG-TESTPOINT-50MIL
P33: MIXER_RESETX; GSG-TESTPOINT-50MIL
P34: MIX_BYPASS; GSG-TESTPOINT-50MIL
P35: !MIX_BYPASS; GSG-TESTPOINT-50MIL
P42: TX; GSG-TESTPOINT-50MIL
P43: RX; GSG-TESTPOINT-50MIL
P44: HP; GSG-TESTPOINT-50MIL
P45: LP; GSG-TESTPOINT-50MIL
P46: TX_MIX_BP; GSG-TESTPOINT-50MIL
P47: RX_MIX_BP; GSG-TESTPOINT-50MIL
P48: TX_AMP; GSG-TESTPOINT-50MIL
P49: RX_AMP; GSG-TESTPOINT-50MIL
P50: AMP_BYPASS; GSG-TESTPOINT-50MIL
P51: !TX_AMP_PWR; GSG-TESTPOINT-50MIL
P52: !RX_AMP_PWR; GSG-TESTPOINT-50MIL
Q1, Q2, Q4: MOSFET_P; SOT23GDS; Part Number BSS84
R1, R2: 470; GSG-0402; Part Number RMCF0402JT470R
R3: 22k; GSG-0402; Part Number ERJ-2GEJ223X
R4: 51k; GSG-0402; Part Number RMCF0402FT51K0
R5, R6, R24, R29, R36: 10k; GSG-0402; Part Number RMCF0402JT10K0
T1: MIX_IN_BALUN; GSG-B0310J50100AHF; Part Number B0310J50100AHF
T2: MIX_OUT_BALUN; GSG-B0310J50100AHF; Part Number B0310J50100AHF
U1, U2, U5, U6, U7, U10, U11: SKY13350; GSG-SKY13350-385LF; Part Number SKY13350-385LF
U3: RX_LOWPASS_FILTER; GSG-LP0603; Part Number LP0603A1880ANTR
U4: RFFC5072; GSG-QFN32; Part Number RFFC5072TR7
U8: RX_HIGHPASS_FILTER; GSG-HP-DEA; Part Number DEA162400HT-8004B1
U9, U12, U14: SKY13317; GSG-SKY13317-373LF; Part Number SKY13317-373LF
U13, U25: MGA-81563; GSG-SOT363; Part Number MGA-81563-TR1G

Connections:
!MIX_BYPASS: C16.1, C38.2, C47.2, P35.1, U1.1 (VCTL1), U9.6 (V2), U11.5 (VCTL2); also elsewhere on the board
!RX_AMP_PWR: P52.1, Q1.G, R29.2; also elsewhere on the board
!TX_AMP_PWR: P51.1, Q2.G, R24.1; also elsewhere on the board
/frontend/!ANT_BIAS: P13.1, Q4.G, R36.1, U4.15 (GPO1/ADD1)
/frontend/REF_IN: C67.2, C70.1, P21.1, U4.10 (REF_IN)
/frontend/RX_AMP_OUT: C50.2, U12.4 (RF1)
/frontend/TX_AMP_IN: C59.1, U12.8 (RF3)
/frontend/TX_AMP_OUT: C62.1, U14.4 (RF1)
AMP_BYPASS: C57.1, C65.2, P50.1, U12.6 (V2), U14.6 (V2); also elsewhere on the board
GND: C1.2, C2.2, C3.2, C4.2, C5.2, C6.2, C7.1, C10.1, C11.1, C12.2, C13.2, C16.2, C19.1, C22.1, C24.1, C25.2, C29.2, C30.2, C33.2, C34.2, C35.2, C36.2, C37.2, C38.1, C39.1, C40.1, C41.2, C42.2, C45.1, C47.1, C49.1, C52.2, C53.2, C54.2, C55.2, C56.2, C57.2, C60.1, C63.2, C65.1, C66.1, C70.2, C160.2, C161.2, C162.1, C163.1, C166.2, C171.2, D1.1 (A), J2.0, J4.1, J5.1, J6.1, J7.1, J8.1, J9.1, J10.1, P4.2 (GND), R4.1, U1.3 (GND), U2.3 (GND), U3.2 (GND), U3.3 (GND), U4.0 (EP), U4.12 (TM), U5.3 (GND), U6.3 (GND), U7.3 (GND), U8.2 (GND), U8.4 (GND), U9.0 (GND), U10.3 (GND), U11.3 (GND), U12.0 (GND), U13.1 (GND), U13.2 (GND), U13.4 (GND), U13.5 (GND), U14.0 (GND), U25.1 (GND), U25.2 (GND), U25.4 (GND), U25.5 (GND); also elsewhere on the board
HP: C29.1, C30.1, P44.1, U5.5 (VCTL2), U6.1 (VCTL1); also elsewhere on the board
LP: C11.2, C19.2, P45.1, U5.1 (VCTL1), U6.5 (VCTL2); also elsewhere on the board
MIXER_ENX: C35.1, P32.1, R6.2, U4.30 (ENX); also elsewhere on the board
MIXER_RESETX: C34.1, P33.1, R5.2, U4.29 (RESETX); also elsewhere on the board
MIXER_SCLK: C36.1, P31.1, U4.31 (SCLK); also elsewhere on the board
MIXER_SDATA: C37.1, P27.1, U4.32 (SDATA); also elsewhere on the board
MIX_BYPASS: C7.2, C56.1, P34.1, U1.5 (VCTL2), U11.1 (VCTL1); also elsewhere on the board
MIX_CLK: C67.1; also elsewhere on the board
unnamed: C8.2, U1.6 (INPUT)
unnamed: C9.1, U7.2 (OUT1)
unnamed: C9.2, U2.2 (OUT1)
unnamed: C12.1, R1.2, U4.8 (LFILT3)
unnamed: C13.1, R1.1, R2.2
unnamed: C14.1, C15.1, R2.1, U4.7 (LFITLT2)
unnamed: C14.2, R3.1, U4.6 (LFILT1)
unnamed: C15.2, R3.2
unnamed: C17.1, U3.4 (IN)
unnamed: C17.2, U6.4 (OUT2)
unnamed: C18.1, U5.2 (OUT1)
unnamed: C18.2, U3.1 (OUT)
unnamed: C20.1, U6.6 (INPUT)
unnamed: C20.2, U2.6 (INPUT)
unnamed: C21.1, U1.2 (OUT1)
unnamed: C21.2, U7.4 (OUT2)
unnamed: C23.1, U10.4 (OUT2)
unnamed: C23.2, U2.4 (OUT2)
unnamed: C25.1, T1.2 (S2)
unnamed: C26.1, U8.3 (OUT)
unnamed: C26.2, U5.4 (OUT2)
unnamed: C27.1, U8.1 (IN)
unnamed: C27.2, U6.2 (OUT1)
unnamed: C28.1, T1.1 (S1)
unnamed: C28.2, U7.6 (INPUT)
unnamed: C31.1, U9.5 (RF2)
unnamed: C31.2, U5.6 (INPUT)
unnamed: C32.1, U1.4 (OUT2)
unnamed: C32.2, U9.4 (RF1)
unnamed: C43.1, U9.8 (RF3)
unnamed: C43.2, U11.2 (OUT1)
unnamed: C44.1, U12.1 (RFC)
unnamed: C44.2, U9.1 (RFC)
unnamed: C46.1, U10.6 (INPUT)
unnamed: C46.2, T2.1 (S1)
unnamed: C48.1, U11.6 (INPUT)
unnamed: C49.2, T2.2 (S2)
unnamed: C50.1, L5.2, U13.6 (OUT)
unnamed: C51.1, U11.4 (OUT2)
unnamed: C51.2, U10.2 (OUT1)
unnamed: C58.1, U14.8 (RF3)
unnamed: C58.2, U13.3 (IN)
unnamed: C59.2, U25.3 (IN)
unnamed: C61.1, U14.5 (RF2)
unnamed: C61.2, U12.5 (RF2)
unnamed: C62.2, L12.2, U25.6 (OUT)
unnamed: C64.1, U14.1 (RFC)
unnamed: C64.2, D1.2 (K), L13.2, P4.1 (RF)
unnamed: C160.1, C162.2, L12.1, Q2.D
unnamed: C52.1, C163.2, L5.1, Q1.D
unnamed: L1.1, T1.4 (PR2), U4.23 (MIX_IPP)
unnamed: L1.2, T1.3 (PR1), U4.24 (MIX_IPN)
unnamed: L2.1, L4.2, T2.4 (PR2), U4.27 (MIX_OPN)
unnamed: L3.1, L4.1, T2.3 (PR1), U4.28 (MIX_OPP)
unnamed: L13.1, Q4.D
unnamed: P6.1, U4.26 (GPO4/LD/DO)
unnamed: P7.1, U4.16 (GPO2/ADD2)
unnamed: P17.1, U4.9 (MODE/GPO6)
unnamed: P19.1, U4.25 (GPO3/FM)
unnamed: R4.2, U4.4 (REXT)
RX: C10.2, C22.2, C54.1, P43.1, U2.1 (VCTL1), U7.1 (VCTL1), U10.1 (VCTL1); also elsewhere on the board
RX_AMP: C60.2, C66.2, P49.1, U12.3 (V1), U14.7 (V3); also elsewhere on the board
RX_IF: C48.2; also elsewhere on the board
RX_MIX_BP: C40.2, P47.1, U9.7 (V3); also elsewhere on the board
TX: C24.2, C33.1, C45.2, P42.1, U2.5 (VCTL2), U7.5 (VCTL2), U10.5 (VCTL2); also elsewhere on the board
TX_AMP: C55.1, C63.1, P48.1, U12.7 (V3), U14.3 (V1); also elsewhere on the board
TX_IF: C8.1; also elsewhere on the board
TX_MIX_BP: C39.2, P46.1, U9.3 (V1); also elsewhere on the board
VAA: C3.1, C4.1, C5.1, C6.1, C41.1, C42.1, C53.1, C161.1, C166.1, C171.1, L2.2, L3.2, Q1.S, Q2.S, Q4.S, R24.2, R29.1, R36.2, U4.5 (ANA_VDD1), U4.22 (ANA_VDD2); also elsewhere on the board
VCC: C1.1, C2.1, R5.1, R6.1, U4.19 (DIG_VDD); also elsewhere on the board

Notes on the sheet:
amplifier bypass path
switchable image reject filters
Expected MIX_CLK is 1.8 to 3.3 V peak-to-peak at 25 to 52 MHz. It is divided down to 0.5 to 1.5 V (REF_IN).
loop filter
mounting holes are connected to GND
optional alligator clip test point

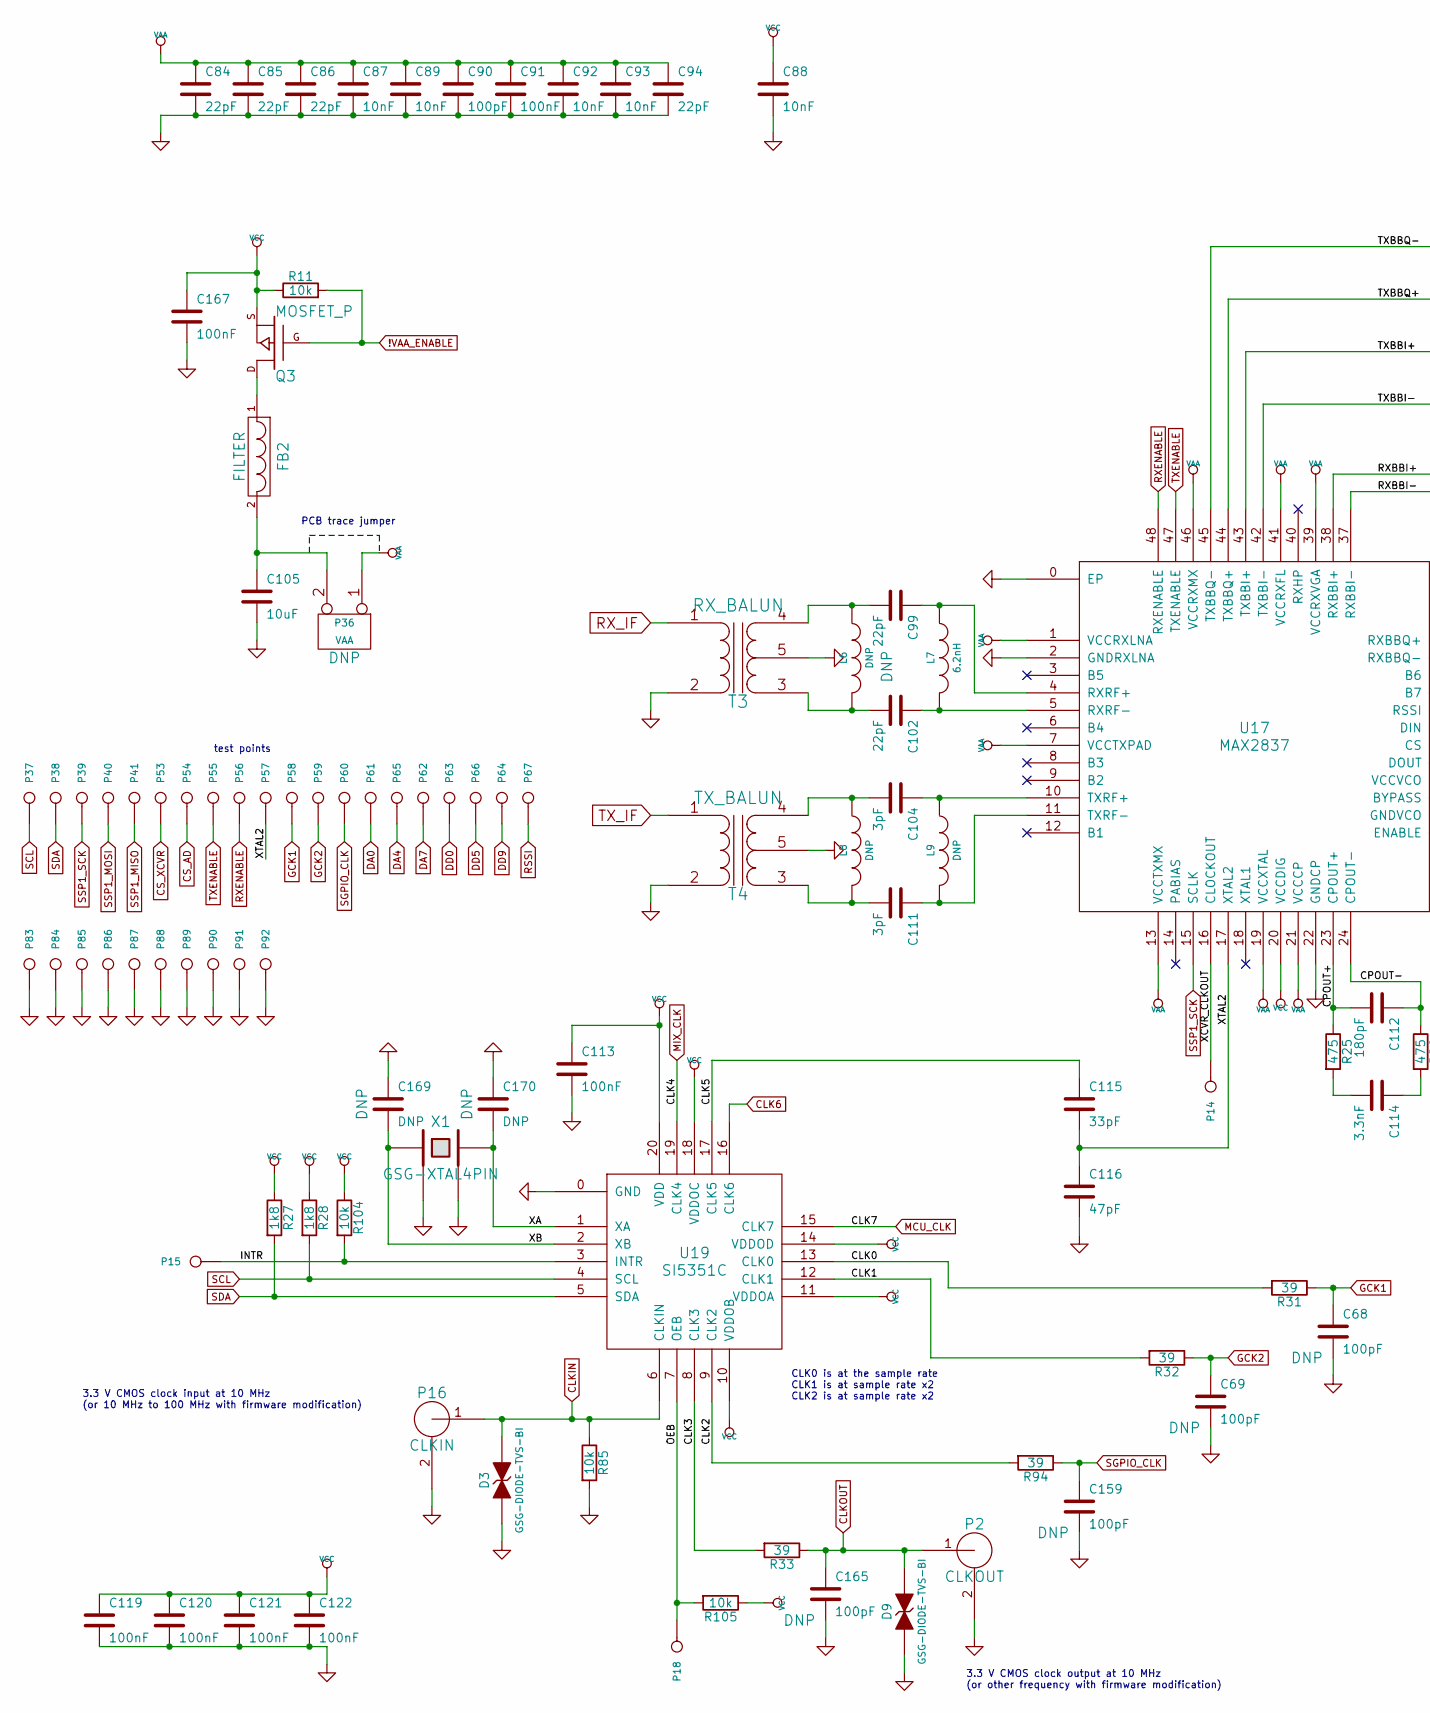
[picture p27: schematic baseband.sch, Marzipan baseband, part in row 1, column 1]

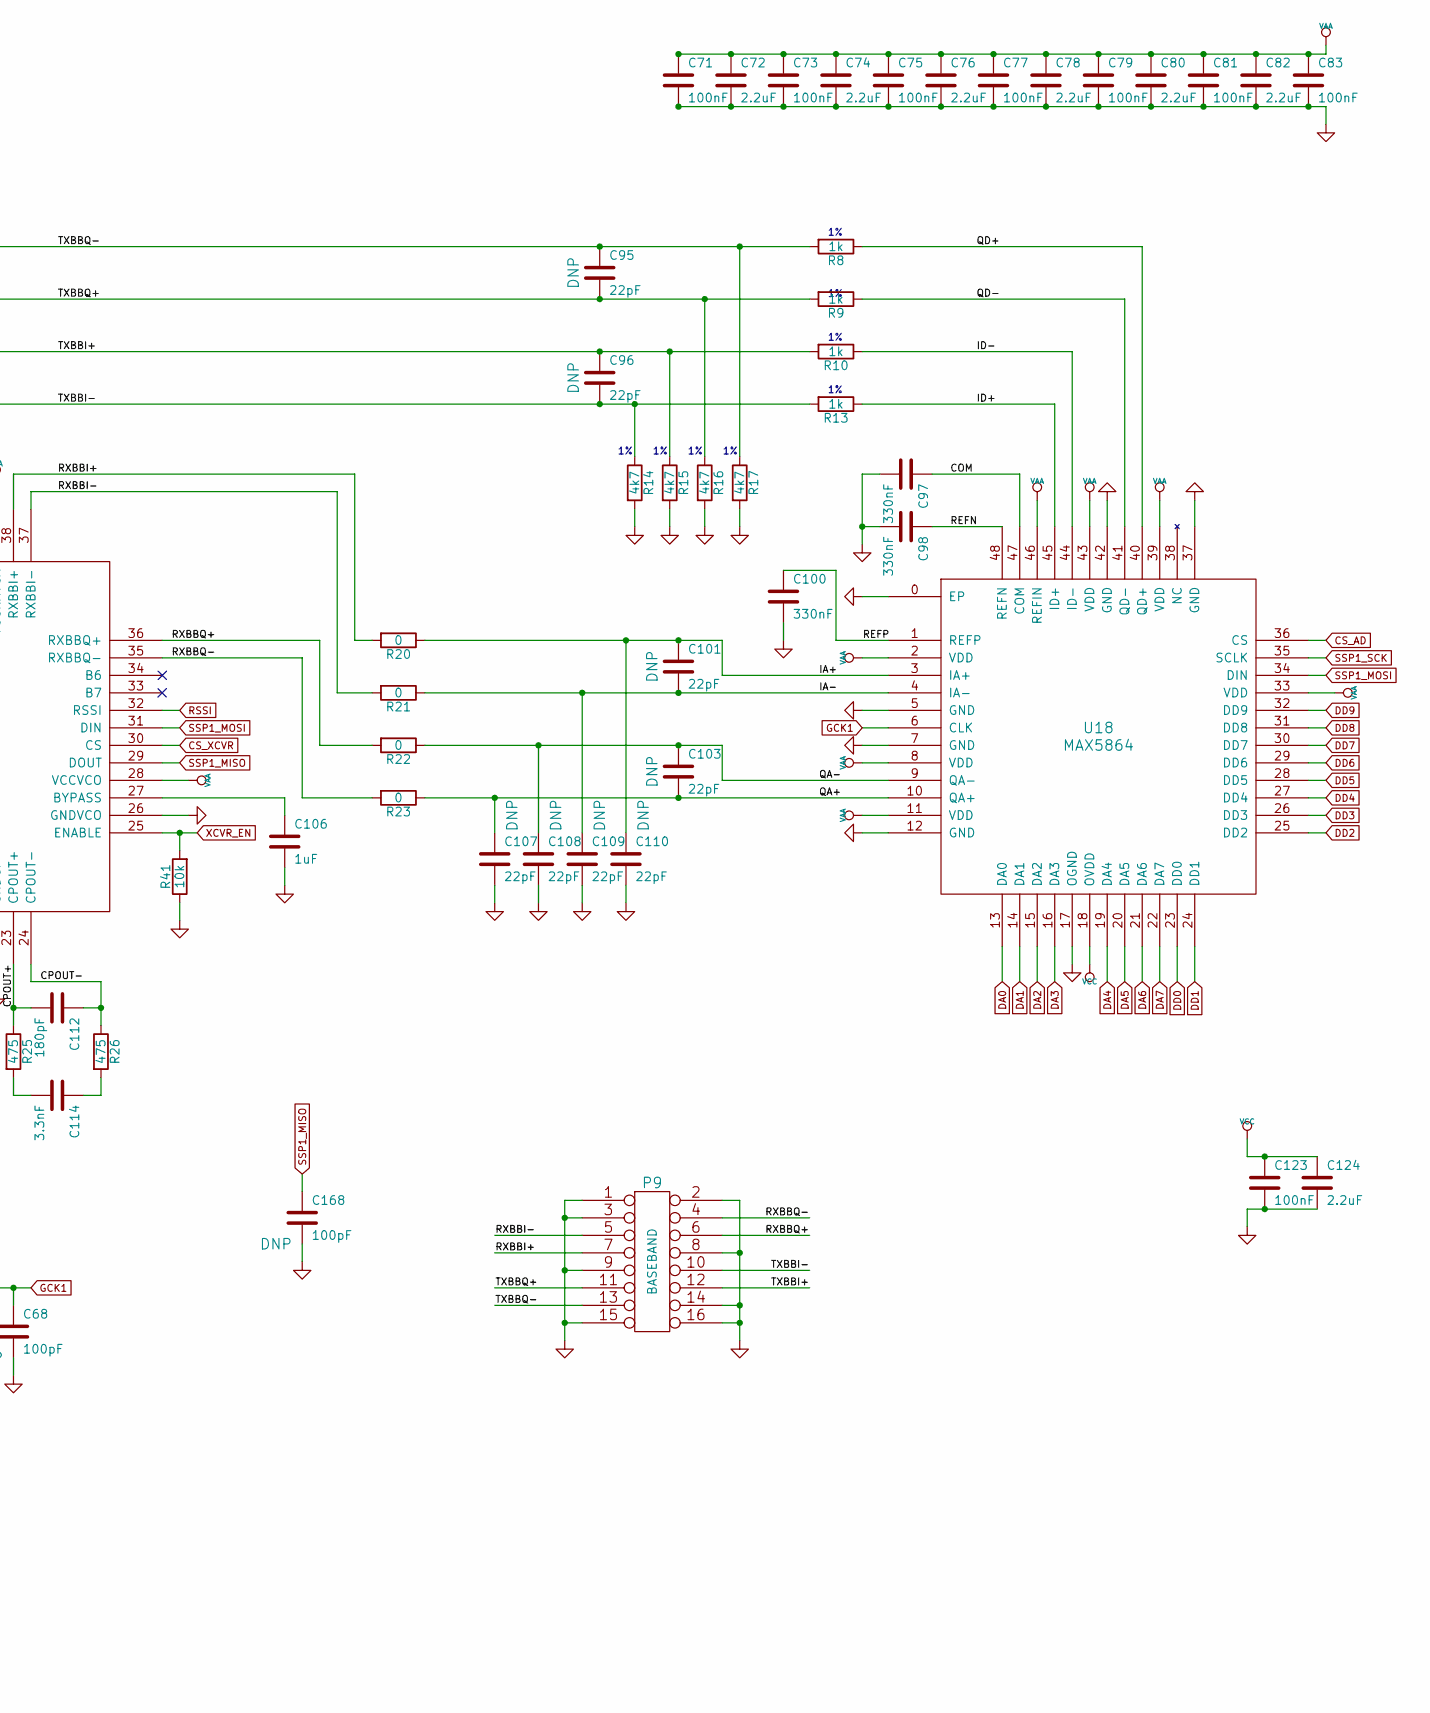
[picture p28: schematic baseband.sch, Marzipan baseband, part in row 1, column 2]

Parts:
C68, C69, C90, C159, C165, C168: 100pF; GSG-0402; Part Number GRM1555C1H101JA01D
C71, C73, C75, C77, C79, C81, C83, C91, C113, C119, C120, C121, C122, C123, C167: 100nF; GSG-0402; Part Number GRM155R61A104KA01D
C72, C74, C76, C78, C80, C82, C124: 2.2uF; GSG-0402; Part Number LMK105BJ225MV-F
C84, C85, C86, C94, C95, C96, C99, C101, C102, C103, C107, C108, C109, C110: 22pF; GSG-0402; Part Number GRM1555C1H220JA01D
C87, C88, C89, C92, C93: 10nF; GSG-0402; Part Number GRM155R71C103KA01D
C97, C98, C100: 330nF; GSG-0402; Part Number GRM155R61A334KE15D
C104, C111: 3pF; GSG-0402; Part Number GRM1555C1H3R0CA01D
C105: 10uF; GSG-0805; Part Number GRM21BR61A106KE19L
C106: 1uF; GSG-0402; Part Number LMK105BJ105KV-F
C112: 180pF; GSG-0402; Part Number GRM1555C1H181JA01D
C114: 3.3nF; GSG-0402; Part Number GRM155R71H332KA01D
C115: 33pF; GSG-0402; Part Number GRM1555C1H330JA01D
C116: 47pF; GSG-0402; Part Number GRM1555C1H470JA01D
C169, C170: DNP; GSG-0402
D3, D9: GSG-DIODE-TVS-BI; GSG-0402; Part Number LXES15AAA1-100
FB2: FILTER; GSG-0805; Part Number BLM21PG221SN1D
L6, L8, L9: DNP; GSG-0402
L7: 6.2nH; GSG-0402; Part Number HK10056N2S-T
P2: CLKOUT; GSG-SMA-73251-2120; Part Number 73251-2121
P9: BASEBAND; GSG-HEADER-2x8; Part Number PPPC082LFBN-RC
P14: XCVR_CLKOUT; GSG-TESTPOINT-50MIL
P15: INTR; GSG-TESTPOINT-50MIL
P16: CLKIN; GSG-SMA-73251-2120; Part Number 73251-2121
P18: OEB; GSG-TESTPOINT-50MIL
P36: VAA; GSG-HEADER-1x2
P37: SCL; GSG-TESTPOINT-50MIL
P38: SDA; GSG-TESTPOINT-50MIL
P39: SSP1_SCK; GSG-TESTPOINT-50MIL
P40: SSP1_MOSI; GSG-TESTPOINT-50MIL
P41: SSP1_MISO; GSG-TESTPOINT-50MIL
P53: CS_XCVR; GSG-TESTPOINT-50MIL
P54: CS_AD; GSG-TESTPOINT-50MIL
P55: TXENABLE; GSG-TESTPOINT-50MIL
P56: RXENABLE; GSG-TESTPOINT-50MIL
P57: XTAL2; GSG-TESTPOINT-50MIL
P58: GCK1; GSG-TESTPOINT-50MIL
P59: GCK2; GSG-TESTPOINT-50MIL
P60: SGPIO_CLK; GSG-TESTPOINT-50MIL
P61: DA0; GSG-TESTPOINT-50MIL
P62: DA7; GSG-TESTPOINT-50MIL
P63: DD0; GSG-TESTPOINT-50MIL
P64: DD9; GSG-TESTPOINT-50MIL
P65: DA4; GSG-TESTPOINT-50MIL
P66: DD5; GSG-TESTPOINT-50MIL
P67: RSSI; GSG-TESTPOINT-50MIL
P83, P84, P85, P86, P87, P88, P89, P90, P91, P92: GND; GSG-TESTPOINT-50MIL
Q3: MOSFET_P; SOT23GDS; Part Number DMP2305U-7
R8, R9, R10, R13: 1k; GSG-0402; Part Number RMCF0402FT1K00
R11, R41, R85, R104, R105: 10k; GSG-0402; Part Number RMCF0402JT10K0
R14, R15, R16, R17: 4k7; GSG-0402; Part Number RMCF0402FT4K70
R20, R21, R22, R23: 0; GSG-0402; Part Number RMCF0402ZT0R00
R25, R26: 475; GSG-0402; Part Number RMCF0402JT470R
R27, R28: 1k8; GSG-0402; Part Number RMCF0402JT1K80
R31, R32, R33, R94: 39; GSG-0402; Part Number RMCF0402JT39R0
T3: RX_BALUN; GSG-2500BL14M100; Part Number 2500BL14M100T
T4: TX_BALUN; GSG-2500BL14M100; Part Number 2500BL14M100T
U17: MAX2837; GSG-QFN48-6; Part Number MAX2837ETM+
U18: MAX5864; GSG-QFN48-7; Part Number MAX5864ETM+
U19: SI5351C; GSG-QFN20-4; Part Number SI5351C-B-GM
X1: GSG-XTAL4PIN; GSG-XTAL3.2x2.5mm; Part Number CX3225GB25000D0HEQZ1

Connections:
!VAA_ENABLE: Q3.G, R11.2; also elsewhere on the board
/baseband/CLK0: R31.2, U19.13 (CLK0)
/baseband/CLK1: R32.2, U19.12 (CLK1)
/baseband/CLK2: R94.2, U19.9 (CLK2)
/baseband/CLK3: R33.2, U19.8 (CLK3)
/baseband/CLK5: C115.1, U19.17 (CLK5)
/baseband/COM: C97.1, U18.47 (COM)
/baseband/CPOUT+: C112.2, R25.1, U17.23 (CPOUT+)
/baseband/CPOUT-: C112.1, R26.1, U17.24 (CPOUT-)
/baseband/IA+: C101.1, C110.1, R20.1, U18.3 (IA+)
/baseband/IA-: C101.2, C109.1, R21.1, U18.4 (IA-)
/baseband/ID+: R13.1, U18.45 (ID+)
/baseband/ID-: R10.1, U18.44 (ID-)
/baseband/INTR: P15.1, R104.2, U19.3 (INTR)
/baseband/OEB: P18.1, R105.2, U19.7 (OEB)
/baseband/QA+: C103.2, C107.1, R23.1, U18.10 (QA+)
/baseband/QA-: C103.1, C108.1, R22.1, U18.9 (QA-)
/baseband/QD+: R8.1, U18.40 (QD+)
/baseband/QD-: R9.1, U18.41 (QD-)
/baseband/REFN: C98.1, U18.48 (REFN)
/baseband/REFP: C100.1, U18.1 (REFP)
/baseband/RXBBI+: P9.7, R20.2, U17.38 (RXBBI+)
/baseband/RXBBI-: P9.5, R21.2, U17.37 (RXBBI-)
/baseband/RXBBQ+: P9.6, R22.2, U17.36 (RXBBQ+)
/baseband/RXBBQ-: P9.4, R23.2, U17.35 (RXBBQ-)
/baseband/TXBBI+: C96.1, P9.12, R10.2, R15.1, U17.43 (TXBBI+)
/baseband/TXBBI-: C96.2, P9.10, R13.2, R14.1, U17.42 (TXBBI-)
/baseband/TXBBQ+: C95.2, P9.11, R9.2, R16.1, U17.44 (TXBBQ+)
/baseband/TXBBQ-: C95.1, P9.13, R8.2, R17.1, U17.45 (TXBBQ-)
/baseband/XA: C170.2, U19.1 (XA), X1.3
/baseband/XB: C169.2, U19.2 (XB), X1.1
/baseband/XCVR_CLKOUT: P14.1, U17.16 (CLOCKOUT)
/baseband/XTAL2: C115.2, C116.1, P57.1, U17.17 (XTAL2)
CLK6: U19.16 (CLK6); also elsewhere on the board
CLKIN: D3.2 (K), P16.1 (RF), R85.1, U19.6 (CLKIN); also elsewhere on the board
CLKOUT: C165.1, D9.2 (K), P2.1 (RF), R33.1; also elsewhere on the board
CS_AD: P54.1, U18.36 (CS); also elsewhere on the board
CS_XCVR: P53.1, U17.30 (CS); also elsewhere on the board
DA0: P61.1, U18.13 (DA0); also elsewhere on the board
DA1: U18.14 (DA1); also elsewhere on the board
DA2: U18.15 (DA2); also elsewhere on the board
DA3: U18.16 (DA3); also elsewhere on the board
DA4: P65.1, U18.19 (DA4); also elsewhere on the board
DA5: U18.20 (DA5); also elsewhere on the board
DA6: U18.21 (DA6); also elsewhere on the board
DA7: P62.1, U18.22 (DA7); also elsewhere on the board
DD0: P63.1, U18.23 (DD0); also elsewhere on the board
DD1: U18.24 (DD1); also elsewhere on the board
DD2: U18.25 (DD2); also elsewhere on the board
DD3: U18.26 (DD3); also elsewhere on the board
DD4: U18.27 (DD4); also elsewhere on the board
DD5: P66.1, U18.28 (DD5); also elsewhere on the board
DD6: U18.29 (DD6); also elsewhere on the board
DD7: U18.30 (DD7); also elsewhere on the board
DD8: U18.31 (DD8); also elsewhere on the board
DD9: P64.1, U18.32 (DD9); also elsewhere on the board
GCK1: C68.1, P58.1, R31.1, U18.6 (CLK); also elsewhere on the board
GCK2: C69.1, P59.1, R32.1; also elsewhere on the board
GND: C68.2, C69.2, C71.2, C72.2, C73.2, C74.2, C75.2, C76.2, C77.2, C78.2, C79.2, C80.2, C81.2, C82.2, C83.2, C84.2, C85.2, C86.2, C87.2, C88.2, C89.2, C90.2, C91.2, C92.2, C93.2, C94.2, C97.2, C98.2, C100.2, C105.2, C106.2, C107.2, C108.2, C109.2, C110.2, C113.2, C116.2, C119.2, C120.2, C121.2, C122.2, C123.2, C124.2, C159.2, C165.2, C167.2, C168.2, C169.1, C170.1, D3.1 (A), D9.1 (A), P2.2 (GND), P9.1, P9.2, P9.3, P9.8, P9.9, P9.14, P9.15, P9.16, P16.2 (GND), P83.1, P84.1, P85.1, P86.1, P87.1, P88.1, P89.1, P90.1, P91.1, P92.1, R14.2, R15.2, R16.2, R17.2, R41.1, R85.2, T3.2 (S2), T3.5 (PM), T4.2 (S2), T4.5 (PM), U17.0 (EP), U17.2 (GNDRXLNA), U17.22 (GNDCP), U17.26 (GNDVCO), U18.0 (EP), U18.5 (GND), U18.7 (GND), U18.12 (GND), U18.17 (OGND), U18.37 (GND), U18.42 (GND), U19.0 (GND), X1.2, X1.4; also elsewhere on the board
MCU_CLK: U19.15 (CLK7); also elsewhere on the board
MIX_CLK: U19.19 (CLK4); also elsewhere on the board
unnamed: C99.1, L7.1, U17.4 (RXRF+)
unnamed: C99.2, L6.1, T3.4 (PR2)
unnamed: C102.1, L7.2, U17.5 (RXRF-)
unnamed: C102.2, L6.2, T3.3 (PR1)
unnamed: C104.1, L9.1, U17.10 (TXRF+)
unnamed: C104.2, L8.1, T4.4 (PR2)
unnamed: C105.1, FB2.2, P36.2 (PM)
unnamed: C106.1, U17.27 (BYPASS)
unnamed: C111.1, L9.2, U17.11 (TXRF-)
unnamed: C111.2, L8.2, T4.3 (PR1)
unnamed: C114.1, R26.2
unnamed: C114.2, R25.2
unnamed: FB2.1, Q3.D
RSSI: P67.1, U17.32 (RSSI); also elsewhere on the board
RXENABLE: P56.1, U17.48 (RXENABLE); also elsewhere on the board
RX_IF: T3.1 (S1); also elsewhere on the board
SCL: P37.1, R28.2, U19.4 (SCL); also elsewhere on the board
SDA: P38.1, R27.2, U19.5 (SDA); also elsewhere on the board
SGPIO_CLK: C159.1, P60.1, R94.1; also elsewhere on the board
SSP1_MISO: C168.1, P41.1, U17.29 (DOUT); also elsewhere on the board
SSP1_MOSI: P40.1, U17.31 (DIN), U18.34 (DIN); also elsewhere on the board
SSP1_SCK: P39.1, U17.15 (SCLK), U18.35 (SCLK); also elsewhere on the board
TXENABLE: P55.1, U17.47 (TXENABLE); also elsewhere on the board
TX_IF: T4.1 (S1); also elsewhere on the board
VAA: C71.1, C72.1, C73.1, C74.1, C75.1, C76.1, C77.1, C78.1, C79.1, C80.1, C81.1, C82.1, C83.1, C84.1, C85.1, C86.1, C87.1, C89.1, C90.1, C91.1, C92.1, C93.1, C94.1, P36.1, U17.1 (VCCRXLNA), U17.7 (VCCTXPAD), U17.13 (VCCTXMX), U17.19 (VCCXTAL), U17.21 (VCCCP), U17.28 (VCCVCO), U17.39 (VCCRXVGA), U17.41 (VCCRXFL), U17.46 (VCCRXMX), U18.2 (VDD), U18.8 (VDD), U18.11 (VDD), U18.33 (VDD), U18.39 (VDD), U18.43 (VDD), U18.46 (REFIN); also elsewhere on the board
VCC: C88.1, C113.1, C119.1, C120.1, C121.1, C122.1, C123.1, C124.1, C167.1, Q3.S, R11.1, R27.1, R28.1, R104.1, R105.1, U17.20 (VCCDIG), U18.18 (OVDD), U19.10 (VDDOB), U19.11 (VDDOA), U19.14 (VDDOD), U19.18 (VDDOC), U19.20 (VDD); also elsewhere on the board
XCVR_EN: R41.2, U17.25 (ENABLE); also elsewhere on the board

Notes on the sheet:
3.3 V CMOS clock output at 10 MHz (or other frequency with firmware modification)
3.3 V CMOS clock input at 10 MHz (or 10 MHz to 100 MHz with firmware modification)
test points
CLK0 is at the sample rate CLK1 is at sample rate x2 CLK2 is at sample rate x2
PCB trace jumper

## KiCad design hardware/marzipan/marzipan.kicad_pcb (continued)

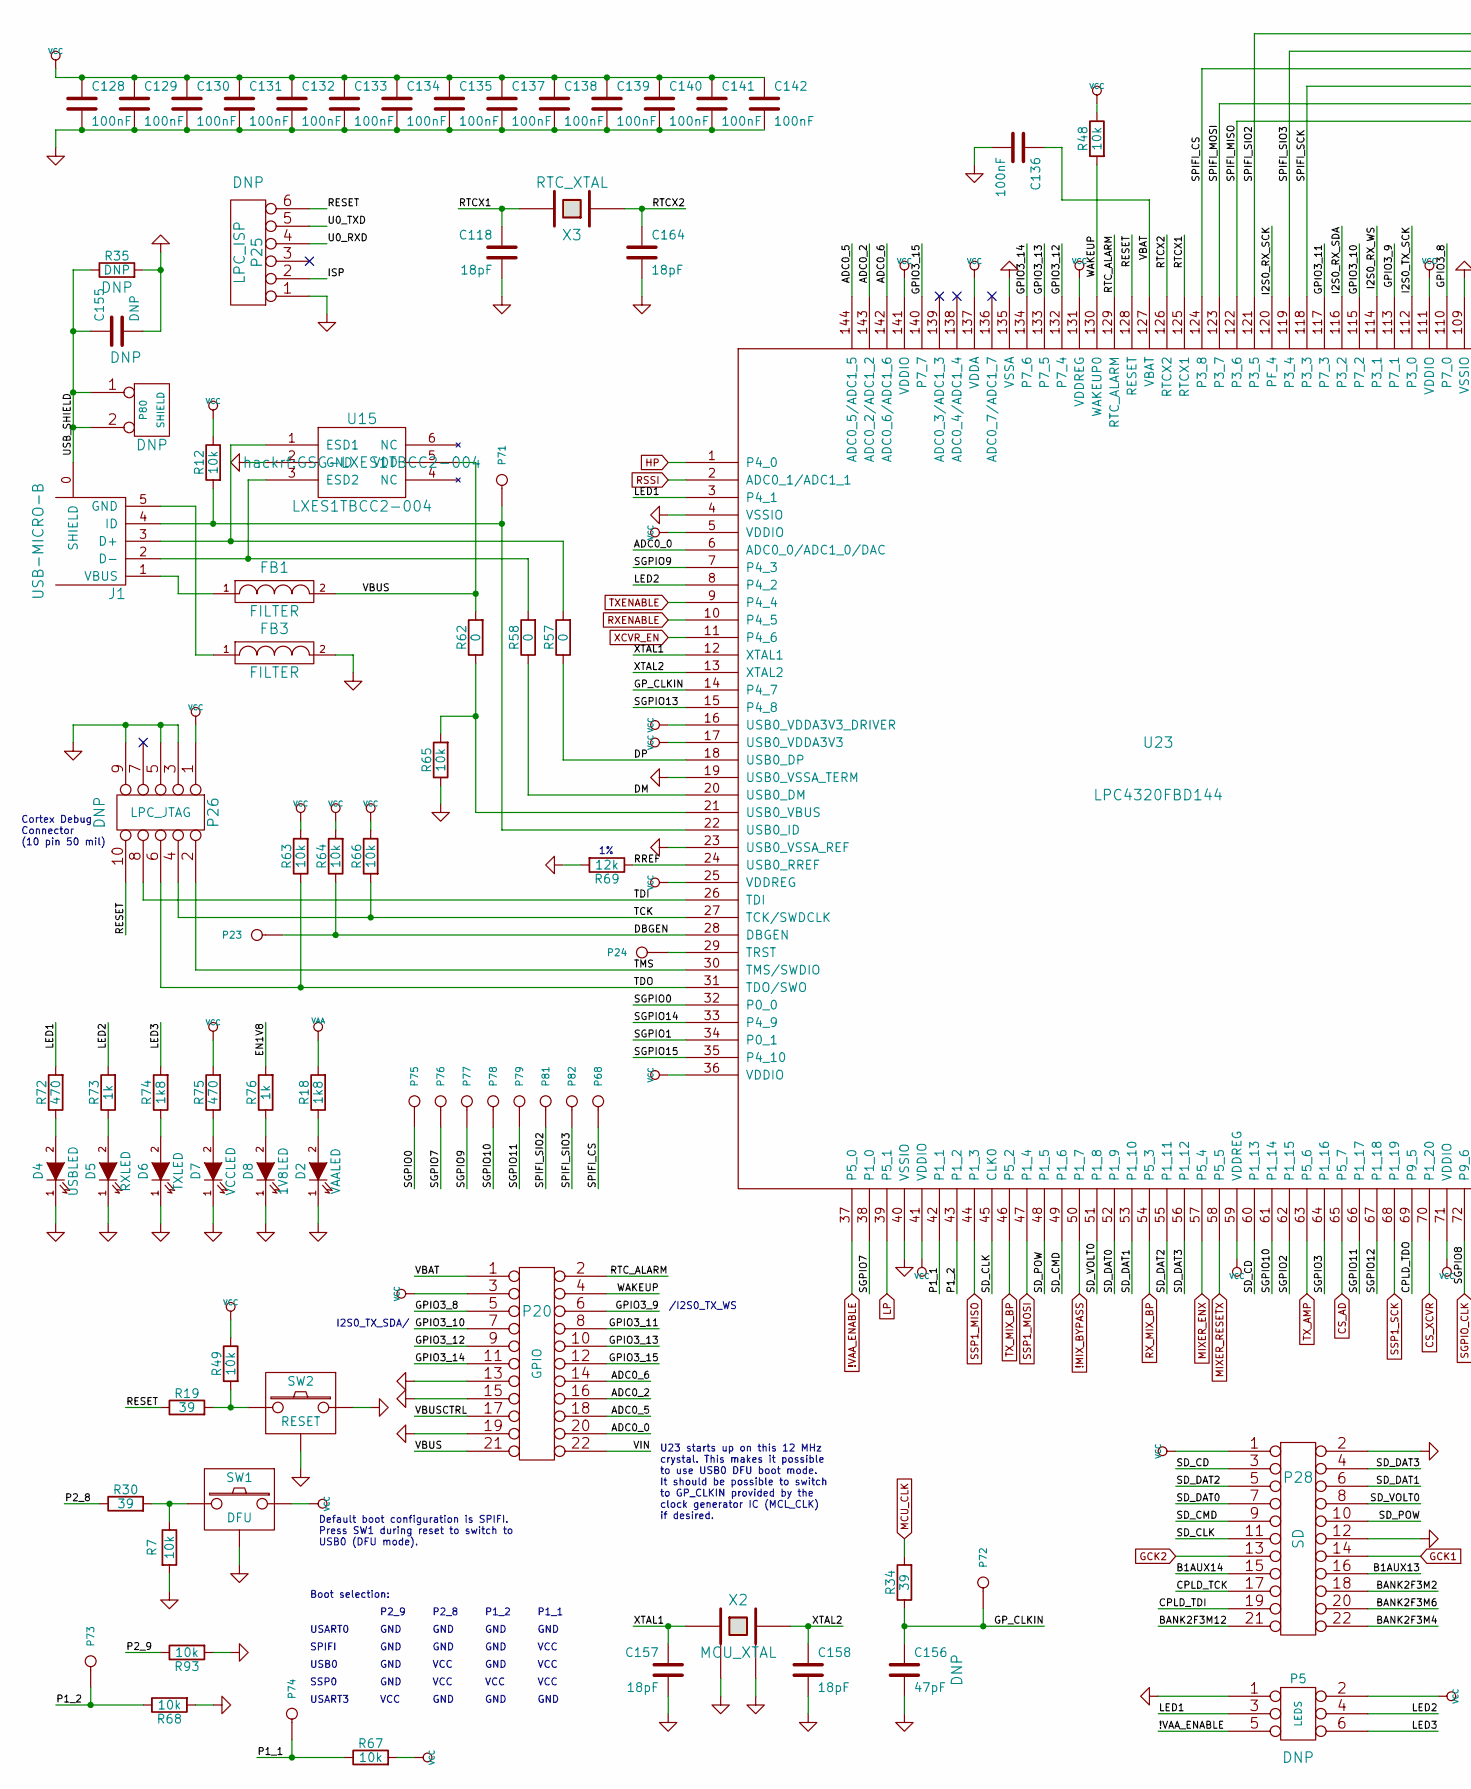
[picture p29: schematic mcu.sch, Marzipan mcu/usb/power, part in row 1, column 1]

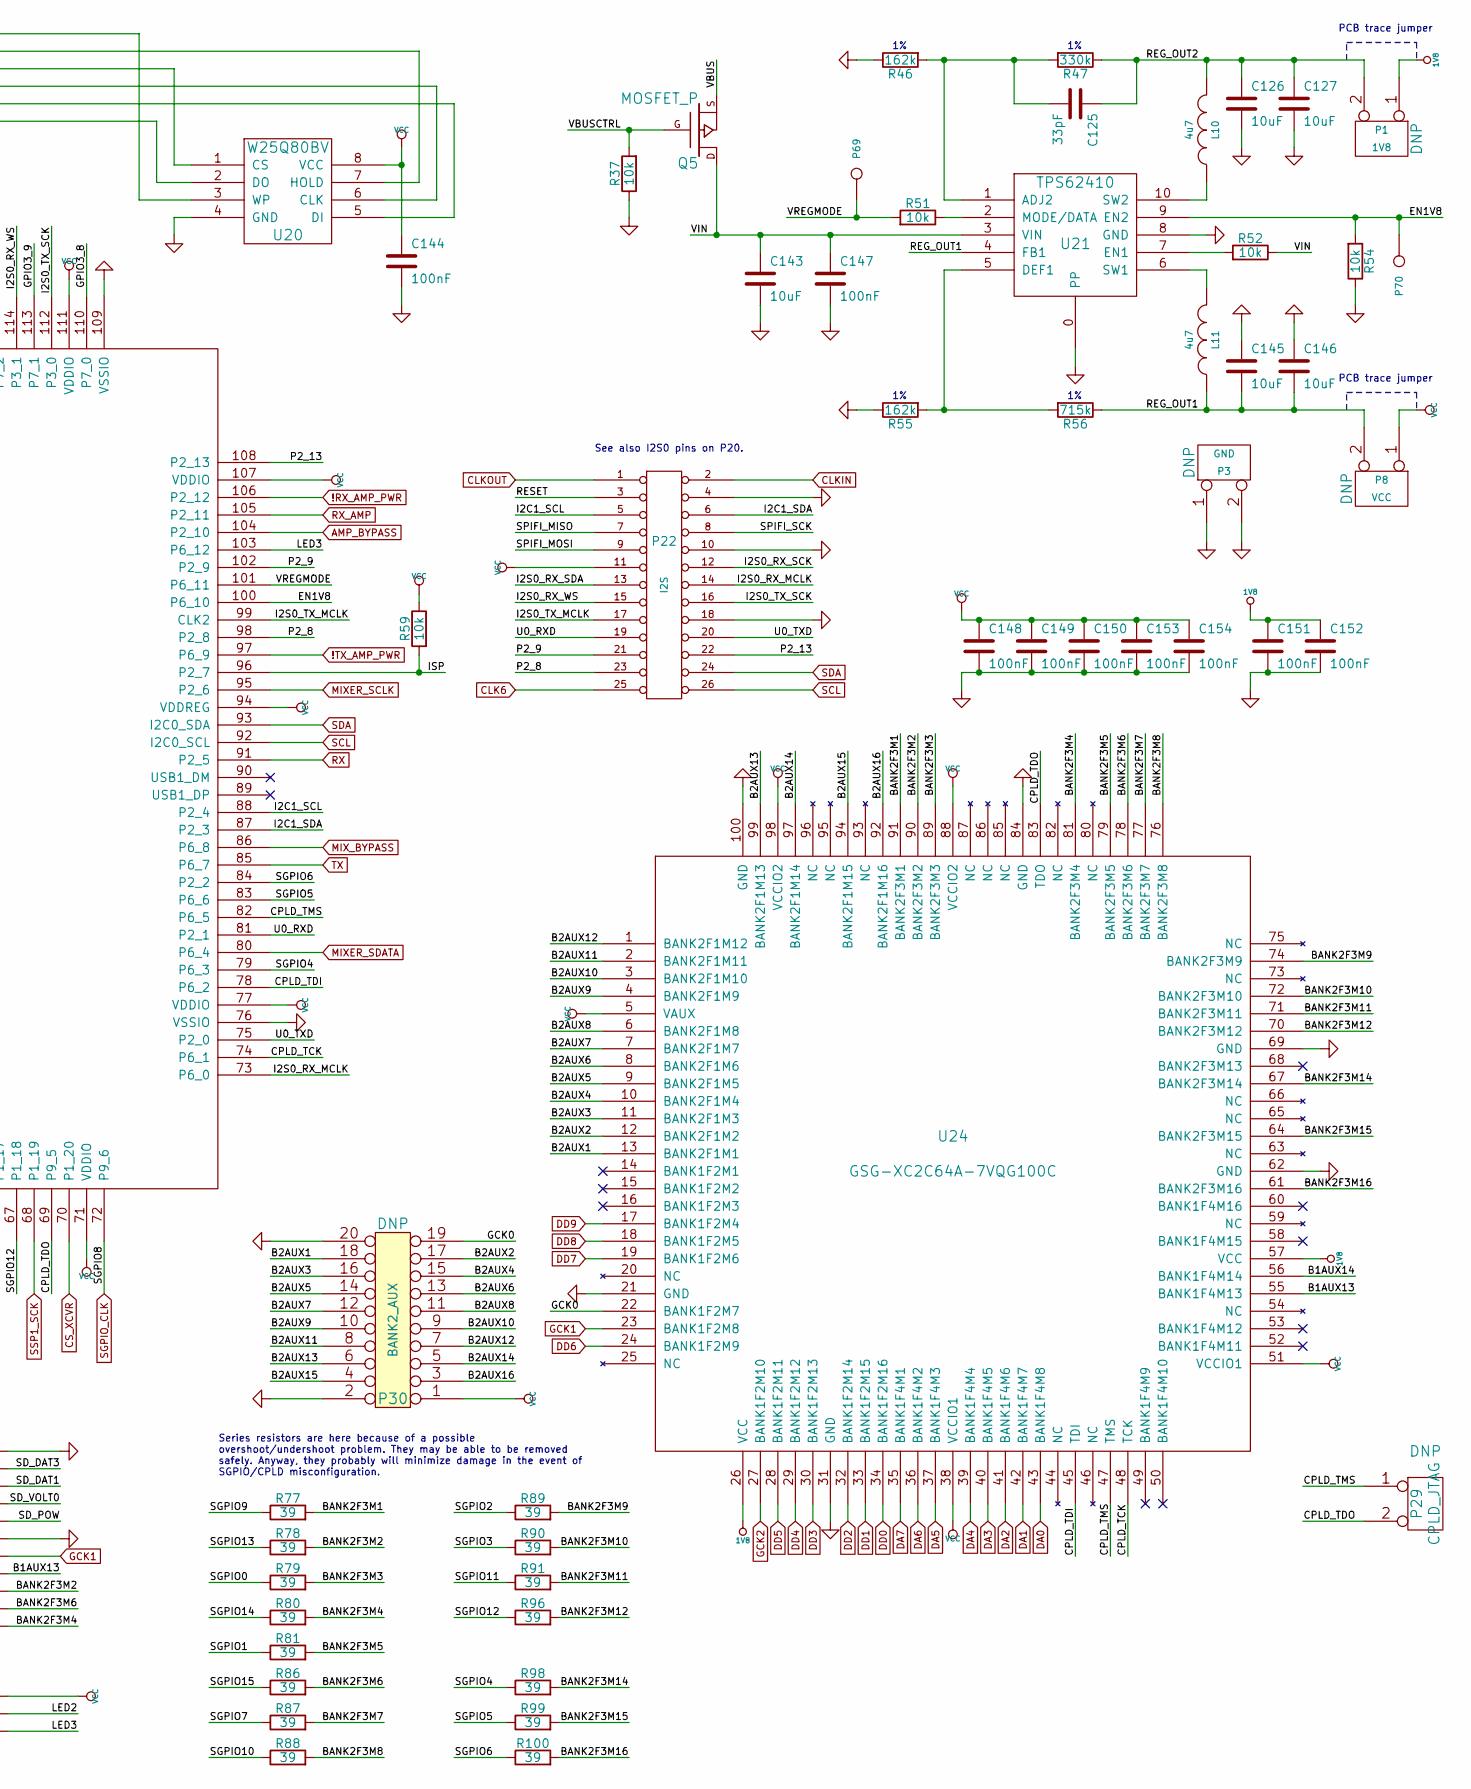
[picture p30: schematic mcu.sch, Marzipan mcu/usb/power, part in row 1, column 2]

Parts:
C118, C157, C158, C164: 18pF; GSG-0402; Part Number GRM1555C1H180JA01D
C125: 33pF; GSG-0402; Part Number GRM1555C1H330JA01D
C126, C127, C143, C145, C146: 10uF; GSG-0805; Part Number GRM21BR61A106KE19L
C128, C129, C130, C131, C132, C133, C134, C135, C136, C137, C138, C139, C140, C141, C142, C144, C147, C148, C149, C150, C151, C152, C153, C154: 100nF; GSG-0402; Part Number GRM155R61A104KA01D
C155: DNP; GSG-0805
C156: 47pF; GSG-0402; Part Number GRM1555C1H470JA01D
D2: VAALED; LTST-S220; Part Number LTST-S220KRKT
D4: USBLED; LTST-S220; Part Number LTST-S220KGKT
D5: RXLED; LTST-S220; Part Number LTST-S220KSKT
D6: TXLED; LTST-S220; Part Number LTST-S220KRKT
D7: VCCLED; LTST-S220; Part Number LTST-S220KGKT
D8: 1V8LED; LTST-S220; Part Number LTST-S220KSKT
FB1, FB3: FILTER; GSG-0805; Part Number BLM21PG221SN1D
J1: USB-MICRO-B; GSG-USB-MICROB-FCI-10103592-EXT; Part Number 10103592-0001LF
L10, L11: 4u7; GSG-NRG4026; Part Number NRG4026T4R7M
P1: 1V8; GSG-HEADER-1x2
P3: GND; GSG-HEADER-NOMARK-1x2
P5: LEDS; GSG-HEADER-2x3
P8: VCC; GSG-HEADER-1x2
P20: GPIO; GSG-HEADER-2x11; Part Number PPPC112LFBN-RC
P22: I2S; GSG-HEADER-2x13; Part Number PPPC132LFBN-RC
P23: DBGEN; GSG-TESTPOINT-50MIL
P24: TRST; GSG-TESTPOINT-50MIL
P25: LPC_ISP; GSG-HEADER-1x6
P26: LPC_JTAG; GSG-50MIL-HEADER-2x5-TH; Part Number GRPB052VWVN-RC
P28: SD; GSG-HEADER-2x11; Part Number PPPC112LFBN-RC
P29: CPLD_JTAG; GSG-HEADER-1x2
P30: BANK2_AUX; GSG-HEADER-2x10
P68: SPIFI_CS; GSG-TESTPOINT-50MIL
P69: VREGMODE; GSG-TESTPOINT-50MIL
P70: EN_1V8; GSG-TESTPOINT-50MIL
P71: ID; GSG-TESTPOINT-50MIL
P72, P75, P76, P77, P78, P79: GP_CLKIN; GSG-TESTPOINT-50MIL
P73: P1_2; GSG-TESTPOINT-50MIL
P74: P1_1; GSG-TESTPOINT-50MIL
P80: SHIELD; GSG-HEADER-NOMARK-1x2
P81: SPIFI_SIO2; GSG-TESTPOINT-50MIL
P82: SPIFI_SIO3; GSG-TESTPOINT-50MIL
Q5: MOSFET_P; SOT23GDS; Part Number AO3407A
R7, R12, R37, R48, R49, R51, R52, R54, R59, R63, R64, R65, R66, R67, R68, R93: 10k; GSG-0402; Part Number RMCF0402JT10K0
R18, R74: 1k8; GSG-0402; Part Number RMCF0402JT1K80
R19, R30, R34, R77, R78, R79, R80, R81, R86, R87, R88, R89, R90, R91, R96, R98, R99, R100: 39; GSG-0402; Part Number RMCF0402JT39R0
R35: DNP; GSG-0805
R46, R55: 162k; GSG-0402; Part Number RMCF0402FT162K
R47: 330k; GSG-0402; Part Number RMCF0402FT330K
R56: 715k; GSG-0402; Part Number RMCF0402FT715K
R57, R58, R62: 0; GSG-0402; Part Number RMCF0402ZT0R00
R69: 12k; GSG-0402; Part Number MCR01MRTF1202
R72, R75: 470; GSG-0402; Part Number RMCF0402JT470R
R73, R76: 1k; GSG-0402; Part Number RMCF0402FT1K00
SW1: DFU; GSG-SWITCH-FSMRA; Part Number FSMRA3JH
SW2: RESET; GSG-SWITCH-FSMRA; Part Number FSMRA3JH
U15: LXES1TBCC2-004; GSG-LXES1TBCC2-004; Part Number LXES1TBCC2-004
U20: W25Q80BV; GSG-SOIC8-208; Part Number W25Q80BVSSIG
U21: TPS62410; GSG-S-PVSON-N10; Part Number TPS62410DRCR
U23: LPC4320FBD144; GSG-LQFP144; Part Number LPC4320FBD144,551
U24: GSG-XC2C64A-7VQG100C; GSG-VQ100; Part Number XC2C64A-7VQG100C
X2: MCU_XTAL; GSG-XTAL3.2x2.5mm; Part Number 7V-12.000MAAE-T
X3: RTC_XTAL; GSG-XTAL-AB26TRQ; Part Number AB26TRQ-32.768KHZ-T

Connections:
!MIX_BYPASS: U23.50 (P1_7); also elsewhere on the board
!RX_AMP_PWR: U23.106 (P2_12); also elsewhere on the board
!TX_AMP_PWR: U23.97 (P6_9); also elsewhere on the board
!VAA_ENABLE: P5.5, U23.37 (P5_0); also elsewhere on the board
+1.8V: C151.1, C152.1, P1.1, U24.26 (VCC), U24.57 (VCC)
/mcu/usb/power/ADC0_0: P20.20, U23.6 (ADC0_0/ADC1_0/DAC)
/mcu/usb/power/ADC0_2: P20.16, U23.143 (ADC0_2/ADC1_2)
/mcu/usb/power/ADC0_5: P20.18, U23.144 (ADC0_5/ADC1_5)
/mcu/usb/power/ADC0_6: P20.14, U23.142 (ADC0_6/ADC1_6)
/mcu/usb/power/B1AUX13: P28.16, U24.55 (BANK1F4M13)
/mcu/usb/power/B1AUX14: P28.15, U24.56 (BANK1F4M14)
/mcu/usb/power/B2AUX1: P30.18, U24.13 (BANK2F1M1)
/mcu/usb/power/B2AUX2: P30.17, U24.12 (BANK2F1M2)
/mcu/usb/power/B2AUX3: P30.16, U24.11 (BANK2F1M3)
/mcu/usb/power/B2AUX4: P30.15, U24.10 (BANK2F1M4)
/mcu/usb/power/B2AUX5: P30.14, U24.9 (BANK2F1M5)
/mcu/usb/power/B2AUX6: P30.13, U24.8 (BANK2F1M6)
/mcu/usb/power/B2AUX7: P30.12, U24.7 (BANK2F1M7)
/mcu/usb/power/B2AUX8: P30.11, U24.6 (BANK2F1M8)
/mcu/usb/power/B2AUX9: P30.10, U24.4 (BANK2F1M9)
/mcu/usb/power/B2AUX10: P30.9, U24.3 (BANK2F1M10)
/mcu/usb/power/B2AUX11: P30.8, U24.2 (BANK2F1M11)
/mcu/usb/power/B2AUX12: P30.7, U24.1 (BANK2F1M12)
/mcu/usb/power/B2AUX13: P30.6, U24.99 (BANK2F1M13)
/mcu/usb/power/B2AUX14: P30.5, U24.97 (BANK2F1M14)
/mcu/usb/power/B2AUX15: P30.4, U24.94 (BANK2F1M15)
/mcu/usb/power/B2AUX16: P30.3, U24.92 (BANK2F1M16)
/mcu/usb/power/BANK2F3M1: R77.2, U24.91 (BANK2F3M1)
/mcu/usb/power/BANK2F3M2: P28.18, R78.2, U24.90 (BANK2F3M2)
/mcu/usb/power/BANK2F3M3: R79.2, U24.89 (BANK2F3M3)
/mcu/usb/power/BANK2F3M4: P28.22, R80.2, U24.81 (BANK2F3M4)
/mcu/usb/power/BANK2F3M5: R81.2, U24.79 (BANK2F3M5)
/mcu/usb/power/BANK2F3M6: P28.20, R86.2, U24.78 (BANK2F3M6)
/mcu/usb/power/BANK2F3M7: R87.2, U24.77 (BANK2F3M7)
/mcu/usb/power/BANK2F3M8: R88.2, U24.76 (BANK2F3M8)
/mcu/usb/power/BANK2F3M9: R89.2, U24.74 (BANK2F3M9)
/mcu/usb/power/BANK2F3M10: R90.2, U24.72 (BANK2F3M10)
/mcu/usb/power/BANK2F3M11: R91.2, U24.71 (BANK2F3M11)
/mcu/usb/power/BANK2F3M12: P28.21, R96.2, U24.70 (BANK2F3M12)
/mcu/usb/power/BANK2F3M14: R98.2, U24.67 (BANK2F3M14)
/mcu/usb/power/BANK2F3M15: R99.2, U24.64 (BANK2F3M15)
/mcu/usb/power/BANK2F3M16: R100.2, U24.61 (BANK2F3M16)
/mcu/usb/power/CPLD_TCK: P28.17, U23.74 (P6_1), U24.48 (TCK)
/mcu/usb/power/CPLD_TDI: P28.19, U23.78 (P6_2), U24.45 (TDI)
/mcu/usb/power/CPLD_TDO: P29.2 (PM), U23.69 (P9_5), U24.83 (TDO)
/mcu/usb/power/CPLD_TMS: P29.1, U23.82 (P6_5), U24.47 (TMS)
/mcu/usb/power/DBGEN: P23.1, R64.1, U23.28 (DBGEN)
/mcu/usb/power/DM: R58.1, U23.20 (USB0_DM)
/mcu/usb/power/DP: R57.1, U23.18 (USB0_DP)
/mcu/usb/power/EN1V8: P70.1, R54.2, R76.2, U21.9 (EN2), U23.100 (P6_10)
/mcu/usb/power/GCK0: P30.19, U24.22 (BANK1F2M7)
/mcu/usb/power/GPIO3_8: P20.5, U23.110 (P7_0)
/mcu/usb/power/GPIO3_9: P20.6, U23.113 (P7_1)
/mcu/usb/power/GPIO3_10: P20.7, U23.115 (P7_2)
/mcu/usb/power/GPIO3_11: P20.8, U23.117 (P7_3)
/mcu/usb/power/GPIO3_12: P20.9, U23.132 (P7_4)
/mcu/usb/power/GPIO3_13: P20.10, U23.133 (P7_5)
/mcu/usb/power/GPIO3_14: P20.11, U23.134 (P7_6)
/mcu/usb/power/GPIO3_15: P20.12, U23.140 (P7_7)
/mcu/usb/power/GP_CLKIN: C156.1, P72.1, R34.1, U23.14 (P4_7)
/mcu/usb/power/I2C1_SCL: P22.5, U23.88 (P2_4)
/mcu/usb/power/I2C1_SDA: P22.6, U23.87 (P2_3)
/mcu/usb/power/I2S0_RX_MCLK: P22.14, U23.73 (P6_0)
/mcu/usb/power/I2S0_RX_SCK: P22.12, U23.120 (PF_4)
/mcu/usb/power/I2S0_RX_SDA: P22.13, U23.116 (P3_2)
/mcu/usb/power/I2S0_RX_WS: P22.15, U23.114 (P3_1)
/mcu/usb/power/I2S0_TX_MCLK: P22.17, U23.99 (CLK2)
/mcu/usb/power/I2S0_TX_SCK: P22.16, U23.112 (P3_0)
/mcu/usb/power/ISP: P25.2, R59.2, U23.96 (P2_7)
/mcu/usb/power/LED1: P5.3, R72.2, U23.3 (P4_1)
/mcu/usb/power/LED2: P5.4, R73.2, U23.8 (P4_2)
/mcu/usb/power/LED3: P5.6, R74.2, U23.103 (P6_12)
/mcu/usb/power/P1_1: P74.1, R67.1, U23.42 (P1_1)
/mcu/usb/power/P1_2: P73.1, R68.1, U23.43 (P1_2)
/mcu/usb/power/P2_8: P22.23, R30.1, U23.98 (P2_8)
/mcu/usb/power/P2_9: P22.21, R93.1, U23.102 (P2_9)
/mcu/usb/power/P2_13: P22.22, U23.108 (P2_13)
/mcu/usb/power/REG_OUT1: C145.2, C146.2, L11.1, P8.2 (PM), R56.1, U21.4 (FB1)
/mcu/usb/power/REG_OUT2: C125.1, C126.1, C127.1, L10.2, P1.2 (PM), R47.1
/mcu/usb/power/RESET: P22.3, P25.6, P26.10, R19.1, U23.128 (RESET)
/mcu/usb/power/RREF: R69.1, U23.24 (USB0_RREF)
/mcu/usb/power/RTCX1: C118.1, U23.125 (RTCX1), X3.2
/mcu/usb/power/RTCX2: C164.1, U23.126 (RTCX2), X3.1
/mcu/usb/power/RTC_ALARM: P20.2, U23.129 (RTC_ALARM)
/mcu/usb/power/SD_CD: P28.3, U23.60 (P1_13)
/mcu/usb/power/SD_CLK: P28.11, U23.45 (CLK0)
/mcu/usb/power/SD_CMD: P28.9, U23.49 (P1_6)
/mcu/usb/power/SD_DAT0: P28.7, U23.52 (P1_9)
/mcu/usb/power/SD_DAT1: P28.6, U23.53 (P1_10)
/mcu/usb/power/SD_DAT2: P28.5, U23.55 (P1_11)
/mcu/usb/power/SD_DAT3: P28.4, U23.56 (P1_12)
/mcu/usb/power/SD_POW: P28.10, U23.48 (P1_5)
/mcu/usb/power/SD_VOLT0: P28.8, U23.51 (P1_8)
/mcu/usb/power/SGPIO0: P75.1, R79.1, U23.32 (P0_0)
/mcu/usb/power/SGPIO1: R81.1, U23.34 (P0_1)
/mcu/usb/power/SGPIO2: R89.1, U23.62 (P1_15)
/mcu/usb/power/SGPIO3: R90.1, U23.64 (P1_16)
/mcu/usb/power/SGPIO4: R98.1, U23.79 (P6_3)
/mcu/usb/power/SGPIO5: R99.1, U23.83 (P6_6)
/mcu/usb/power/SGPIO6: R100.1, U23.84 (P2_2)
/mcu/usb/power/SGPIO7: P76.1, R87.1, U23.38 (P1_0)
/mcu/usb/power/SGPIO9: P77.1, R77.1, U23.7 (P4_3)
/mcu/usb/power/SGPIO10: P78.1, R88.1, U23.61 (P1_14)
/mcu/usb/power/SGPIO11: P79.1, R91.1, U23.66 (P1_17)
/mcu/usb/power/SGPIO12: R96.1, U23.67 (P1_18)
/mcu/usb/power/SGPIO13: R78.1, U23.15 (P4_8)
/mcu/usb/power/SGPIO14: R80.1, U23.33 (P4_9)
/mcu/usb/power/SGPIO15: R86.1, U23.35 (P4_10)
/mcu/usb/power/SPIFI_CS: P68.1, U20.1 (CS), U23.124 (P3_8)
/mcu/usb/power/SPIFI_MISO: P22.7, U20.2 (DO), U23.122 (P3_6)
/mcu/usb/power/SPIFI_MOSI: P22.9, U20.5 (DI), U23.123 (P3_7)
/mcu/usb/power/SPIFI_SCK: P22.8, U20.6 (CLK), U23.118 (P3_3)
/mcu/usb/power/SPIFI_SIO2: P81.1, U20.3 (WP), U23.121 (P3_5)
/mcu/usb/power/SPIFI_SIO3: P82.1, U20.7 (HOLD), U23.119 (P3_4)
/mcu/usb/power/TCK: P26.4, R66.2, U23.27 (TCK/SWDCLK)
/mcu/usb/power/TDI: P26.8, U23.26 (TDI)
/mcu/usb/power/TDO: P26.6, R63.1, U23.31 (TDO/SWO)
/mcu/usb/power/TMS: P26.2, U23.30 (TMS/SWDIO)
/mcu/usb/power/U0_RXD: P22.19, P25.4, U23.81 (P2_1)
/mcu/usb/power/U0_TXD: P22.20, P25.5, U23.75 (P2_0)
/mcu/usb/power/USB_SHIELD: C155.1, J1.0 (SHIELD), P80.1, P80.2 (PM), R35.1
/mcu/usb/power/VBAT: C136.1, P20.1, U23.127 (VBAT)
/mcu/usb/power/VBUS: FB1.2, P20.21, Q5.S, R62.2, U15.5 (VDD)
/mcu/usb/power/VBUSCTRL: P20.17, Q5.G, R37.2
/mcu/usb/power/VIN: C143.1, C147.1, P20.22, Q5.D, R52.1, U21.3 (VIN)
/mcu/usb/power/VREGMODE: P69.1, R51.2, U23.101 (P6_11)
/mcu/usb/power/WAKEUP: P20.4, R48.2, U23.130 (WAKEUP0)
/mcu/usb/power/XTAL1: C157.1, U23.12 (XTAL1), X2.1
/mcu/usb/power/XTAL2: C158.1, U23.13 (XTAL2), X2.3
AMP_BYPASS: U23.104 (P2_10); also elsewhere on the board
CLK6: P22.25 (P24); also elsewhere on the board
CLKIN: P22.2; also elsewhere on the board
CLKOUT: P22.1; also elsewhere on the board
CS_AD: U23.65 (P5_7); also elsewhere on the board
CS_XCVR: U23.70 (P1_20); also elsewhere on the board
DA0: U24.43 (BANK1F4M8); also elsewhere on the board
DA1: U24.42 (BANK1F4M7); also elsewhere on the board
DA2: U24.41 (BANK1F4M6); also elsewhere on the board
DA3: U24.40 (BANK1F4M5); also elsewhere on the board
DA4: U24.39 (BANK1F4M4); also elsewhere on the board
DA5: U24.37 (BANK1F4M3); also elsewhere on the board
DA6: U24.36 (BANK1F4M2); also elsewhere on the board
DA7: U24.35 (BANK1F4M1); also elsewhere on the board
DD0: U24.34 (BANK1F2M16); also elsewhere on the board
DD1: U24.33 (BANK1F2M15); also elsewhere on the board
DD2: U24.32 (BANK1F2M14); also elsewhere on the board
DD3: U24.30 (BANK1F2M13); also elsewhere on the board
DD4: U24.29 (BANK1F2M12); also elsewhere on the board
DD5: U24.28 (BANK1F2M11); also elsewhere on the board
DD6: U24.24 (BANK1F2M9); also elsewhere on the board
DD7: U24.19 (BANK1F2M6); also elsewhere on the board
DD8: U24.18 (BANK1F2M5); also elsewhere on the board
DD9: U24.17 (BANK1F2M4); also elsewhere on the board
GCK1: P28.14, U24.23 (BANK1F2M8); also elsewhere on the board
GCK2: P28.13, U24.27 (BANK1F2M10); also elsewhere on the board
GND: C118.2, C126.2, C127.2, C128.2, C129.2, C130.2, C131.2, C132.2, C133.2, C134.2, C135.2, C136.2, C137.2, C138.2, C139.2, C140.2, C141.2, C142.2, C143.2, C144.2, C145.1, C146.1, C147.2, C148.2, C149.2, C150.2, C151.2, C152.2, C153.2, C154.2, C155.2, C156.2, C157.2, C158.2, C164.2, D2.1 (K), D4.1 (K), D5.1 (K), D6.1 (K), D7.1 (K), D8.1 (K), FB3.2, P3.1, P3.2 (PM), P5.1, P20.13, P20.15, P20.19, P22.4, P22.10, P22.18, P25.1, P26.3, P26.5, P26.9, P28.2, P28.12, P30.2, P30.20, R7.2, R35.2, R37.1, R46.1, R54.1, R55.1, R65.1, R68.2, R69.2, R93.2, SW1.0 (SHIELD), SW2.0 (SHIELD), SW2.1, U15.2 (GND), U20.4 (GND), U21.0 (PP), U21.8 (GND), U23.4 (VSSIO), U23.19 (USB0_VSSA_TERM), U23.23 (USB0_VSSA_REF), U23.40 (VSSIO), U23.76 (VSSIO), U23.109 (VSSIO), U23.135 (VSSA), U24.21 (GND), U24.31 (GND), U24.62 (GND), U24.69 (GND), U24.84 (GND), U24.100 (GND), X2.2, X2.4; also elsewhere on the board
HP: U23.1 (P4_0); also elsewhere on the board
LP: U23.39 (P5_1); also elsewhere on the board
MCU_CLK: R34.2; also elsewhere on the board
MIXER_ENX: U23.57 (P5_4); also elsewhere on the board
MIXER_RESETX: U23.58 (P5_5); also elsewhere on the board
MIXER_SCLK: U23.95 (P2_6); also elsewhere on the board
MIXER_SDATA: U23.80 (P6_4); also elsewhere on the board
MIX_BYPASS: U23.86 (P6_8); also elsewhere on the board
unnamed: C125.2, R46.2, R47.2, U21.1 (ADJ2)
unnamed: D2.2 (A), R18.1
unnamed: D4.2 (A), R72.1
unnamed: D5.2 (A), R73.1
unnamed: D6.2 (A), R74.1
unnamed: D7.2 (A), R75.1
unnamed: D8.2 (A), R76.1
unnamed: FB1.1, J1.1 (VBUS)
unnamed: FB3.1, J1.5 (GND)
unnamed: J1.2 (D-), R58.2, U15.3 (ESD2)
unnamed: J1.3 (D+), R57.2, U15.1 (ESD1)
unnamed: J1.4 (ID), P71.1, R12.2, U23.22 (USB0_ID)
unnamed: L10.1, U21.10 (SW2)
unnamed: L11.2, U21.6 (SW1)
unnamed: P24.1, U23.29 (TRST)
unnamed: R19.2, R49.2, SW2.2
unnamed: R7.1, R30.2, SW1.2
unnamed: R51.1, U21.2 (MODE/DATA)
unnamed: R52.2, U21.7 (EN1)
unnamed: R55.2, R56.2, U21.5 (DEF1)
unnamed: R62.1, R65.2, U23.21 (USB0_VBUS)
RSSI: U23.2 (ADC0_1/ADC1_1); also elsewhere on the board
RX: U23.91 (P2_5); also elsewhere on the board
RXENABLE: U23.10 (P4_5); also elsewhere on the board
RX_AMP: U23.105 (P2_11); also elsewhere on the board
RX_MIX_BP: U23.54 (P5_3); also elsewhere on the board
SCL: P22.26 (P22), U23.92 (I2C0_SCL); also elsewhere on the board
SDA: P22.24 (P20), U23.93 (I2C0_SDA); also elsewhere on the board
SGPIO_CLK: U23.72 (P9_6); also elsewhere on the board
SSP1_MISO: U23.44 (P1_3); also elsewhere on the board
SSP1_MOSI: U23.47 (P1_4); also elsewhere on the board
SSP1_SCK: U23.68 (P1_19); also elsewhere on the board
TX: U23.85 (P6_7); also elsewhere on the board
TXENABLE: U23.9 (P4_4); also elsewhere on the board
TX_AMP: U23.63 (P5_6); also elsewhere on the board
TX_MIX_BP: U23.46 (P5_2); also elsewhere on the board
VAA: R18.2; also elsewhere on the board
VCC: C128.1, C129.1, C130.1, C131.1, C132.1, C133.1, C134.1, C135.1, C137.1, C138.1, C139.1, C140.1, C141.1, C142.1, C144.1, C148.1, C149.1, C150.1, C153.1, C154.1, P5.2, P8.1, P20.3, P22.11, P26.1, P28.1, P30.1, R12.1, R48.1, R49.1, R59.1, R63.2, R64.2, R66.1, R67.2, R75.2, SW1.1, U20.8 (VCC), U23.5 (VDDIO), U23.16 (USB0_VDDA3V3_DRIVER), U23.17 (USB0_VDDA3V3), U23.25 (VDDREG), U23.36 (VDDIO), U23.41 (VDDIO), U23.59 (VDDREG), U23.71 (VDDIO), U23.77 (VDDIO), U23.94 (VDDREG), U23.107 (VDDIO), U23.111 (VDDIO), U23.131 (VDDREG), U23.137 (VDDA), U23.141 (VDDIO), U24.5 (VAUX), U24.38 (VCCIO1), U24.51 (VCCIO1), U24.88 (VCCIO2), U24.98 (VCCIO2); also elsewhere on the board
XCVR_EN: U23.11 (P4_6); also elsewhere on the board

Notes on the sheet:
Cortex Debug Connector (10 pin 50 mil)
U23 starts up on this 12 MHz crystal. This makes it possible to use USB0 DFU boot mode. It should be possible to switch to GP_CLKIN provided by the clock generator IC (MCL_CLK) if desired.
GND
VCC
P1_1
P1_2
P2_8
P2_9
USART3
SSP0
USB0
SPIFI
USART0
Boot selection:
Default boot configuration is SPIFI. Press SW1 during reset to switch to USB0 (DFU mode).
Series resistors are here because of a possible overshoot/undershoot problem. They may be able to be removed safely. Anyway, they probably will minimize damage in the event of SGPIO/CPLD misconfiguration.
/I2S0_TX_WS
I2S0_TX_SDA/
See also I2S0 pins on P20.
PCB trace jumper

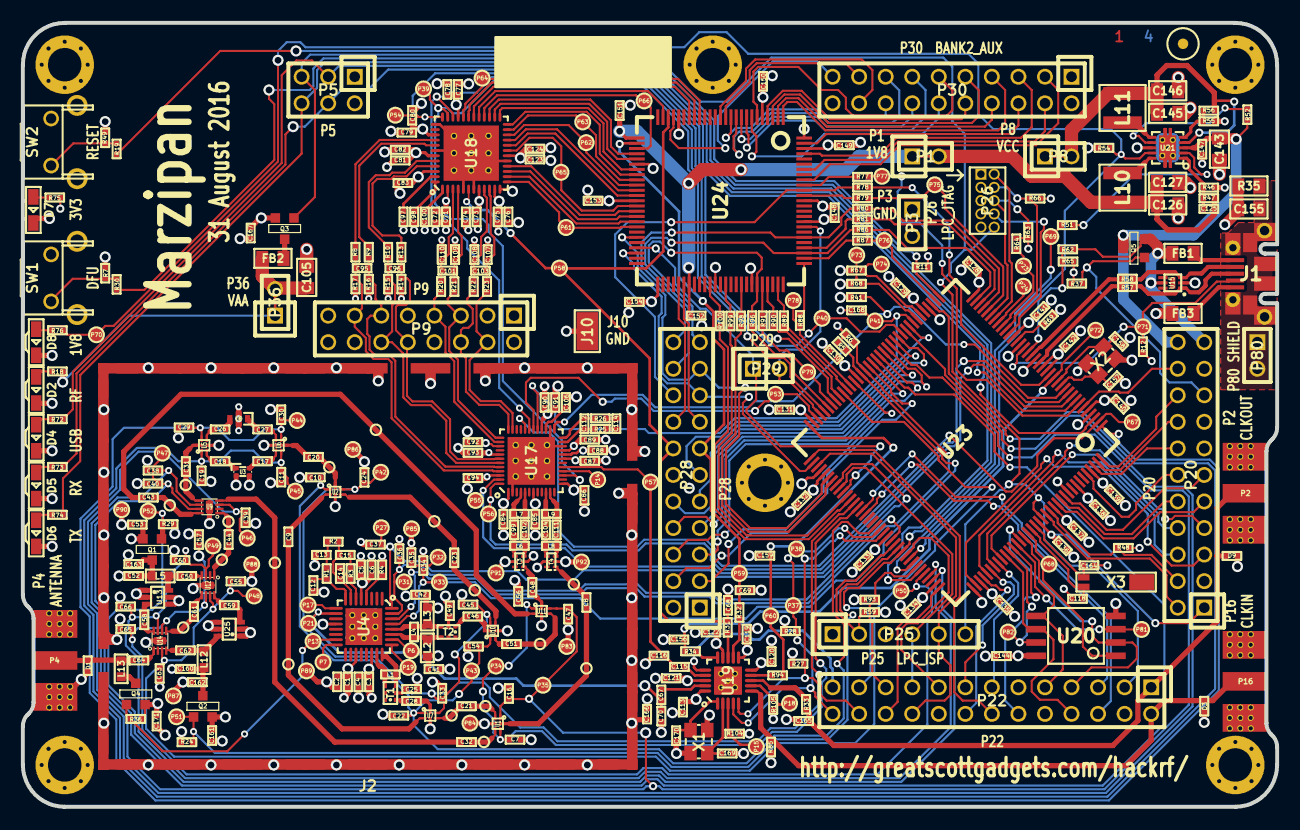
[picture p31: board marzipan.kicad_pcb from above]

Board: 4 copper layers, 120.0 x 75.0 mm, 432 parts (0 on the bottom side), 316 nets.

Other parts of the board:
MARK1MM: VAL**; GSG-MARK1MM
TESTPOINT-30MIL-MASKONLY, TESTPOINT-30MIL-MASKONLY#2, TESTPOINT-30MIL-MASKONLY#3, TESTPOINT-30MIL-MASKONLY#4, TESTPOINT-30MIL-MASKONLY#5, TESTPOINT-30MIL-MASKONLY#6, TESTPOINT-30MIL-MASKONLY#7, TESTPOINT-30MIL-MASKONLY#8, TESTPOINT-30MIL-MASKONLY#9, TESTPOINT-30MIL-MASKONLY#10, TESTPOINT-30MIL-MASKONLY#11, TESTPOINT-30MIL-MASKONLY#12, TESTPOINT-30MIL-MASKONLY#13, TESTPOINT-30MIL-MASKONLY#14, TESTPOINT-30MIL-MASKONLY#15, TESTPOINT-30MIL-MASKONLY#16, TESTPOINT-30MIL-MASKONLY#17: VAL**; GSG-TESTPOINT-30MIL-MASKONLY

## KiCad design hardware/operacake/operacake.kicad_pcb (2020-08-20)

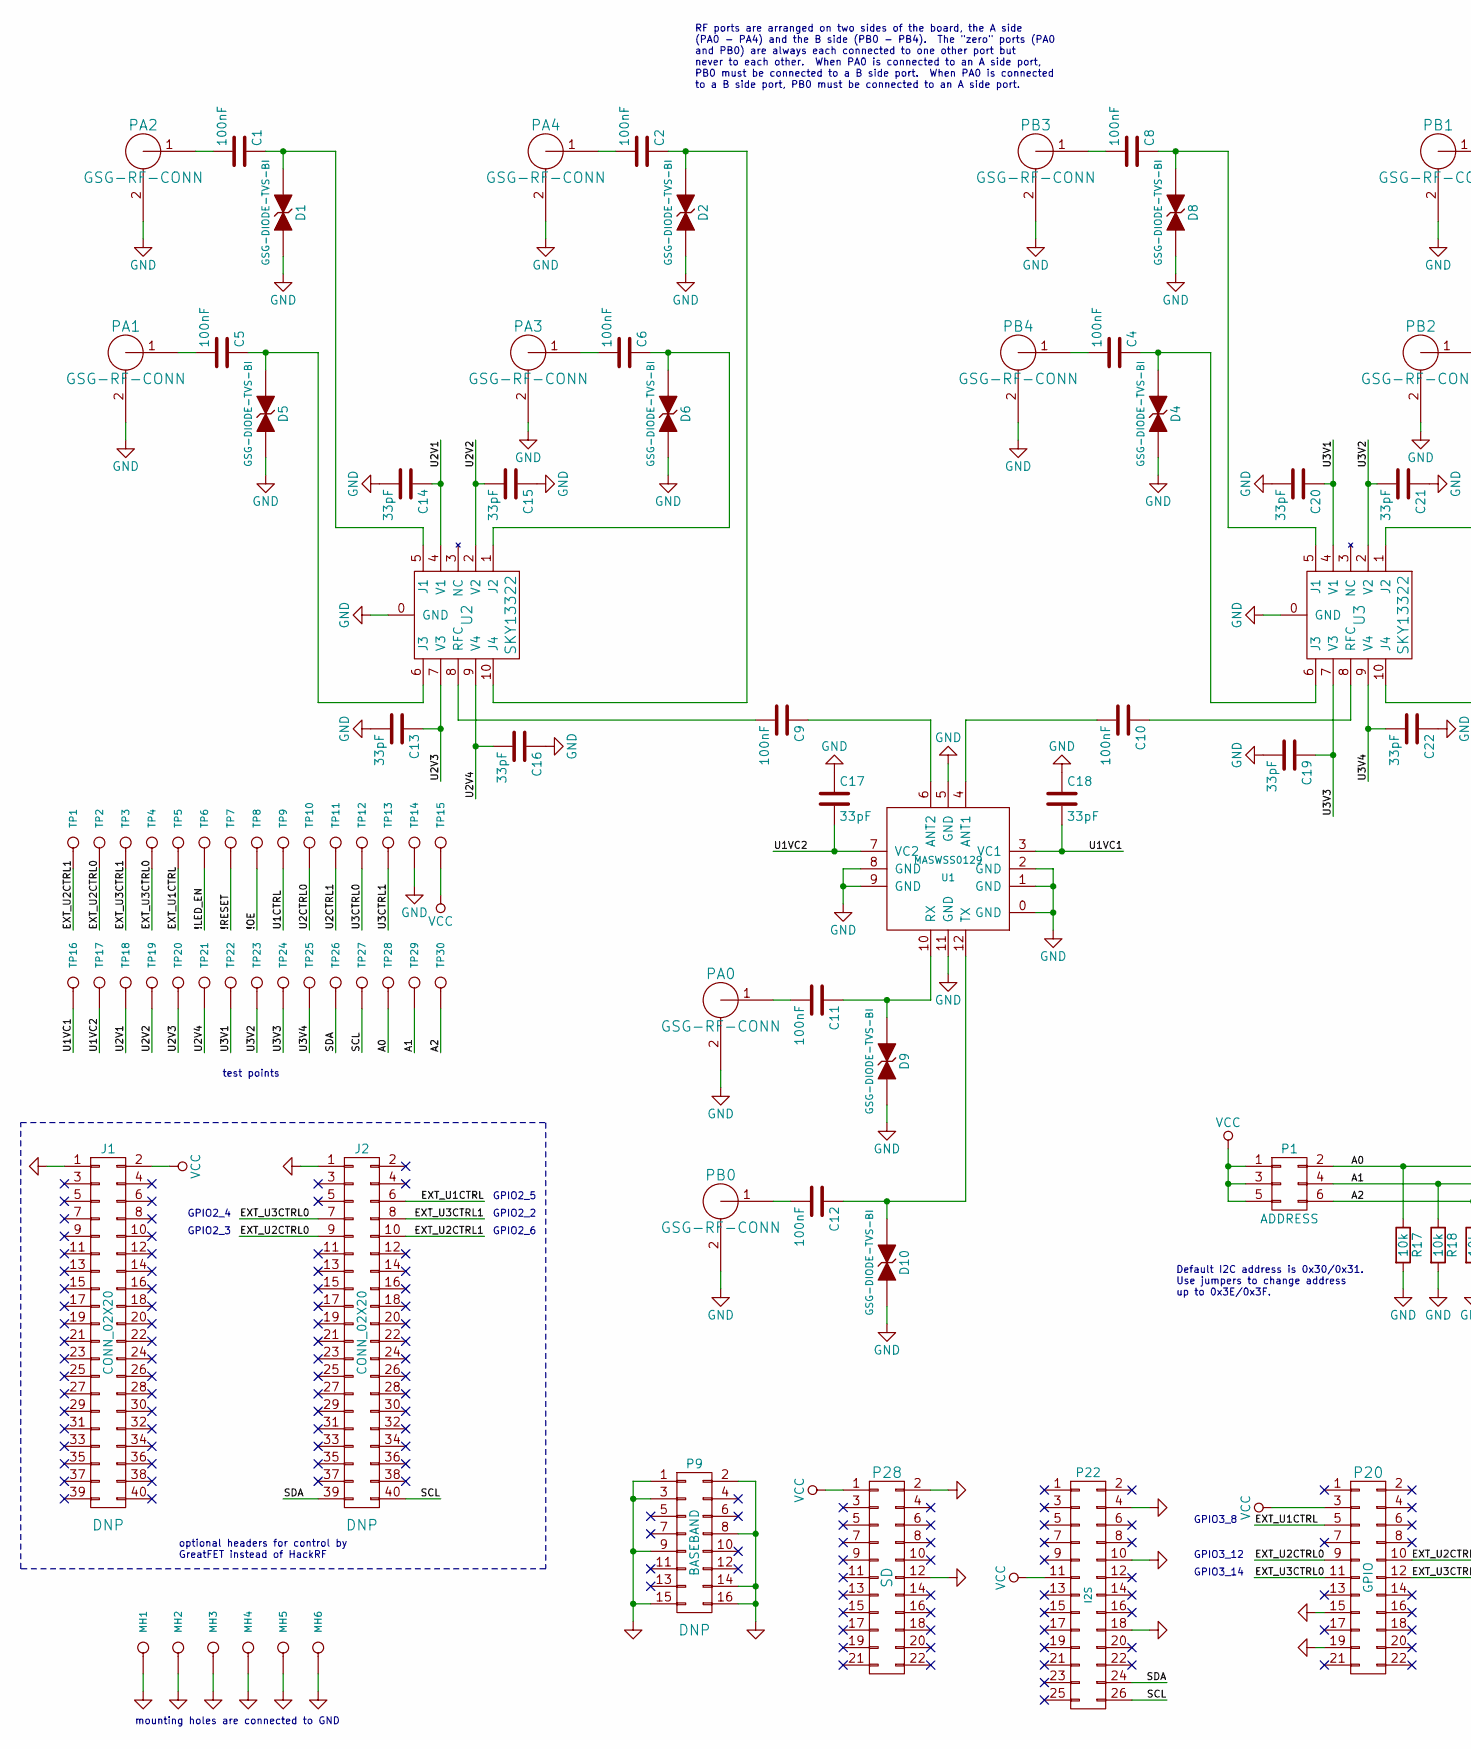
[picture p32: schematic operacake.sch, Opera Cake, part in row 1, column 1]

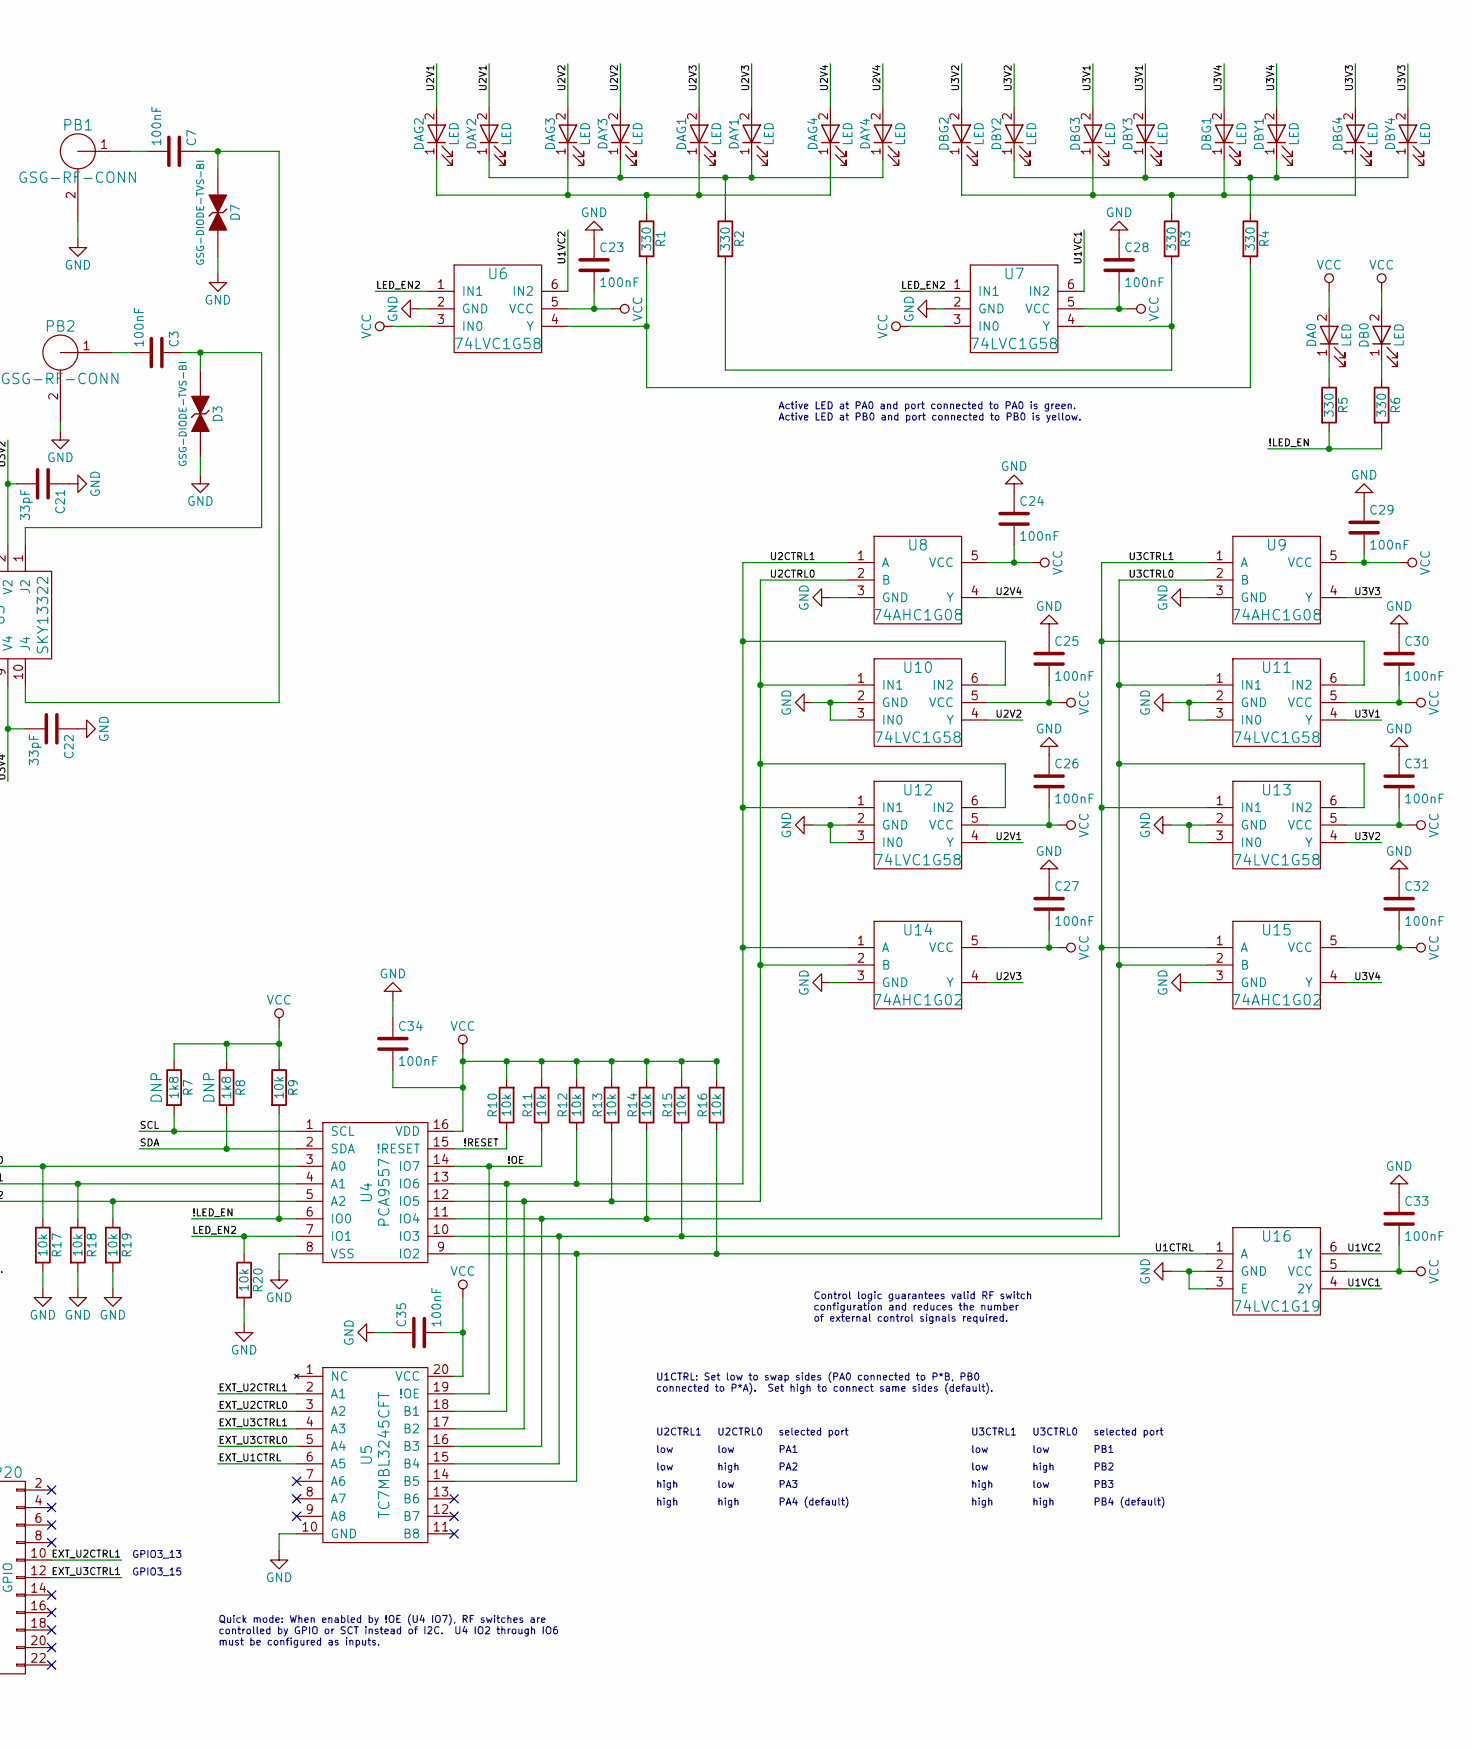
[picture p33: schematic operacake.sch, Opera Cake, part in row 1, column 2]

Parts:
C1, C2, C3, C4, C5, C6, C7, C8, C9, C10, C11, C12, C23, C24, C25, C26, C27, C28, C29, C30, C31, C32, C33, C34, C35: 100nF; 0402; Part Number GRM155R61A104KA01D
C13, C14, C15, C16, C17, C18, C19, C20, C21, C22: 33pF; 0402; Part Number GRM1555C1H330JA01D
D1, D2, D3, D4, D5, D6, D7, D8, D9, D10: GSG-DIODE-TVS-BI; 0402; Part Number LXES15AAA1-153
DA0: LED; 0603D; Part Number SML-LX0603GW-TR
DAG1, DAG2, DAG3, DAG4: LED; 0603D; Part Number SML-LX0603GW-TR
DAY1, DAY2, DAY3, DAY4: LED; 0603D; Part Number SML-LX0603YW-TR
DB0: LED; 0603D; Part Number SML-LX0603YW-TR
DBG1, DBG2, DBG3, DBG4: LED; 0603D; Part Number SML-LX0603GW-TR
DBY1, DBY2, DBY3, DBY4: LED; 0603D; Part Number SML-LX0603YW-TR
J1, J2: CONN_02X20; HEADER-2x20-REVERSE
MH1, MH2, MH3, MH4, MH5, MH6: MOUNTING_HOLE; HOLE126MIL-COPPER
P1: ADDRESS; HEADER-2x3; Part Number XG8T-0631
P9: BASEBAND; HEADER-2x8; Part Number SSQ-108-03-G-D
P20: GPIO; HEADER-2x11; Part Number SSQ-111-03-G-D
P22: I2S; HEADER-2x13; Part Number SSQ-113-03-G-D
P28: SD; HEADER-2x11; Part Number SSQ-111-03-G-D
PA0, PA1, PA2, PA3, PA4: GSG-RF-CONN; GSG-SMA-73251-2120; Part Number 73251-2121
PB0, PB1, PB2, PB3, PB4: GSG-RF-CONN; GSG-SMA-73251-2120; Part Number 73251-2121
R1, R2, R3, R4, R5, R6: 330; 0603; Part Number RMCF0603JT330R
R7, R8: 1k8; 0603
R9, R10, R11, R12, R13, R14, R15, R16, R17, R18, R19, R20: 10k; 0603; Part Number ERJ-3GEYJ103V
TP1, TP2, TP3, TP4, TP5, TP6, TP7, TP8, TP9, TP10, TP11, TP12, TP13, TP14, TP15, TP16, TP17, TP18, TP19, TP20, TP21, TP22, TP23, TP24, TP25, TP26, TP27, TP28, TP29, TP30: CONN_1; TESTPOINT-50MIL
U1: MASWSS0129; QFN12-3; Part Number MASWSS0129TR-3000
U2, U3: SKY13322; SKY13322-375LF; Part Number SKY13322-375LF
U4: PCA9557; TSSOP16; Part Number PCA9557PW,118
U5: TC7MBL3245CFT; TSSOP20; Part Number TC7MBL3245CFT(EL)
U6, U7, U10, U11, U12, U13: 74LVC1G58; SOT363; Part Number 74LVC1G58DW-7
U8, U9: 74AHC1G08; SOT353-1; Part Number 74AHC1G08SE-7
U14, U15: 74AHC1G02; SOT353-1; Part Number 74AHC1G02SE-7
U16: 74LVC1G19; SOT363; Part Number 74LVC1G19GW,125

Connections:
/!LED_EN: R5.2, R6.2, R9.2, TP6.1, U4.6 (IO0)
/!OE: R11.1, TP8.1, U4.14 (IO7), U5.19 (!OE)
/!RESET: R10.1, TP7.1, U4.15 (!RESET)
/A0: P1.2, R17.1, TP28.1, U4.3 (A0)
/A1: P1.4, R18.1, TP29.1, U4.4 (A1)
/A2: P1.6, R19.1, TP30.1, U4.5 (A2)
/EXT_U1CTRL: J2.6, P20.5, TP5.1, U5.6 (A5)
/EXT_U2CTRL0: J2.9, P20.9, TP2.1, U5.3 (A2)
/EXT_U2CTRL1: J2.10, P20.10, TP1.1, U5.2 (A1)
/EXT_U3CTRL0: J2.7, P20.11, TP4.1, U5.5 (A4)
/EXT_U3CTRL1: J2.8, P20.12, TP3.1, U5.4 (A3)
/LED_EN2: R20.1, U4.7 (IO1), U6.1 (IN1), U7.1 (IN1)
/SCL: J2.40, P22.26, R7.2, TP27.1, U4.1 (SCL)
/SDA: J2.39, P22.24, R8.2, TP26.1, U4.2 (SDA)
/U1CTRL: R16.1, TP9.1, U4.9 (IO2), U5.14 (B5), U16.1 (A)
/U1VC1: C18.2, TP16.1, U1.3 (VC1), U7.6 (IN2), U16.4 (2Y)
/U1VC2: C17.2, TP17.1, U1.7 (VC2), U6.6 (IN2), U16.6 (1Y)
/U2CTRL0: R13.1, TP10.1, U4.12 (IO5), U5.17 (B2), U8.2 (B), U10.1 (IN1), U12.6 (IN2), U14.2 (B)
/U2CTRL1: R12.1, TP11.1, U4.13 (IO6), U5.18 (B1), U8.1 (A), U10.6 (IN2), U12.1 (IN1), U14.1 (A)
/U2V1: C14.1, DAG2.2 (A), DAY2.2 (A), TP18.1, U2.4 (V1), U12.4 (Y)
/U2V2: C15.2, DAG3.2 (A), DAY3.2 (A), TP19.1, U2.2 (V2), U10.4 (Y)
/U2V3: C13.1, DAG1.2 (A), DAY1.2 (A), TP20.1, U2.7 (V3), U14.4 (Y)
/U2V4: C16.2, DAG4.2 (A), DAY4.2 (A), TP21.1, U2.9 (V4), U8.4 (Y)
/U3CTRL0: R15.1, TP12.1, U4.10 (IO3), U5.15 (B4), U9.2 (B), U11.1 (IN1), U13.6 (IN2), U15.2 (B)
/U3CTRL1: R14.1, TP13.1, U4.11 (IO4), U5.16 (B3), U9.1 (A), U11.6 (IN2), U13.1 (IN1), U15.1 (A)
/U3V1: C20.1, DBG3.2 (A), DBY3.2 (A), TP22.1, U3.4 (V1), U11.4 (Y)
/U3V2: C21.2, DBG2.2 (A), DBY2.2 (A), TP23.1, U3.2 (V2), U13.4 (Y)
/U3V3: C19.1, DBG4.2 (A), DBY4.2 (A), TP24.1, U3.7 (V3), U9.4 (Y)
/U3V4: C22.2, DBG1.2 (A), DBY1.2 (A), TP25.1, U3.9 (V4), U15.4 (Y)
GND: C13.2, C14.2, C15.1, C16.1, C17.1, C18.1, C19.2, C20.2, C21.1, C22.1, C23.1, C24.1, C25.1, C26.1, C27.1, C28.1, C29.1, C30.1, C31.1, C32.1, C33.1, C34.1, C35.1, D1.2 (K), D2.2 (K), D3.2 (K), D4.2 (K), D5.2 (K), D6.2 (K), D7.2 (K), D8.2 (K), D9.2 (K), D10.2 (K), J1.1, J2.1, MH1.1, MH2.1, MH3.1, MH4.1, MH5.1, MH6.1, P9.1, P9.2, P9.3, P9.8, P9.9, P9.14, P9.15, P9.16, P20.15, P20.19, P22.4, P22.10, P22.18, P28.2, P28.12, PA0.2 (GND), PA1.2 (GND), PA2.2 (GND), PA3.2 (GND), PA4.2 (GND), PB0.2 (GND), PB1.2 (GND), PB2.2 (GND), PB3.2 (GND), PB4.2 (GND), R17.2, R18.2, R19.2, R20.2, TP14.1, U1.0 (GND), U1.1 (GND), U1.2 (GND), U1.5 (GND), U1.8 (GND), U1.9 (GND), U1.11 (GND), U2.0 (GND), U3.0 (GND), U4.8 (VSS), U5.10 (GND), U6.2 (GND), U7.2 (GND), U8.3 (GND), U9.3 (GND), U10.2 (GND), U10.3 (IN0), U11.2 (GND), U11.3 (IN0), U12.2 (GND), U12.3 (IN0), U13.2 (GND), U13.3 (IN0), U14.3 (GND), U15.3 (GND), U16.2 (GND), U16.3 (E)
unnamed: C1.1, D1.1 (A), U2.5 (J1)
unnamed: C1.2, PA2.1 (RF)
unnamed: C2.1, D2.1 (A), U2.10 (J4)
unnamed: C2.2, PA4.1 (RF)
unnamed: C3.1, D3.1 (A), U3.1 (J2)
unnamed: C3.2, PB2.1 (RF)
unnamed: C4.1, D4.1 (A), U3.6 (J3)
unnamed: C4.2, PB4.1 (RF)
unnamed: C5.1, D5.1 (A), U2.6 (J3)
unnamed: C5.2, PA1.1 (RF)
unnamed: C6.1, D6.1 (A), U2.1 (J2)
unnamed: C6.2, PA3.1 (RF)
unnamed: C7.1, D7.1 (A), U3.10 (J4)
unnamed: C7.2, PB1.1 (RF)
unnamed: C8.1, D8.1 (A), U3.5 (J1)
unnamed: C8.2, PB3.1 (RF)
unnamed: C9.1, U1.6 (ANT2)
unnamed: C9.2, U2.8 (RFC)
unnamed: C10.1, U3.8 (RFC)
unnamed: C10.2, U1.4 (ANT1)
unnamed: C11.1, D9.1 (A), U1.10 (RX)
unnamed: C11.2, PA0.1 (RF)
unnamed: C12.1, D10.1 (A), U1.12 (TX)
unnamed: C12.2, PB0.1 (RF)
unnamed: DA0.1 (K), R5.1
unnamed: DAG1.1 (K), DAG2.1 (K), DAG3.1 (K), DAG4.1 (K), R1.1
unnamed: DAY1.1 (K), DAY2.1 (K), DAY3.1 (K), DAY4.1 (K), R2.1
unnamed: DB0.1 (K), R6.1
unnamed: DBG1.1 (K), DBG2.1 (K), DBG3.1 (K), DBG4.1 (K), R3.1
unnamed: DBY1.1 (K), DBY2.1 (K), DBY3.1 (K), DBY4.1 (K), R4.1
unnamed: R1.2, R4.2, U6.4 (Y)
unnamed: R2.2, R3.2, U7.4 (Y)
VCC: C23.2, C24.2, C25.2, C26.2, C27.2, C28.2, C29.2, C30.2, C31.2, C32.2, C33.2, C34.2, C35.2, DA0.2 (A), DB0.2 (A), J1.2, P1.1, P1.3, P1.5, P20.3, P22.11, P28.1, R7.1, R8.1, R9.1, R10.2, R11.2, R12.2, R13.2, R14.2, R15.2, R16.2, TP15.1, U4.16 (VDD), U5.20 (VCC), U6.3 (IN0), U6.5 (VCC), U7.3 (IN0), U7.5 (VCC), U8.5 (VCC), U9.5 (VCC), U10.5 (VCC), U11.5 (VCC), U12.5 (VCC), U13.5 (VCC), U14.5 (VCC), U15.5 (VCC), U16.5 (VCC)

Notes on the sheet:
mounting holes are connected to GND
test points
Quick mode: When enabled by !OE (U4 IO7), RF switches are controlled by GPIO or SCT instead of I2C. U4 IO2 through IO6 must be configured as inputs.
Control logic guarantees valid RF switch configuration and reduces the number of external control signals required.
Active LED at PA0 and port connected to PA0 is green. Active LED at PB0 and port connected to PB0 is yellow.
Default I2C address is 0x30/0x31. Use jumpers to change address up to 0x3E/0x3F.
optional headers for control by GreatFET instead of HackRF
GPIO3_13
GPIO3_15
GPIO3_12
GPIO3_14
GPIO3_8
GPIO2_5
GPIO2_4
GPIO2_2
GPIO2_6
GPIO2_3
RF ports are arranged on two sides of the board, the A side (PA0 - PA4) and the B side (PB0 - PB4). The "zero" ports (PA0 and PB0) are always each connected to one other port but never to each other. When PA0 is connected to an A side port, PB0 must be connected to a B side port. When PA0 is connec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
U1CTRL: Set low to swap sides (PA0 connected to P*B, PB0 connected to P*A). Set high to connect same sides (default).
U2CTRL1
U2CTRL0
selected port
low
high
PA1
PA2
PA3
PA4 (default)
U3CTRL1
U3CTRL0
PB1
PB2
PB3
PB4 (default)

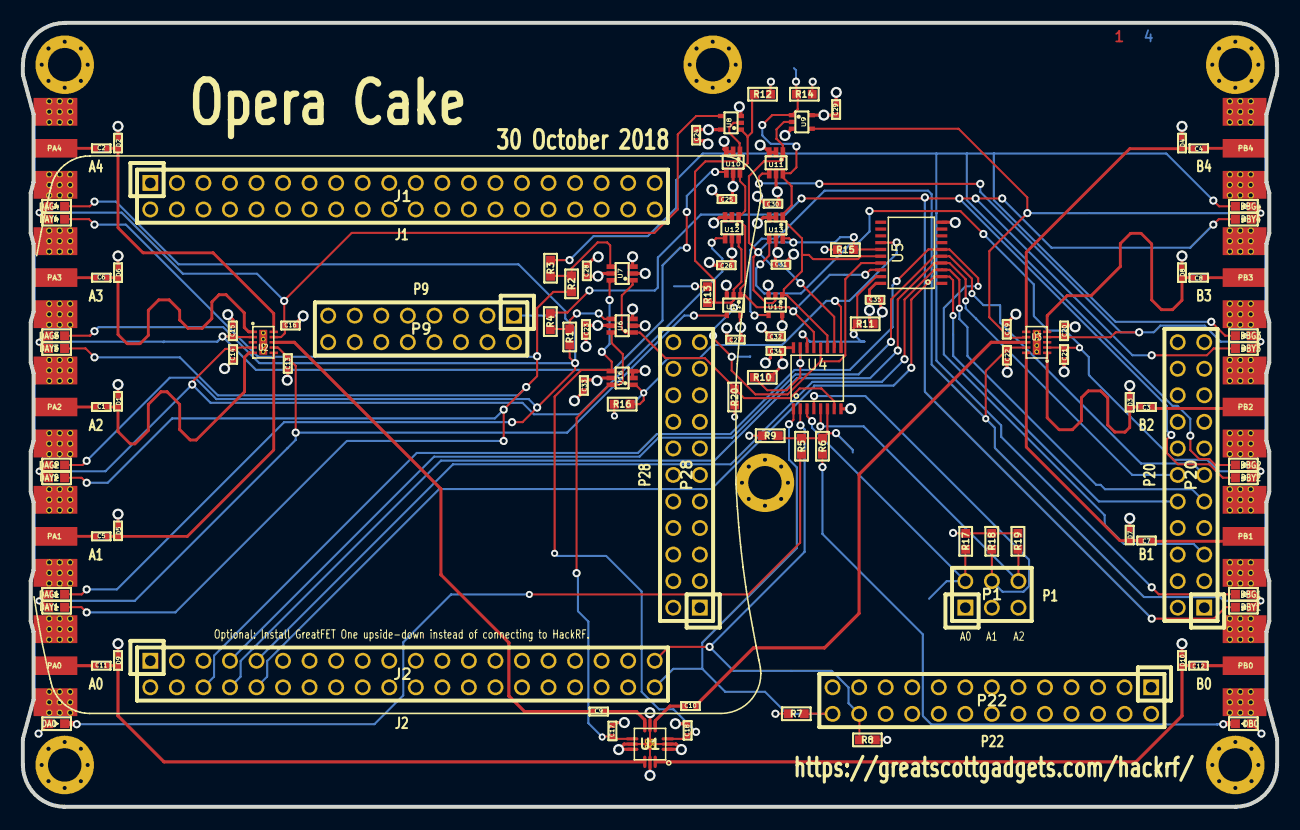
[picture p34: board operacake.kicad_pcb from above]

Board: 4 copper layers, 120.0 x 75.0 mm, 152 parts (0 on the bottom side), 63 nets.

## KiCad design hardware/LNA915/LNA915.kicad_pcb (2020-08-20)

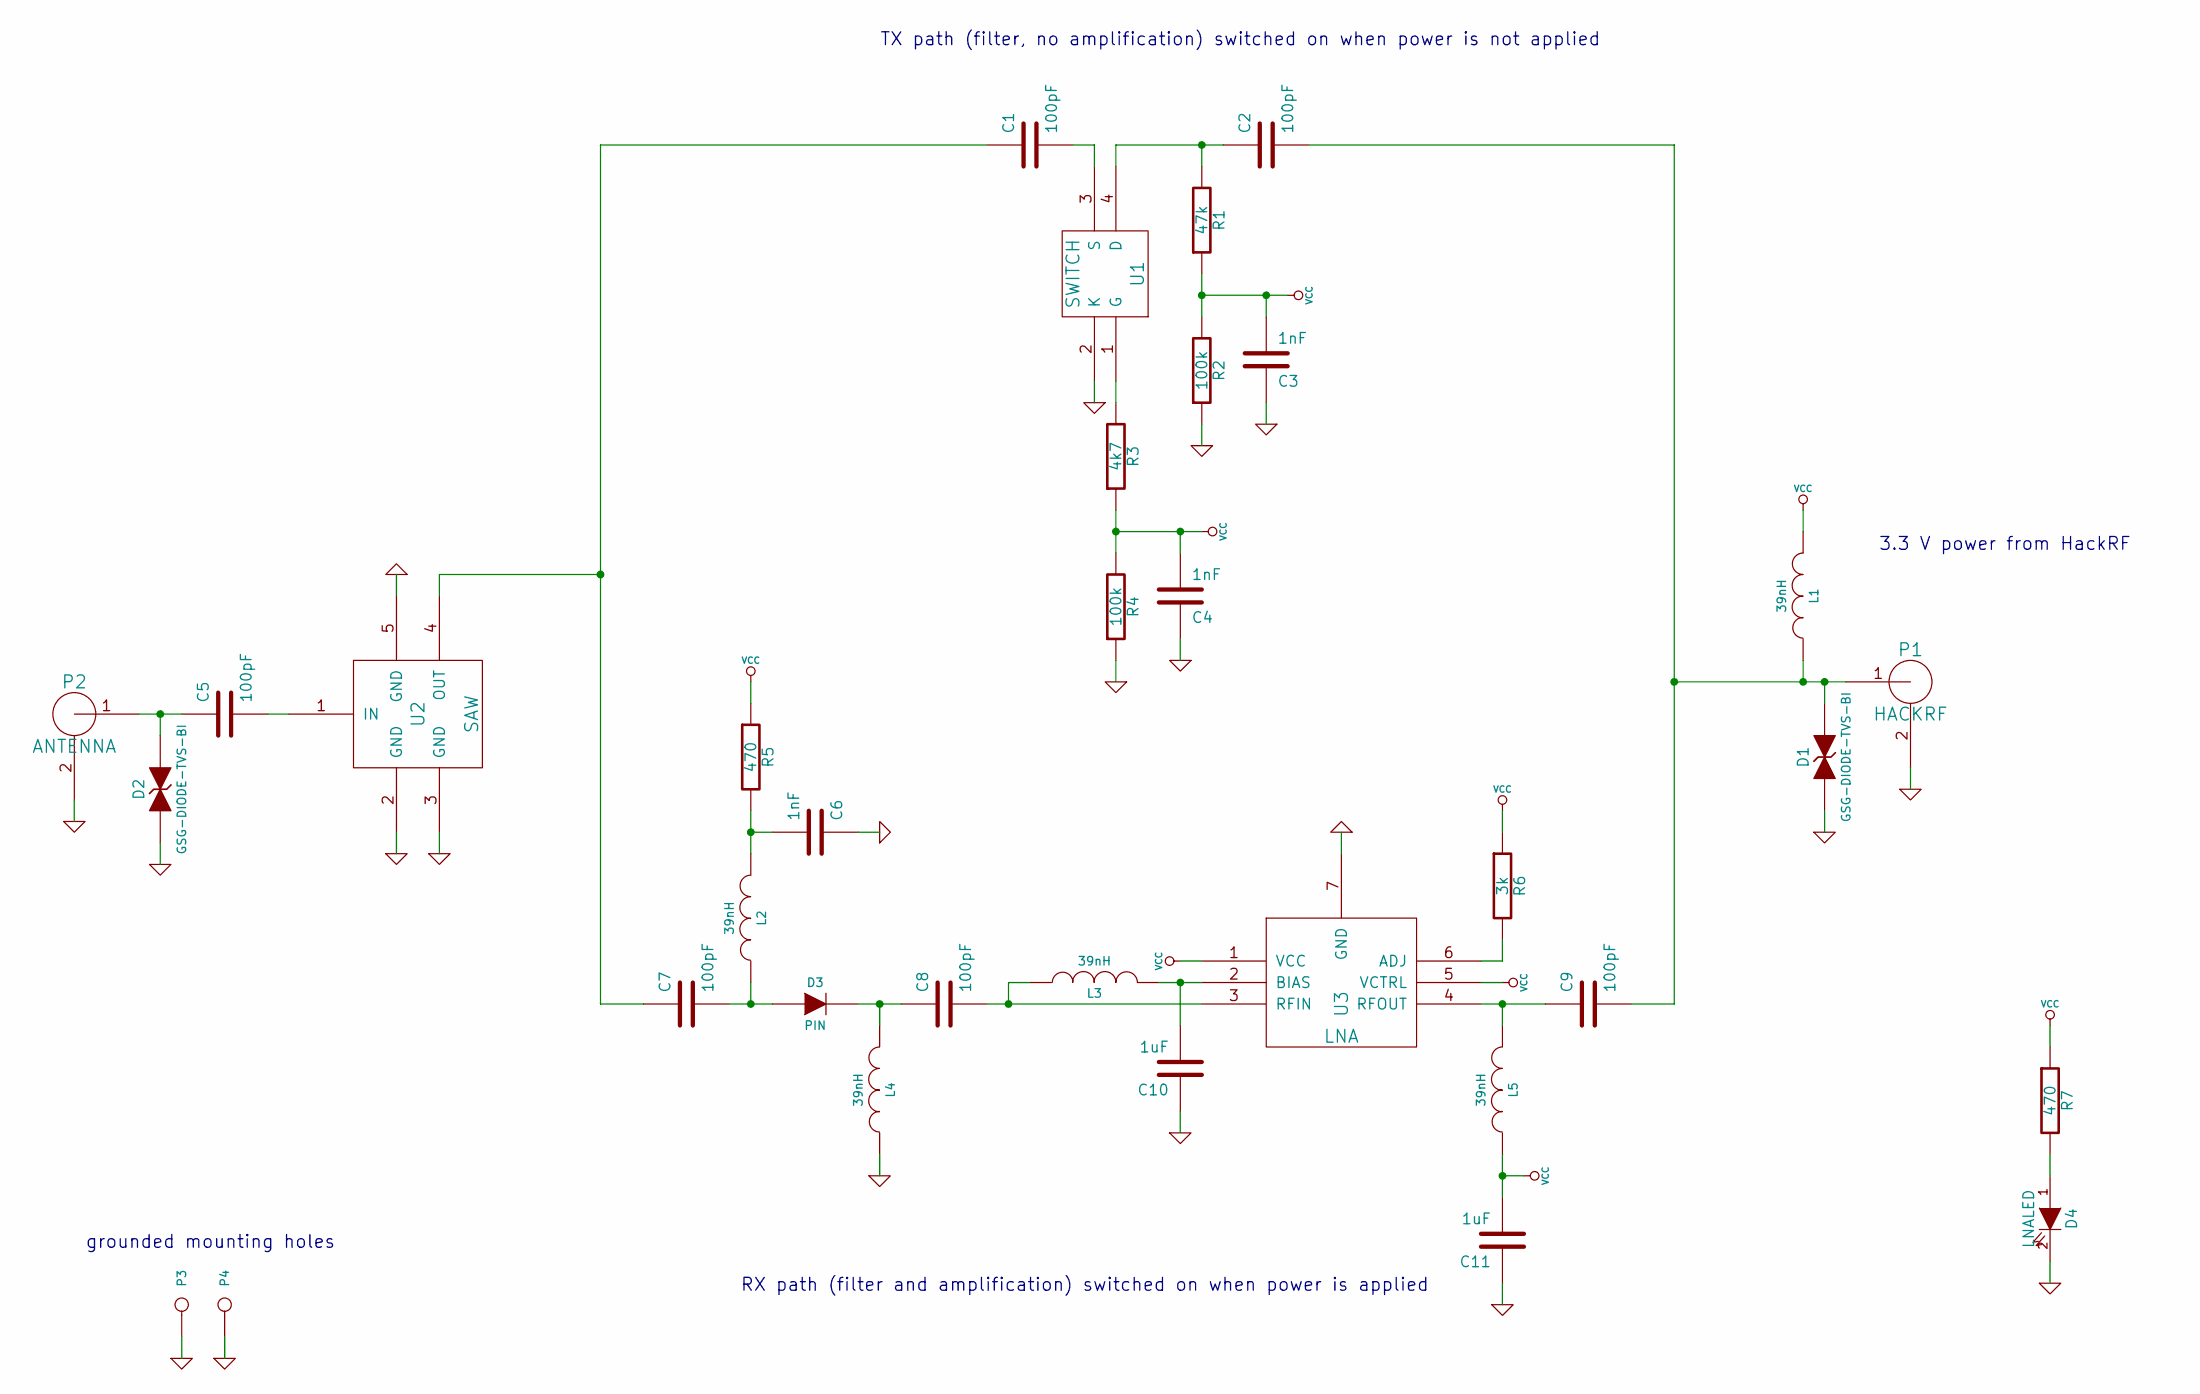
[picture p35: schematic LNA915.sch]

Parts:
C1, C2, C5, C7, C8, C9: 100pF; Part Number GRM1555C1H101JA01D
C3, C4, C6: 1nF; Part Number GRM155R71H102KA01D
C10, C11: 1uF; Part Number LMK105BJ105KV-F
D1, D2: GSG-DIODE-TVS-BI; Part Number LXES15AAA1-100
D3: PIN; Part Number BAP50-03
D4: LNALED; Part Number QTLP601C4TR
L1, L2, L3, L4, L5: 39nH; Part Number HK100539NJ-T
P1: HACKRF; Part Number CONSMA003.062
P2: ANTENNA; Part Number CONSMA003.062
P3, P4: CONN_1
R1: 47k; Part Number RMCF0402JT47K0
R2, R4: 100k; Part Number RMCF0402JT100K
R3: 4k7; Part Number RMCF0402JT4K70
R5, R7: 470; Part Number RMCF0402JT470R
R6: 3k; Part Number RMCF0402FT3K00
U1: SWITCH; Part Number BF1118,215
U2: SAW; Part Number FAR-F5QA-915M00-M2AK-J
U3: LNA; Part Number BGB 741L7ESD E6327

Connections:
GND: C3.1, C4.1, C6.1, C10.1, C11.1, D1.1 (A), D2.1 (A), D4.2 (K), L4.1, P1.2 (GND), P2.2 (GND), P3.1, P4.1, R2.1, R4.1, U1.2 (K), U2.2 (GND), U2.3 (GND), U2.5 (GND), U3.7 (GND)
unnamed: C8.1, D3.2 (K), L4.2
unnamed: C1.2, U1.3 (S)
unnamed: C2.1, R1.2, U1.4 (D)
unnamed: C7.2, D3.1 (A), L2.1
unnamed: R3.2, U1.1 (G)
unnamed: C5.1, D2.2 (K), P2.1 (RF)
unnamed: D4.1 (A), R7.2
unnamed: C1.1, C7.1, U2.4 (OUT)
unnamed: C6.2, L2.2, R5.2
unnamed: C5.2, U2.1 (IN)
unnamed: R6.2, U3.6 (ADJ)
unnamed: C2.2, C9.2, D1.2 (K), L1.1, P1.1 (RF)
unnamed: C9.1, L5.2, U3.4 (RFOUT)
unnamed: C8.2, L3.1, U3.3 (RFIN)
unnamed: C10.2, L3.2, U3.2 (BIAS)
VCC: C3.2, C4.2, C11.2, L1.2, L5.1, R1.1, R2.2, R3.1, R4.2, R5.1, R6.1, R7.1, U3.1 (VCC), U3.5 (VCTRL)

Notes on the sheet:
3.3 V power from HackRF
TX path (filter, no amplification) switched on when power is not applied
RX path (filter and amplification) switched on when power is applied
grounded mounting holes

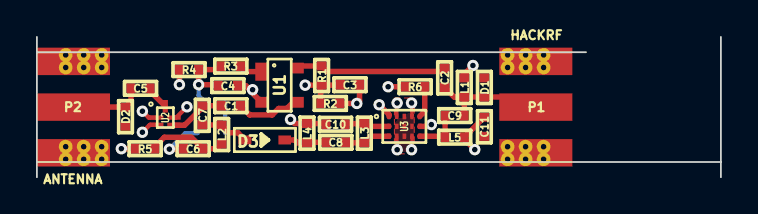
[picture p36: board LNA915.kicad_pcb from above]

Board: 4 copper layers, 38.0 x 7.8 mm, 32 parts (0 on the bottom side), 17 nets.

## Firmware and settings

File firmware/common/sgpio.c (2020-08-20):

/*
 * Copyright 2012 Jared Boone <jared@sharebrained.com>
 * Copyright 2013 Benjamin Vernoux <titanmkd@gmail.com>
 *
 * This file is part of HackRF.
 *
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
 * You should have received a copy of the GNU General Public License
 * along with this program; see the file COPYING.  If not, write to
 * the Free Software Foundation, Inc., 51 Franklin Street,
 * Boston, MA 02110-1301, USA.
 */

#include <libopencm3/lpc43xx/scu.h>
#include <libopencm3/lpc43xx/sgpio.h>

#include <hackrf_core.h>

#include <sgpio.h>

#ifdef RAD1O
static void update_q_invert(sgpio_config_t* const config);
#endif

void sgpio_configure_pin_functions(sgpio_config_t* const config) {
	scu_pinmux(SCU_PINMUX_SGPIO0, SCU_GPIO_FAST | SCU_CONF_FUNCTION3);
	scu_pinmux(SCU_PINMUX_SGPIO1, SCU_GPIO_FAST | SCU_CONF_FUNCTION3);
	scu_pinmux(SCU_PINMUX_SGPIO2, SCU_GPIO_FAST | SCU_CONF_FUNCTION2);
	scu_pinmux(SCU_PINMUX_SGPIO3, SCU_GPIO_FAST | SCU_CONF_FUNCTION2);
	scu_pinmux(SCU_PINMUX_SGPIO4, SCU_GPIO_FAST | SCU_CONF_FUNCTION2);
	scu_pinmux(SCU_PINMUX_SGPIO5, SCU_GPIO_FAST | SCU_CONF_FUNCTION2);
	scu_pinmux(SCU_PINMUX_SGPIO6, SCU_GPIO_FAST | SCU_CONF_FUNCTION0);
	scu_pinmux(SCU_PINMUX_SGPIO7, SCU_GPIO_FAST | SCU_CONF_FUNCTION6);
	scu_pinmux(SCU_PINMUX_SGPIO8, SCU_GPIO_FAST | SCU_CONF_FUNCTION6);
	scu_pinmux(SCU_PINMUX_SGPIO9, SCU_GPIO_FAST | SCU_CONF_FUNCTION7);
	scu_pinmux(SCU_PINMUX_SGPIO10, SCU_GPIO_FAST | SCU_CONF_FUNCTION6);
	scu_pinmux(SCU_PINMUX_SGPIO11, SCU_GPIO_FAST | SCU_CONF_FUNCTION6);
	scu_pinmux(SCU_PINMUX_SGPIO12, SCU_GPIO_FAST | SCU_CONF_FUNCTION0); /* GPIO0[13] */
	scu_pinmux(SCU_PINMUX_SGPIO13, SCU_GPIO_FAST | SCU_CONF_FUNCTION4);	/* GPIO5[12] */
	scu_pinmux(SCU_PINMUX_SGPIO14, SCU_GPIO_FAST | SCU_CONF_FUNCTION4);	/* GPIO5[13] */
	scu_pinmux(SCU_PINMUX_SGPIO15, SCU_GPIO_FAST | SCU_CONF_FUNCTION4);	/* GPIO5[14] */

	sgpio_cpld_stream_rx_set_q_invert(config, 0);
    hw_sync_enable(0);

	gpio_output(config->gpio_rx_q_invert);
	gpio_output(config->gpio_hw_sync_enable);
}

void sgpio_set_slice_mode(
	sgpio_config_t* const config,
	const bool multi_slice
) {
	config->slice_mode_multislice = multi_slice;
}

/*
 SGPIO0 to 7 = DAC/ADC data bits 0 to 7 (Nota: DAC is 10bits but only bit9 to bit2 are used bit1 & 0 are forced to 0 by CPLD)
 ADC=> CLK x 2=CLKx2 with CLKx2(0)rising=D0Q, CLKx2(1)rising=D1I (corresponds to CLK(0)falling+tD0Q=>D0Q, CLK(1)rising+tDOI=>D1I, CLK(1)falling+tD0Q=>D1Q, CLK(1)rising+tDOI=>D2I ...)
 tDOI(CLK Rise to I-ADC Channel-I Output Data Valid)=7.4 to 9ns, tD0Q(CLK Fall to Q-ADC Channel-Q Output Data Valid)=6.9 to 9ns
 DAC=> CLK x 2=CLKx2 with CLKx2(0)rising=Q:N-2, CLKx2(1)rising=I:N-1(corresponds to CLK(0)rising=>Q:N-2, CLK(0)falling I:N-1, CLK(1)rising=>Q:N-1, CLK(1)falling I:N ...)
 tDSI(I-DAC Data to CLK Fall Setup Time)=min 10ns, tDSQ(Q-DAC Data to CLK Rise Setup Time)=min 10ns
 
 SGPIO8 Clock Input (External Clock)
 SGPIO9 Capture Input (Capture/ChipSelect, 1=Enable Capture, 0=Disable capture)
 SGPIO10 Disable Output (1/High=Disable codec data stream, 0/Low=Enable codec data stream)
 SGPIO11 Direction Output (1/High=TX mode LPC43xx=>CPLD=>DAC, 0/Low=RX mode LPC43xx<=CPLD<=ADC)
*/
void sgpio_configure(
	sgpio_config_t* const config,
	const sgpio_direction_t direction
) {
	// Disable all counters during configuration
	SGPIO_CTRL_ENABLE = 0;

    // Set SGPIO output values.
	const uint_fast8_t cpld_direction =
		(direction == SGPIO_DIRECTION_TX) ? 1 : 0;
    SGPIO_GPIO_OUTREG =
          (cpld_direction << 11) /* 1=Output SGPIO11 High(TX mode), 0=Output SGPIO11 Low(RX mode)*/
        | (1L << 10)	// disable codec data stream during configuration (Output SGPIO10 High)
		;
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

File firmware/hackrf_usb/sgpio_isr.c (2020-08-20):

/*
 * Copyright 2012 Jared Boone
 * Copyright 2013 Benjamin Vernoux
 *
 * This file is part of HackRF.
 *
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
 * You should have received a copy of the GNU General Public License
 * along with this program; see the file COPYING.  If not, write to
 * the Free Software Foundation, Inc., 51 Franklin Street,
 * Boston, MA 02110-1301, USA.
 */

#include "sgpio_isr.h"

#include <libopencm3/lpc43xx/sgpio.h>

#include "usb_bulk_buffer.h"

void sgpio_isr_rx() {
	SGPIO_CLR_STATUS_1 = (1 << SGPIO_SLICE_A);

	uint32_t* const p = (uint32_t*)&usb_bulk_buffer[usb_bulk_buffer_offset];
	__asm__(
		"ldr r0, [%[SGPIO_REG_SS], #44]\n\t"
		"str r0, [%[p], #0]\n\t"
		"ldr r0, [%[SGPIO_REG_SS], #20]\n\t"
		"str r0, [%[p], #4]\n\t"
		"ldr r0, [%[SGPIO_REG_SS], #40]\n\t"
		"str r0, [%[p], #8]\n\t"
		"ldr r0, [%[SGPIO_REG_SS], #8]\n\t"
		"str r0, [%[p], #12]\n\t"
		"ldr r0, [%[SGPIO_REG_SS], #36]\n\t"
		"str r0, [%[p], #16]\n\t"
		"ldr r0, [%[SGPIO_REG_SS], #16]\n\t"
		"str r0, [%[p], #20]\n\t"
		"ldr r0, [%[SGPIO_REG_SS], #32]\n\t"
		"str r0, [%[p], #24]\n\t"
		"ldr r0, [%[SGPIO_REG_SS], #0]\n\t"
		"str r0, [%[p], #28]\n\t"
		:
		: [SGPIO_REG_SS] "l" (SGPIO_PORT_BASE + 0x100),
		  [p] "l" (p)
		: "r0"
	);
	usb_bulk_buffer_offset = (usb_bulk_buffer_offset + 32) & usb_bulk_buffer_mask;
}

void sgpio_isr_tx() {
	SGPIO_CLR_STATUS_1 = (1 << SGPIO_SLICE_A);

	uint32_t* const p = (uint32_t*)&usb_bulk_buffer[usb_bulk_buffer_offset];
	__asm__(
		"ldr r0, [%[p], #0]\n\t"
		"str r0, [%[SGPIO_REG_SS], #44]\n\t"
		"ldr r0, [%[p], #4]\n\t"
		"str r0, [%[SGPIO_REG_SS], #20]\n\t"
		"ldr r0, [%[p], #8]\n\t"
		"str r0, [%[SGPIO_REG_SS], #40]\n\t"
		"ldr r0, [%[p], #12]\n\t"
		"str r0, [%[SGPIO_REG_SS], #8]\n\t"
		"ldr r0, [%[p], #16]\n\t"
		"str r0, [%[SGPIO_REG_SS], #36]\n\t"
		"ldr r0, [%[p], #20]\n\t"
		"str r0, [%[SGPIO_REG_SS], #16]\n\t"
		"ldr r0, [%[p], #24]\n\t"
		"str r0, [%[SGPIO_REG_SS], #32]\n\t"
		"ldr r0, [%[p], #28]\n\t"
		"str r0, [%[SGPIO_REG_SS], #0]\n\t"
		:
		: [SGPIO_REG_SS] "l" (SGPIO_PORT_BASE + 0x100),
		  [p] "l" (p)
		: "r0"
	);
	usb_bulk_buffer_offset = (usb_bulk_buffer_offset + 32) & usb_bulk_buffer_mask;
}

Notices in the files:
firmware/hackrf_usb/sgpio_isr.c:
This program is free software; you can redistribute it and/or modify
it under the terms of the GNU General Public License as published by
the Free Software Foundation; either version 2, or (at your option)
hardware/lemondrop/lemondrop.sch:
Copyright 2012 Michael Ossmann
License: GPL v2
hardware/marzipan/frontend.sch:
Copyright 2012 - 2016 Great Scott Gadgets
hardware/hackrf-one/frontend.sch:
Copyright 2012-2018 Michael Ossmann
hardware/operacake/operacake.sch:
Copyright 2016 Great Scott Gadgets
